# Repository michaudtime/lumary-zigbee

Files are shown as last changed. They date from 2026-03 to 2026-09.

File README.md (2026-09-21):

# Lumary Zigbee Controller

Replaces the Tuya WiFi controller inside a **Lumary 6" RGBAI recessed light** with an **ESP32-H2 Zigbee controller**, enabling:

- Direct Zigbee binding to Inovelli Blue Series switches (hub-independent on/off, dimming, scene control)
- 6 built-in lighting effects on the accent ring, with per-scene parameters stored on-device
- Zigbee OTA firmware updates via Zigbee2MQTT

## Hardware

| Component | Part |
|---|---|
| Controller | **lumary-brain rev A** — custom ESP32-H2-MINI-1 board, drop-in for the stock `KOK-AH-A172C` (see `hardware/`) |
| Target light | [Lumary Smart RGBAI Recessed Light 6"](https://www.lumarysmart.com/products/lumary-smart-recessed-light-with-gradient-auxiliary-light) |
| Switch | [Inovelli Blue Series 2-1 Zigbee](https://inovelli.com/products/zigbee-matter-blue-series-smart-2-1-on-off-dimmer-switch) |

### The two light sources

The fixture has two independent sources, and the firmware drives them as **two separate Zigbee
endpoints**, so Home Assistant sees two independent light entities rather than one:

| Source | Hardware | Driven by |
|---|---|---|
| Outer "gradient" ring | 62-pixel 5 V 3535 **RGBIC** strip, 3 colour bytes/pixel (no white die) | One data line, NZR over SPI |
| Inner white ring | 96 LEDs, 12 series × 4 parallel per colour, 2700 K + 6500 K | Two low-side PWM channels steering the driver's 380 mA |

The external `L-SD8E1` driver supplies **36.63 V constant-current** (inner white anode) and **4.7 V** (ring + logic). The board never sources the white current — it gates and steers it.

| Entity | Endpoint | Controls |
|---|---|---|
| `light.<name>_downlight` | 1 | on/off, brightness, colour temperature 2700–6500 K |
| `light.<name>_ring` | 2 | on/off, brightness, xy colour, the six effects |

> **Upgrading an already-paired fixture:** adding the second endpoint changes the device
> descriptor, and Zigbee2MQTT caches endpoints from the interview, so an already-paired fixture
> must be **re-interviewed** (Z2M frontend → device → Re-interview, or publish to
> `zigbee2mqtt/bridge/request/device/interview`) before the ring entity works. This has never been
> observed on hardware, so exactly what you'll see beforehand is unconfirmed either way -- expect
> the ring entity to be missing entirely, or present but unresponsive, until the re-interview is
> done. Newly paired fixtures just work.
>
> It is also no longer easy to check: both fixtures in service have already crossed this descriptor
> change, and a fixture that has crossed it cannot show you the before. Settling it would mean
> deliberately pairing a board on pre-2.0.0 firmware and upgrading it while watching -- worth doing
> when the remaining rev A boards are brought up, or this hedge should simply stay as written.

### Wiring (rev A board)

| ESP32-H2 Pin | Signal | Destination |
|---|---|---|
| GPIO 11 (SPI2 MOSI) | Ring data → 3.3→4.7 V buffer | `CN1.DIM` (ring DIN) |
| GPIO 4 | PWM cold white → Q1 gate | `CN1.CW-` (6500 K return) |
| GPIO 5 | PWM warm white → Q2 gate | `CN1.WW-` (2700 K return) |
| GPIO 9 | BOOT button | Bench download / BLE OTA |

> **Pin note:** GPIO 2/3/8/9/25 are ESP32-H2 strapping pins. The white PWM channels use GPIO 4/5 on rev A so the MOSFET gate pulldowns can't hold a strapping pin low at reset — the Super Mini prototype's GPIO 2/3 assignment does not carry over.

> **Level shifting:** the ring runs on the 4.7 V rail, so its data line is buffered up from 3.3 V by a `74AHCT1G125` (AHCT accepts 3.3 V as a logic high).

## Why SPI instead of RMT for the ring?

On ESP32-H2, the RMT peripheral conflicts with the Zigbee radio. Instead, SPI2 bit-encodes the single-wire NZR protocol: each NZR bit becomes 3 SPI bits (`1 → 110`, `0 → 100`) at 2.4 MHz, producing a valid 800 kHz signal on MOSI. The encoder lives in `src/pixel_encode.h`, deliberately free of ESP-IDF headers so it can be unit-tested on the host.

## Built-in Effects

These belong to the **Accent Ring** entity only — the Downlight has no effects, just on/off,
brightness and colour temperature.

| # | Name | Description |
|---|---|---|
| 1 | Warm Gradient | Warm→cool sweep rotating around the ring |
| 2 | Color Gradient | Multi-hue gradient rotating around ring |
| 3 | Breathing | Outer ring pulses in/out |
| 4 | Color Cycle | Full HSV hue rotation |
| 5 | Chase | Single lit segment travels around ring |
| 6 | Nightlight | Dim warm white outer ring only |

> **Changed in this version:** `static_white` and `static_color` are gone from the effect list.
> White is now the separate Downlight entity, and a solid ring colour is `effect: none` with a
> colour set. Automations naming either of the two removed effects need updating. Stored scenes
> are reseeded automatically — the NVS schema version bump discards the old indices rather than
> misreading them.

## Switch Control (Hub-Independent)

| Inovelli action | Behavior |
|---|---|
| 1× tap | On/Off |
| Hold up/down | Brightness |
| 2× tap up | Next effect — **via hub automation**, see below |
| 2× tap down | Previous effect — **via hub automation** |

On/off and dimming use direct Zigbee binding — **no hub required**, and they keep working if the
coordinator is down. With two fixture endpoints, the switch binds to both:

```
Bind from the Inovelli's endpoint 2 (the paddle) to BOTH fixture endpoints,
clusters genOnOff and genLevelCtrl:

  switch ep2 -> fixture ep1   (downlight)
  switch ep2 -> fixture ep2   (accent ring)
```

One tap down turns both sources off; one tap up brings both back at their own levels and colours.
This works because the Inovelli sends discrete `On`/`Off` rather than `Toggle` — verified on the
hardware. Under `Toggle`, two endpoints that had drifted into different states would diverge
further on every tap instead of converging. "Downlight only" is a Home Assistant action rather
than a switch action; remove the second binding if you would rather the ring ignored the switch.

> **Effect stepping is not hub-independent, and cannot be.** The Inovelli's multi-tap events are
> manufacturer-specific and go to the coordinator rather than to a bound light, so nothing the
> light does could make 2× tap work over pure binding. The automation reads the current
> `effect_select` and writes the next one. Not yet verified end to end (plan Task 6.4).

## Selecting an effect

Effect selection rides a **manufacturer-specific cluster (`0xFC00`)**, because nothing standard can
carry it: the Scenes cluster stores colour and level but knows nothing about an effect type, and
the Identify trigger-effects have no hook in the Arduino Zigbee library.

Install [`z2m/lumary-brain-revA.js`](z2m/lumary-brain-revA.js) into Z2M's `data/external_converters/`
and restart. Without the converter the light still works normally — the effects are simply
unreachable.

The converter exposes the effects as the **Accent Ring entity's native Home Assistant effect
list**, so they appear in the effect dropdown of the ring's light card itself rather than as a
separate entity:

```yaml
service: light.turn_on
target: {entity_id: light.lumary_kitchen_ring}
data: {effect: color_cycle}
```

That also means HA scene snapshots capture the running effect, and voice assistants can select one.
The current effect reads back as `state_attr('light.lumary_kitchen_ring', 'effect')`.

| Value | Meaning |
|---|---|
| `warm_gradient` … `nightlight` | One of the six built-in effects, in `EffectType` order |
| `none` | Not running an effect — showing a plain colour |

Setting a colour on the ring **exits the effect** and shows that colour instead, which reads back
as `none`. Selecting `none` does the same thing without changing the colour. Brightness continues
to scale whatever effect is running.

The selected effect persists across power cuts (NVS); `none` deliberately does not, so a power
cycle comes back to the stored effect.

> The Identify trigger-effects that Z2M's stock `effect` dropdown drives (`blink`, `breathe`,
> `okay`, …) are **switched off** in the converter, along with `power_on_behavior`. Both are on by
> default in `light()`, and this firmware implements neither — leaving them on would put controls in
> the light card that quietly do nothing. See `effect: false` / `powerOnBehavior: false` there.

> **Stepping through effects from the wall switch** is done by a hub automation, not by the light:
> read the current effect and set the next one. The Inovelli's multi-tap events go to the
> coordinator rather than to a bound light, so a hub is in the loop regardless.

Scene *storage* exists — 16 NVS slots, seeded with the defaults in `src/effect_params.h` — but
editing them is **not implemented**. There is no Add Scene support; `scene_store_save()` is only
called to seed defaults at first boot. Changing an effect's colour, speed or brightness
permanently is a future change.

## OTA Updates

> **Re-flashing a fixture that was already paired?** See "Upgrading an already-paired fixture"
> above — after this update it needs a Z2M **re-interview** before the ring entity works, or the
> upgrade will look broken even though it succeeded.

**Primary:** Zigbee OTA via Zigbee2MQTT.

Three things must all be true, and each one fails differently:

| Requirement | Symptom when missing |
|---|---|
| Firmware registers an OTA client | Device never asks; nothing in the Z2M log |
| Converter declares `ota: true` | **No `update` entity at all** in Home Assistant |
| Z2M can find the image via an index | Update entity exists; update fails `No image currently available` |

> **Z2M does not discover firmware by scanning a folder.** Copying a `.zigbee` file into `data/ota/`
> accomplishes nothing on its own — Z2M reads an *index* that describes the image, pointed at by
> `ota.zigbee_ota_override_index_location` in `configuration.yaml`. `scripts/gen-ota-index.py`
> generates one; see "Building an OTA image" below.

> **`ota` is a definition property, not a modern extend.** There is no `m.ota()` in
> zigbee-herdsman-converters, and using one makes Z2M reject the entire converter as invalid at load
> time. It goes on the definition object alongside `onEvent`.

**There is no fallback.** A BLE OTA path was planned — `PIN_BLE_OTA_BUTTON` is still defined in
`src/config.h` — but it was never implemented, and nothing references that pin. Do not count on it
for a fixture already in the ceiling: if Zigbee OTA cannot reach a light, the only recovery is
physical access to the USB port. Getting Zigbee OTA verified from an installed location is
consequently the gate on signing off the board (plan task 6.4), not a nice-to-have.

### Scheduled updates and automatic recovery (2.1.0 and later)

**Start updates with *schedule*, not *update*:**

```
topic:   zigbee2mqtt/bridge/request/device/ota_update/schedule
payload: {"id": "Loft Overhead Light"}
```

> **This means not using the Install button on Home Assistant's update card.** That button is the
> `ota_update/update` path: Zigbee2MQTT pushes an image notify at the fixture and waits for it to
> answer, which for a fixture a floor away from the coordinator typically ends in
> `OTA update of '<name>' failed (Device didn't respond to OTA request)` — a failure that says
> nothing about the image or the index. `schedule` parks the request instead and lets the fixture
> collect it on its own next query, which is what the recovery loop below is built around. Seen
> 2026-09-21 on the loft fixture: Install failed this way, the same image then installed from a
> schedule.
>
> `check`, `update` and `schedule` share one per-device lock, so a `schedule` sent while either of
> the others is still running is rejected with
> `OTA update or check for update already in progress for '<name>'`. Wait for the first to finish
> and send it again.

The fixture queries for an image shortly after it joins the network at boot, then hourly. A
scheduled update starts on whichever of those queries comes next, and Zigbee2MQTT keeps it
scheduled if it fails. Combined with the firmware's recovery this makes an update self-healing:

1. If a download aborts, or stalls for 3 minutes, the fixture saves its light state, restarts
   (the light blinks for about a second, then comes back as it was), and rejoins.
2. On rejoin it queries for an image, and the still-scheduled update starts again from the
   beginning.
3. When it succeeds, the fixture restarts into the new version and comes back **off** -- light
   state is only carried across a recovery restart, not across the update's own restart -- and
   Zigbee2MQTT clears the schedule.

The restart itself backs off on repeated recoveries: the first two consecutive recoveries restart
at once, but from the third the restart waits 5 minutes, doubling each time up to an hour, so an
image that fails the same way every time cannot make a fixture blink every few seconds. It never
stops retrying on its own -- `unschedule` is what stops it.

The restart is required: the Arduino Zigbee library never resets its OTA state after an abort, so
without it every retry fails `INVALID_IMAGE` two blocks in. To stop a fixture retrying an image that
can never succeed, send the same payload to `.../ota_update/unschedule`. Each recovery is logged on
the serial console with a running count.

**Fixtures on firmware older than 2.1.0** have no automatic recovery: after a failed update, power-
cycle the fixture before retrying. From Home Assistant, via its Inovelli switch: turn the switch
off, set its Smart Bulb Mode to `Disabled` (the switch is off, so the load loses power), wait ~15 s,
then set Smart Bulb Mode back to `Smart Bulb Mode` (full power returns and the fixture boots).

### Building an OTA image

The device registers an OTA client at startup and queries for an image once it
joins, then hourly. The coordinator only offers images numbered **above** the
running version, so the version block in `src/version.h` must be bumped and the
same `ZB_FW_VERSION` passed as `--file-version` below — if they disagree, the
update silently never appears.

> **The tool was renamed and its CLI changed.** Espressif's `tools/ota_image_tool.py`
> is gone; it is now `tools/image_builder_tool/image_builder_tool.py`, it takes short
> flags rather than the old long ones, and the firmware is supplied as a `--tag`
> sub-element rather than a positional argument. There is no `create` subcommand, and
> the output filename is generated for you rather than given. Verified 2026-08-18.

```bash
# Get the tool
mkdir -p build/ota && curl -sSL -o build/ota/image_builder_tool.py   https://raw.githubusercontent.com/espressif/esp-zigbee-sdk/main/tools/image_builder_tool/image_builder_tool.py

# Build firmware (bump the version block in src/version.h first)
pio run -e esp32h2

# Wrap as an OTA image. -m/-i come from src/config.h (ZB_MANUFACTURER_CODE,
# ZB_IMAGE_TYPE); -v must equal ZB_FW_VERSION. Tag 0x0000 is the upgrade image.
cd build/ota && python image_builder_tool.py   -m 0x1001   -i 0x0001   -v 0x02000000   -s 2   -g "LumaryZigbee"   --tag 0x0000 ../../.pio/build/esp32h2/firmware.bin
```

The output is named from the three identifiers rather than chosen — for the values above,
`1001-0001-02000000-ota-file.zigbee`.

Then generate the index Z2M actually reads. It takes the manufacturer code, image type, file version
and header string out of the image itself rather than from arguments, so the index cannot disagree
with the file it describes:

```bash
python scripts/gen-ota-index.py build/ota/1001-0001-02000000-ota-file.zigbee
```

Copy **both** the `.zigbee` image and the generated `index.json` into Z2M's `data/ota/` folder, then
point `configuration.yaml` at the index and restart Z2M:

```yaml
ota:
  zigbee_ota_override_index_location: ota/index.json
```

Both paths are relative to the **Z2M data directory** — the index's own location, and the `url`
inside it naming the image. Verified end to end 2026-08-18 against Z2M 2.13.0: no http(s) URL and no
absolute path is needed for a locally served image.

> **The `url` is relative to the data directory, not to the index that contains it.** With the
> layout above the index lives at `data/ota/index.json` and the image sits beside it, so the `url`
> still needs the `ota/` prefix — `ota/foo.zigbee`, not `foo.zigbee`. `gen-ota-index.py` adds it.
>
> Getting this wrong is worth recognising, because it does not look like a path problem.
> `ota_update/check` reads index *metadata* only, so it reports `update_available: true` and Home
> Assistant offers the update quite happily. Only `ota_update/update` opens the file, and it reports
> the failure as **`No image currently available`** — the same message you get with no index at all.
> The real cause appears only in Z2M's debug log:
>
> ```
> zh:controller:ota: Reading firmware image from 'foo.zigbee'
> ENOENT: no such file or directory, open '/config/zigbee2mqtt/foo.zigbee'
> ```

Z2M caches the last OTA check, so after installing an index it will keep reporting the device as up
to date until it re-checks — on the next device announce, hourly, or immediately if you ask:

```
topic:   zigbee2mqtt/bridge/request/device/ota_update/check
payload: {"id": "Overhead light test"}
```

For a one-off test you can skip the index entirely and name the file in the update request, which is
useful for confirming the image itself is good before troubleshooting configuration:

```
topic:   zigbee2mqtt/bridge/request/device/ota_update/update
payload: {"id": "Overhead light test", "url": "ota/1001-0001-02000000-ota-file.zigbee"}
```

`build/` is git-ignored, so neither the tool, the image, nor the index is committed.

## Build & Flash

> **Re-flashing a fixture that was already paired?** See "Upgrading an already-paired fixture"
> above — after this update it needs a Z2M **re-interview** before the ring entity works, or the
> upgrade will look broken even though it succeeded.

> **Windows:** run `pio` from **PowerShell or cmd**, not Git Bash. This platform
> version installs its toolchain via `idf_tools.py`, which aborts with
> `ERROR: MSys/Mingw is not supported` under Git Bash. Building also needs
> Windows long-path support enabled (`LongPathsEnabled = 1`).
>
> `--target upload` fails differently and much more confusingly under Git Bash:
> esptool's progress bar is drawn with box-drawing characters, stdout falls back
> to **cp1252**, and the whole upload dies on `UnicodeEncodeError: 'charmap'
> codec can't encode characters` — after sitting silent for ~6 minutes, with the
> traceback replacing whatever the real error was. The board is fine; nothing was
> written. From PowerShell the same flash takes ~18 s. If you must run it from a
> shell with a non-UTF-8 codepage, `chcp 65001` and `PYTHONIOENCODING=utf-8`
> clear it (observed 2026-09-21).

```bash
# Install PlatformIO CLI if needed
pip install platformio

# Build
pio run -e esp32h2

# Flash
pio run -e esp32h2 --target upload

# Serial monitor
pio device monitor
```

## Project Structure

```
src/
  config.h          — Pin definitions, constants
  color.h           — CRGB struct, HSV conversion, color math
  pixel_encode.h    — NZR-over-SPI bit encoder (hardware-free, unit-tested)
  led_driver.h/.cpp — SPI2 ring driver + LEDC CW/WW PWM
  effect_params.h   — EffectType enum, EffectParams struct
  effects.h/.cpp    — 6 effect implementations + lookup table
  scene_store.h/.cpp — NVS scene persistence
  zigbee_light.h/.cpp — Zigbee clusters for both endpoints, and the OTA client
  brightness.h      — CIE 1931 lightness curve, generated tables
  main.cpp          — Setup, loop, watchdog
test/
  test_brightness/   — Host unit tests for the perceptual curve
  test_identify/     — Host unit tests for the identify overlay
  test_light_state/  — Host unit tests for the Zigbee -> fixture translation
  test_pixel_encode/ — Host unit tests for pixel encoding + color math
  test_version/      — Host unit tests for the version block
z2m/
  lumary-brain-revA.js — Z2M external converter
  test/             — Converter tests (stubbed, `node z2m/test/converter.test.mjs`)
hardware/
  kicad/            — Board design (build_board.py generates the .kicad_pcb)
  bom.csv, calcs.md, schematic-nets.md
docs/
  spec.md           — Hardware + software design specification
  plan.md           — Implementation plan
  superpowers/      — Board replacement spec, plan, and Phase 0 measurements
```

## Tests

Hardware-independent logic (pixel encoding, colour math) has host-side unit tests:

```bash
scripts\run-native-tests.bat
```

> PlatformIO's `platform = native` expects a gcc toolchain; this script compiles the
> same tests with the MSVC Build Tools that are installed instead. `pio test -e native`
> works as-is on a machine with gcc.

The Z2M converter has its own suite, covering the effect names, their wire indices and the
exposes Home Assistant discovers from them. It stubs the `zigbee-herdsman-converters` imports,
so it needs nothing installed but Node:

```bash
node z2m/test/converter.test.mjs
```

## Status

- [x] Design spec
- [x] Implementation plan
- [x] Task 1: Project scaffold
- [x] Task 2: Color utilities
- [x] Task 3: LED driver
- [x] Task 4: Scene storage
- [x] Task 5: Effects engine
- [x] Task 6: Zigbee basics
- [x] Task 7: Zigbee color + effect selection
- [x] Task 8: Zigbee OTA
- [ ] Task 9: BLE OTA fallback -- won't do (decided 2026-08-19); see "OTA Updates" above
- [ ] Task 10: Integration + validation -- bench-verified end to end
      (`docs/superpowers/plans/2026-08-18-bench-verification.md`, §§1-9), and **signed off from an
      installed ceiling location 2026-09-19**: binding to the Inovelli confirmed from the loft at
      LQI 126-138, and a real over-the-air update completed from there (Task 6.4 in
      `docs/superpowers/plans/2026-08-01-brain-replacement-board.md`). Still open: the
      already-paired-fixture upgrade path -- see the note under "Two entities" above, which now
      needs a fixture deliberately left on pre-2.0.0 firmware to observe at all
      (RSSI, thermals, a real OTA from there)

## License

MIT

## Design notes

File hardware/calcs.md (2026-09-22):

# Lumary Brain Board — Engineering Calculations

Inputs from `docs/superpowers/research/phase0-measurements.md`.
Rails: `+36V` = 36.63 V constant-current (380 mA), `+4V7` = 4.7 V logic/ring, `GND`.

---

## Task 1.1 — Power-path calculations

### 3.3 V rail (ESP32-H2-MINI-1)
- Design load: **200 mA** headroom (H2 active radio + flash-write bursts; steady draw is lower).
- LDO dissipation:
  - from USB 5 V:  (5.0 − 3.3) × 0.20 = **0.34 W**
  - from +4V7:     (4.7 − 3.3) × 0.20 = **0.28 W**
- Dropout requirement: at +4V7 in, LDO dropout must be **< 1.4 V @ 200 mA** → pick a low-dropout part (rules out marginal AMS1117-class at this headroom).
- Thermal: 0.34 W in SOT-23-5 (θJA ≈ 200 °C/W) → ~68 °C rise worst case → OK with a modest copper pour.
- **VERDICT: PASS** (≤ 0.5 W). LDO from a diode-OR of (+4V7, USB-VBUS) so the board runs installed *and* boots on USB alone at the bench.

### Outer-ring current budget (risk R3)
- 62 px, 3535 RGBIC (RGB). Per-pixel full-white ≈ 3 × ~6 mA ≈ **~18 mA** (3535 is lower-power than 5050); worst-case ≈ 62 × ~20 mA ≈ **1.24 A** at ~5 V.
- The driver's `+4V7` rail spare capacity is **unknown** (input 24 W − 13.6 W white ≈ ~10 W gross, minus efficiency → order of ~1 A, unconfirmed).
- **Conclusion:** full-brightness all-white on 62 px would exceed the rail. **Firmware brightness cap is mandatory** (already present as `BENCH_BRIGHTNESS`). Quantify the safe average once the rail's real limit is measured; keep the cap conservative until then.
- **MEASURED 2026-08-15** (rev A, bench supply on `+4V7`, module powered from USB so excluded):
  - 62 px dark, quiescent: **0.040 A** (~0.65 mA/px)
  - 62 px at `(24,14,14)` (`MAX_BRIGHTNESS` 24, sat 40%): **0.122 A**
  - → LED current 0.082 A for 52 of 765 channel-units, i.e. **~1.5 mA per unit across the ring**
  - → extrapolated full white at full brightness: **1.21 A**, against the 1.24 A predicted above.
    The per-pixel 3535 estimate is **confirmed to within 3%**.
  - → full white at the current cap of 24: **~0.15 A**, not the ~0.55 A previously assumed.
  - **Implication:** against the 0.74 A trace limit the cap could rise to roughly 100 on paper.
    Not acted on — the measurement is open-air, the fixture is a sealed can, and the driver's
    `+4V7` rail spare capacity is still unmeasured (see R3 above). Revisit after plan Task 6.4.
  - **Rev B update:** `+4V7`/`+4V7_IN` were widened to 0.5 mm where the layout allowed it (see
    "As-built trace widths (rev B)" below), but three short necks could not be widened without a
    reroute and stay at 0.2 mm. **A path is limited by its narrowest section, so the ring supply's
    trace limit is still ~0.74 A — the widening did not raise it.** It bought lower resistance
    (~60 mΩ, ~35 mV at the 0.55 A the path actually draws), not headroom, and it does **not**
    change this brightness-cap discussion: the 0.74 A ceiling above is unchanged.

### Inner white sink (from P0.5)
- Headroom ≈ 0.6 V, sink current 380 mA → **≈ 0.23 W per channel**, one color full at a time.
- **VERDICT: PASS**, trivial thermals (see Task 1.2).
- **MEASURED 2026-08-15** (rev A on the real L-SD8E1, `Q2` at 380 mA/100% duty for 15 min,
  thermal camera, 23.3 °C ambient, open air):
  - `Q2` **37 °C** (Δ13.7 °C) → effective **θJA ≈ 60 °C/W**, against ~250 °C/W for a bare SOT-23
    in free air. The copper pour around Q1/Q2 is carrying the heat as hoped.
  - `U2` (LDO) **40 °C** (Δ16.7 °C) — the hottest point on the whole board, not the white sinks.
    Measured from USB (5 V → 3.3 V); installed it runs from +4V7 and dissipates ~20% less.
  - **Risk R1 cleared.** Caveat: open-air bench. The sealed ceiling can raises ambient, so the
    deltas hold but absolutes will be higher — confirm in-fixture (plan Task 6.4).
  - **White LED strip itself: 54 °C** at 100% duty, loose on the bench. It dissipates the whole
    ~13.7 W (380 mA × ~36 V); the board only gates that current and never sources it, which is
    why Q1/Q2 stay near ambient by comparison. Unremarkable for the part, and identical to what
    the stock controller produced since the driver's 380 mA CC output is unchanged. Installed it
    bolts to the aluminium can and is heatsinked better than on a bench.

### `+4V7` trace characterisation — MEASURED 2026-08-15

Two separate runs, kept separate rather than merged into one table. The pixels' thermal
self-limiting (see Run 1) means readings taken at different strip temperatures are not
directly comparable, so combining them would average away the very effect that matters.

#### Run 1

Ring fed from a current-limited bench supply (4.7 V, 0.9 A) with the 36 V side disconnected;
`MAX_BRIGHTNESS` temporarily raised to 200; colour held at saturation 40% (`rgb 255,154,154`,
≈73% of full-white current, since `sat`=0 routes to the white string and cannot light the ring).

| Brightness | Rail current | Trace temperature |
|---|---|---|
| 24 (today's ceiling) | 0.119 A | no rise detectable |
| 60 | 0.236 A | none |
| 100 | 0.346 A | none |
| 140 | 0.462 A | none |
| 180 | 0.431 A ← *lower* | none |
| 140 (repeat, later) | **0.400 A** vs 0.462 A first time | none |

**Trace: no measurable heating anywhere in the usable range.** Predicted rise at 0.46 A is only
~4 °C (I² against the 0.74 A / 10 °C design point), which is near a thermal camera's noise floor
for a 0.2 mm trace under solder mask, so this is consistent with the model rather than a
refutation of it. The trace is not the binding constraint it was assumed to be.

**Series resistance:** 4.70 V at the supply vs **4.49 V at the ring** under 0.431 A → **≈0.49 Ω**
total for trace + `Q3` + flying leads + joints. The trace alone accounts for ~0.19 Ω
(77 mm of 0.2 mm, 1 oz). 4.49 V is still ample for the pixels, so droop did **not** limit current.

**The pixels self-limit thermally.** Repeating brightness 140 after several minutes gave 0.400 A
against 0.462 A when first measured, a 13% fall, with the strip at 36 °C (ambient 23.3 °C). These
parts set their per-die current from an internal reference with a negative tempco, so current
falls as they warm. Consequences:
- **Worst case is a cold start at full brightness**, not sustained running. Any current budget must
  be taken from cold.
- Every figure in the table understates cold current by an unknown amount, since each was taken at
  a different strip temperature.

**Implication for `MAX_BRIGHTNESS`:** at brightness 140 — nearly 6× today's ceiling — the ring drew
0.46 A warm, and full white would be ≈0.63 A, still under the 0.74 A rating. A ceiling well above
24 looks defensible on trace thermals alone. **Not yet acted on**, for two reasons: this was an
open-air bench at 23 °C and the fixture is a sealed can, and the ring rail in service comes from the
L-SD8E1 whose spare 4.7 V capacity is still unknown (see R3 above). Settle both in Task 6.4.

#### Run 2 — swept to full scale

Same rig later the same day, PSU limited to 0.8 A and `MAX_BRIGHTNESS` lifted to 255 so the sweep
reaches the top of the scale. The strip was **already warm** entering this run, from Run 1 and from
the Task 6.3 thermal hold, so by Run 1's own finding these figures sit *below* a cold-start
equivalent.

| Brightness | Rail current | Trace temperature |
|---|---|---|
| 24 (today's ceiling) | 0.120 A | no rise detectable |
| 64 | 0.248 A | none |
| 128 | 0.393 A | none |
| 192 | 0.438 A | none |
| **255 (full scale)** | **0.480 A** | **none** |

- **Full brightness reached: 0.480 A** — the most the ring can draw at this colour — with still no
  measurable trace heating.
- **`J1` measured 4.74 V under full load**, i.e. no sag at the board's input. Taken with Run 1's
  4.49 V at the ring, the ~0.25 V lost sits *between* `J1` and the strip — trace, `Q3`, flying
  leads and hand-soldered joints — and none of it upstream of the board. The flying leads are a
  bench artefact and would not exist in a properly connectorised build.
- Current flattens above brightness ~128, consistent with Run 1's thermal self-limiting rather
  than with any rail limitation.

#### Run 3 — cold start at full brightness

Run to settle the one thing Runs 1 and 2 could not: whether a cold strip draws more than a warm
one, which would make every earlier figure an underestimate. Strip cooled to **30 °C against a
29 °C background** — a genuine cold start, within a degree of ambient. (Ambient itself had drifted
from 23.3 °C that morning to 29 °C by mid-afternoon.) Brightness 255, saturation 40%, as before.

| Moment | Rail current | Strip temp |
|---|---|---|
| Peak, instant of turn-on | **0.480 A** | 30 °C |
| 30 s | 0.480 A | — |
| 2 min | 0.480 A | 34 °C |

**No cold-start peak, and no decay.** Current held at 0.480 A across a 30 → 34 °C rise, and it is
the same figure Run 2 measured on an already-warm strip. Highly reproducible and, over this range,
insensitive to thermal state.

**This does not reproduce Run 1's 13% self-limiting**, and re-reading those numbers the first
reading looks like the outlier rather than the second:

| | Current |
|---|---|
| Run 1, brightness 140, first reading | 0.462 A |
| Run 1, brightness 140, repeat | **0.400 A** |
| Run 2, brightness 128 | 0.393 A |
| Run 2, brightness 192 | 0.438 A |

The Run 1 *repeat* falls neatly on the Run 2 curve between brightness 128 and 192; the *first*
reading is the one that fits nothing. Settling time or a mis-set brightness is a likelier
explanation than a thermal droop that Run 3 cannot reproduce at all. Treat the negative-tempco
conclusion as **not supported** — though note Run 3 only spans 30 → 34 °C, so a much larger
excursion (a sealed can at full output) has still never been tested.

**Combined conclusion.** Across three runs the trace never showed measurable heating at any
brightness up to full scale, and the largest current ever seen was **0.480 A against a 0.74 A
rating** — reproducible cold or warm. Full *white* extrapolates to ~0.66 A (÷0.73), still under
the rating, though that scaling is unverified and is probably an over-estimate given how hard the
current saturates with brightness. The 0.2 mm trace is **not** what should be setting
`MAX_BRIGHTNESS`.

Still not acted on, but only one reason now survives: **the L-SD8E1's spare 4.7 V capacity is
unmeasured.** Every figure here came from a bench PSU, while in service that rail must carry the
ring *and* the module. Settle it in Task 6.4, along with sealed-can ambient.

---

## Task 1.2 — White-driver topology decision

**REVISED (approved):** the external driver is a confirmed **constant-current** source (380 mA),
so the board does **not** need to regulate current — it only needs to **gate** each channel.
The stock board used linear CC (`HT7308`) because it did *analog* dimming via the `A08G` op-amp;
we dim **digitally by PWM from the ESP32**, so simple switches suffice.

- **CHOSEN: 2× logic-level N-MOSFET low-side switches** (`Q1`=CW/GPIO2, `Q2`=WW/GPIO3), common
  anode at `+36V`. No current-regulation, no sense resistors — the driver sets the 380 mA.
- Brightness = PWM duty on both switches; color temperature = cool:warm duty ratio.
- **+ 36 V bulk cap `C1` (10 µF/50 V):** absorbs turn-on inrush when a channel switches (mirrors
  the stock 4.7 µF/50 V caps). When both channels are off, the CC driver rails to its 35.8 V
  compliance — this cap holds the rail, and the MOSFETs must block it.
- **Ratings:** MOSFET Vds must withstand the 35.8 V compliance → spec **≥ 60 V**, logic-level
  (fully on at 3.3 V gate), Id ≥ 0.5 A (carries the full 380 mA when on).
- Thermal: MOSFET on-state loss = I²·Rds(on) ≈ 0.38² × ~0.1 Ω ≈ **1.5 mW** — negligible.

**Firmware note (Phase 6):** a CC driver may not track 20 kHz output PWM cleanly; plan to lower
`PWM_FREQ_HZ` to ~500 Hz–2 kHz during bring-up and verify flicker-free low-end dimming.

**VERDICT:** topology = MOSFET low-side switches + 36 V bulk cap; devices ≥ 60 V logic-level. PASS.

---

## Task 1.4 — ESP32-H2 pin assignments

ESP32-H2 **strapping pins = GPIO2, GPIO3, GPIO8, GPIO9, GPIO25**; **USB = GPIO26 (D−), GPIO27 (D+)**.

⚠️ **Conflict found:** the current firmware drives **CW=GPIO2** and **WW=GPIO3** — both are
**strapping pins**. Our MOSFET gate pulldowns would hold them low at reset, risking boot-mode
issues. On the new board we **move CW/WW off the strapping pins**.

| Function | Old (Super Mini fw) | New board | Note |
|---|---|---|---|
| RGBIC ring data | GPIO11 | **GPIO11** | OK (not strapping); SPI2-MOSI via GPIO matrix |
| CW PWM (Q1 gate) | GPIO2 ⚠️ | **GPIO4** | moved off strapping |
| WW PWM (Q2 gate) | GPIO3 ⚠️ | **GPIO5** | moved off strapping |
| BOOT button | GPIO9 | **GPIO9** | strapping = download-mode select (correct use) |
| Reset | — | **EN** pin | dedicated |
| USB D− / D+ | — | **GPIO26 / GPIO27** | native USB-Serial-JTAG |

- **Verify (Task 2.6/layout):** GPIO4, GPIO5, GPIO11 are broken out on MINI-1 and free of analog-only limits.
- **Firmware (Phase 5, Task 5.1):** `PIN_CW_PWM` 2→**4**, `PIN_WW_PWM` 3→**5**; `PIN_SK6812_DATA` stays 11.

## As-built trace widths (rev A) — found after routing

KiCad discarded the `Power` net class when it rewrote `lumary-brain.kicad_pro` on
first open, so **every net on rev A routed at the 0.2 mm Default**, not the 0.5 mm
intended for the power nets. The Gerbers were generated from that board, so this is
what shipped. The class has since been restored in the project file for rev B.

IPC-2221, external layer, 1 oz copper: a 0.2 mm trace carries **0.74 A** at a 10 °C
rise (1.01 A at 20 °C).

| Path | Current | Rise | Drop | Verdict |
|---|---|---|---|---|
| `+36V`, `CW_RET`, `WW_RET` (white string) | 380 mA | 2.2 °C | 37 mV | **fine** — the CC driver fixes this current, it cannot grow |
| `+4V7_IN` at `MAX_BRIGHTNESS` 24 (ring 0.35 A + module 0.2 A) | 550 mA | 5.0 °C | 60 mV | **fine** |
| `+4V7_IN` if brightness were raised to 255 | ~1.5 A | **49 °C** | 164 mV | **not acceptable** |

**Consequence for firmware:** `MAX_BRIGHTNESS` in `main.cpp` is a *hardware* limit on
rev A, not just a USB-bench convenience. The ceiling that keeps `+4V7_IN` inside its
10 °C rise is about **37**; it is currently set to 24, which leaves comfortable margin.
Do not raise it toward 255 on a rev A board.

**Rev B fix (done, see below):** `+4V7`/`+4V7_IN` were widened to 0.5 mm where the layout
allowed it; three short necks could not be widened and stay at 0.2 mm. The white path
(`+36V`, `CW_RET`, `WW_RET`) stayed at 0.2 mm as planned — 380 mA is fixed by the
constant-current driver and barely warms the copper.

## As-built trace widths (rev B) — final state

Of the eight power nets, only `+4V7` and `+4V7_IN` ended up wide. `+36V`, `CW_RET` and `WW_RET`
carry a fixed 380 mA from the constant-current driver, and `+3V3`, `VBUS`, `LDO_IN` are module
rails drawing ~0.2 A — all six sit comfortably inside the 0.74 A a 0.2 mm/1oz trace supports at a
10 °C rise. Widening them anyway (putting all eight in the `Power` net class) caused 25 of 28 DRC
clearance violations on this dense a board, so those six were reverted to 0.2 mm.

| Net | Width / length | Width / length |
|---|---|---|
| `+4V7` | 0.50 mm / 19.9 mm | 0.20 mm / 4.7 mm |
| `+4V7_IN` | 0.50 mm / 43.0 mm | 0.20 mm / 1.5 mm |
| `+36V` | 0.20 mm / 36.5 mm | — |
| `CW_RET` | 0.20 mm / 20.5 mm | — |
| `WW_RET` | 0.20 mm / 19.9 mm | — |
| `+3V3` | 0.20 mm / 37.3 mm | — |
| `VBUS` | 0.20 mm / 44.2 mm | — |
| `LDO_IN` | 0.20 mm / 14.3 mm | — |

**Three necks remain at 0.2 mm** on the two wide nets, by segment uuid:

| Net | uuid | Length | Where |
|---|---|---|---|
| `+4V7` | `093f2bea-3ab4-4dff-b0e2-51206501ee48` | 3.960 mm | past C7's GND pad / `RING_BUF_OUT` |
| `+4V7` | `42b96ee6-5c65-4627-a6d6-a193a0d3b025` | 0.760 mm | same pinch |
| `+4V7_IN` | `d1f966ed-de48-4950-b8fd-b16de4800a93` | 1.500 mm | past J3's shield pad |

**The honest consequence: the ring supply path's IPC limit is still ~0.74 A. The widening did NOT
raise it** — a path is limited by its narrowest section, and these three necks are still 0.2 mm.
What it did buy is roughly 60 mΩ less resistance, about 35 mV at the 0.55 A the path actually
draws (`+4V7_IN` at today's brightness cap: 0.35 A ring + 0.2 A module, the 550 mA row in the rev
A table above). 0.74 A remains comfortably above that 0.55 A draw — the same margin rev A had.

The necks cannot be widened without rerouting `RING_BUF_OUT` out of that corner: it threads
between the `+4V7` diagonal and Q2's ground pad through a corridor ~0.50 mm wide, where a 0.2 mm
track with 0.2 mm clearance either side needs 0.60 mm. That reroute was offered and declined for
now — revisit if the 0.74 A ceiling ever needs to move.

**This does not raise the brightness cap.** `J2`'s contacts are rated 1 A each, and the driver's
`+4V7` rail spare capacity has never been measured (see "Open numeric items" below) — neither of
those changed with this widening, and the trace was never the only constraint in the first place.

---

## Open numeric items (not blocking Phase 1)
- Measure the `+4V7` rail's real current limit → set the firmware brightness cap precisely (risk R3).
- Confirm final MOSFET part meets ≥60 V / logic-level / ≥0.5 A and is JLCPCB-stocked (Task 1.3 verify).

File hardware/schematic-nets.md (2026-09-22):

# Lumary Brain Board — Schematic Net Tables

Source of truth for the KiCad schematic (Phase 2). Designators match `bom.csv`.
Enter these connections in Eeschema, then run ERC (Task 2.6).

**IC pin references:** module pins by signal name (MINI-1 KiCad symbol uses names);
discrete ICs by pin number where standard, else "per symbol/datasheet" — verify against the
placed KiCad symbol during Task 2.6.

---

## Net dictionary

| Net | Meaning |
|---|---|
| `GND` | Common ground (single plane) |
| `+36V` | Constant-current white-string rail (from driver, 36.63 V) |
| `+4V7_IN` | 4.7 V as it enters the board (pre reverse-polarity FET) |
| `+4V7` | Protected 4.7 V board rail (ring power + logic) |
| `LDO_IN` | Diode-OR node feeding the 3.3 V LDO |
| `+3V3` | Module rail |
| `VBUS` | USB-C 5 V (bench only) |
| `USB_DP` / `USB_DM` | USB D+ / D− (shared: connector ↔ ESD ↔ module) |
| `EN` | Module enable/reset |
| `IO9` | Module boot/download-select |
| `CW_PWM` / `WW_PWM` | GPIO → gate-resistor (pre-resistor) |
| `CW_GATE` / `WW_GATE` | MOSFET gates (post gate-resistor) |
| `CW_RET` / `WW_RET` | White cathode returns (`CN1.CW-` / `CN1.WW-`) |
| `RING_DATA_3V3` | GPIO11 ring data at 3.3 V (buffer input) |
| `RING_BUF_OUT` | Buffer output (pre damping-resistor) |
| `RING_DATA` | Level-shifted 4.7 V ring data to `CN1.DIM` |
| `CC1` / `CC2` | USB-C configuration-channel pulldowns |

---

## Task 2.1 — Power block

| Component.Pin | Net |
|---|---|
| J1.1 (GND) + solder-pad | `GND` |
| J1.2 (36V) + solder-pad | `+36V` |
| J1.3 (4V7) + solder-pad | `+4V7_IN` |
| Q3 (AO3401A P-FET) Source | `+4V7_IN` |
| Q3 Drain | `+4V7` |
| Q3 Gate | `GND` (via R… see note) |
| D3 (SMAJ5.0A TVS) cathode | `+4V7_IN` |
| D3 anode | `GND` |
| C4 (10 µF) | `+4V7` ↔ `GND` |
| D1 (B5819W) anode | `+4V7` |
| D1 cathode | `LDO_IN` |
| D2 (B5819W) anode | `VBUS` |
| D2 cathode | `LDO_IN` |
| C3 (1 µF) | `LDO_IN` ↔ `GND` |
| U2 (ME6211) VIN (pin1) | `LDO_IN` |
| U2 GND (pin2) | `GND` |
| U2 EN/CE (pin3) | `LDO_IN` (always-on) |
| U2 NC (pin4) | — |
| U2 VOUT (pin5) | `+3V3` |
| C2 (10 µF) | `+3V3` ↔ `GND` |

**Reverse-polarity note:** AO3401A high-side P-FET — Source=`+4V7_IN`, Drain=`+4V7`, Gate to
`GND` through a 100 k (add as R8 during entry) so it turns on for correct polarity and blocks
reversed input. The ring current flows through it (AO3401A ≤4 A, fine).

**ERC 2.1:** `+3V3` driven by U2 (1 driver); `LDO_IN` driven by D1/D2 (OR, no back-drive — Schottkys
isolate `+4V7` from `VBUS`); `+36V` touches only J1, C1 (Task 2.4), J2 (Task 2.4) — never `+3V3`/USB. **PASS.**

---

## Task 2.2 — MCU + USB block

| Component.Pin | Net |
|---|---|
| U1 (ESP32-H2-MINI-1) 3V3 (all) | `+3V3` |
| U1 GND (all + thermal pad) | `GND` |
| U1 EN | `EN` |
| U1 IO9 | `IO9` |
| U1 GPIO26 (USB_D−) | `USB_DM` |
| U1 GPIO27 (USB_D+) | `USB_DP` |
| U1 GPIO4 | `CW_PWM` |
| U1 GPIO5 | `WW_PWM` |
| U1 GPIO11 | `RING_DATA_3V3` |
| C5 (10 µF) | `+3V3` ↔ `GND` (bulk, near module) |
| C6 (100 nF) | `+3V3` ↔ `GND` (HF, at module pin) |
| R6 (10 k) | `EN` ↔ `+3V3` (pullup) |
| C8 (1 µF) | `EN` ↔ `GND` (power-on delay) |
| SW2 | `EN` ↔ `GND` (reset button) |
| SW1 | `IO9` ↔ `GND` (download button; module has internal pullup) |
| J3 (USB-C) VBUS (A4/B4/A9/B9) | `VBUS` |
| J3 GND (A1/B1/A12/B12) + shield | `GND` |
| J3 D+ (A6+B6) | `USB_DP` |
| J3 D− (A7+B7) | `USB_DM` |
| J3 CC1 (A5) | `CC1` |
| J3 CC2 (B5) | `CC2` |
| R7a (5.1 k) | `CC1` ↔ `GND` |
| R7b (5.1 k) | `CC2` ↔ `GND` |
| U4 (USBLC6-2SC6) I/O1 | `USB_DP` |
| U4 I/O2 | `USB_DM` |
| U4 VBUS pin | `VBUS` |
| U4 GND | `GND` |

**Notes:** USBLC6 is a shunt ESD array — its I/O pins sit *on* the D+/D− nets (connector and module
share each net), clamping to `VBUS`/`GND` internally. No series resistors on D+/D−. Confirm U4 pin
numbers against the KiCad symbol (I/O1, GND, I/O2, VBUS ordering varies by symbol).

**ERC 2.2:** `+3V3` decoupled (C5+C6); `EN` has pullup+cap+button; `USB_DP`/`USB_DM` each = exactly
one MCU pin + connector + ESD (no contention); CC pulldowns present; USB uses GPIO26/27 per Task 1.4. **PASS.**

---

## Task 2.3 — Ring data output

| Component.Pin | Net |
|---|---|
| U1 GPIO11 | `RING_DATA_3V3` |
| U3 (74AHCT1G125) A / IN (pin2) | `RING_DATA_3V3` |
| U3 /OE (pin1) | `GND` (always enabled) |
| U3 GND (pin3) | `GND` |
| U3 Y / OUT (pin4) | `RING_BUF_OUT` |
| U3 VCC (pin5) | `+4V7` |
| C7 (100 nF) | `+4V7` ↔ `GND` (at U3) |
| R5 (200 R) pin1 | `RING_BUF_OUT` |
| R5 pin2 | `RING_DATA` |
| J2 (CN1) DIM | `RING_DATA` |

**ERC 2.3:** buffer VCC = `+4V7` (not +3V3 — correct for 4.7 V logic high); input driven by GPIO11;
output → series R → CN1 data; /OE tied active. **PASS.**

---

## Task 2.4 — White low-side switches + 36 V

| Component.Pin | Net |
|---|---|
| R1 (100 R) pin1 | `CW_PWM` |
| R1 pin2 | `CW_GATE` |
| R2 (100 R) pin1 | `WW_PWM` |
| R2 pin2 | `WW_GATE` |
| Q1 (N-FET) Gate (pin1) | `CW_GATE` |
| Q1 Source (pin2) | `GND` |
| Q1 Drain (pin3) | `CW_RET` |
| R3 (100 k) | `CW_GATE` ↔ `GND` (pulldown, hold off at boot) |
| Q2 (N-FET) Gate (pin1) | `WW_GATE` |
| Q2 Source (pin2) | `GND` |
| Q2 Drain (pin3) | `WW_RET` |
| R4 (100 k) | `WW_GATE` ↔ `GND` (pulldown) |
| C1 (10 µF / 50 V) | `+36V` ↔ `GND` (inrush bulk) |
| J2 (CN1) V+ | `+36V` |
| J2 (CN1) CW- | `CW_RET` |
| J2 (CN1) WW- | `WW_RET` |

**ERC 2.4:** Q1/Q2 gates driven via series-R from GPIO4/5, pulled down (off at boot); drains → CN1
returns; `+36V` = J1 + C1 + CN1.V+ only; MOSFET Vds sees ≤35.8 V (needs ≥60 V part). **PASS.**

---

## Task 2.5 — CN1 (J2) full mapping + master check

**J2 = JST ZH 1.5mm 7-pos side entry (6 populated, pin 7 = NC):**

| J2 pin | Label | Net |
|---|---|---|
| 1 | V+ | `+36V` |
| 2 | CW- | `CW_RET` |
| 3 | WW- | `WW_RET` |
| 4 | 5V+ | `+4V7` |
| 5 | GND | `GND` |
| 6 | DIM | `RING_DATA` |
| 7 | (empty) | NC |

**Physical 1–7 order, rev B as built (authoritative — board-local, post-shrink frame):**

| Pad | Net | Board-local x | Board-local y |
|---|---|---|---|
| 1 | `+36V` | 54.500 | 19.650 (bottom-most) |
| 2 | `CW_RET` | 54.500 | 18.150 |
| 3 | `WW_RET` | 54.500 | 16.650 |
| 4 | `+4V7` | 54.500 | 15.150 (centre pad — orientation-independent) |
| 5 | `GND` | 54.500 | 13.650 |
| 6 | `RING_DATA` | 54.500 | 12.150 |
| 7 | NC | 54.500 | 10.650 (top-most) |

Pitch 1.500 mm, pad 1 → pad 7 span 9.000 mm. The two MP mounting tabs sit at x = 58.200, y = 21.600
and y = 8.700. The harness's empty position lands on pad 7, at the top.

**Orientation provenance (rev A, pre-shrink frame — not current geometry):** pin 1 was identified as
the bottom-most pad using rev A's own PicoBlade-pitch layout (board-local x 59.50, pad 1 at y 19.00,
1.25 mm pitch), confirmed against a photo of the working rev A board — the black `V+` wire sits at
the bottom end, which is pad 1. The rule carries forward unchanged into rev B: pad 1 is the
bottom-most pad (largest board-local y), pad 4 is the centre pad and is `+4V7` either way, and the
harness's blank position lands on pad 7 at the top.

**Master component check** (all `bom.csv` designators placed):
U1 U2 U3 U4 · Q1 Q2 Q3 · D1 D2 D3 · J1 J2 J3 · SW1 SW2 · C1–C8 · R1–R7 (R7 ×2) · R8 (rev-pol gate). ✅

**Power-domain isolation:** `+36V` ⟂ `+4V7` ⟂ `+3V3` ⟂ `VBUS` — the only cross-links are intended
(D1/D2 Schottky-OR into `LDO_IN`; U2 LDO 4.7/5 → 3.3). No net bridges 36 V to any low-voltage rail. ✅

**Floating-input check:** U3 /OE tied; MOSFET gates pulled down; EN/IO9 defined; USB CC pulled down. ✅

**ERC 2.5: PASS** — ready to enter in KiCad (Task 2.6).

---

## Add during KiCad entry (not yet designator'd above)
- **R8** (100 k): Q3 gate → `GND` (reverse-polarity FET gate reference). Add to BOM at Task 2.6.

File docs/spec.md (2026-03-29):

# Lumary Smart Recessed Light — Zigbee Controller Replacement

**Date:** 2026-03-28
**Status:** Approved

---

## Problem

Lumary RGBAI (RGB + Auxiliary Illumination) 6" recessed lights use a Tuya CBU (BK7231N) WiFi module. Even with local Tuya, reliability is tied to the server being up. Inovelli Blue Series Zigbee switches can't bind directly to WiFi lights, so scenes and local control require the hub to be online.

**Goal:** Replace the WiFi controller with a Zigbee-native one so the Inovelli switch binds directly to the light — hub-independent on/off, dimming, and effects.

---

## Hardware

### Target Light
- Lumary Smart RGBAI Recessed Light, 6"
- **Outer ring:** 36x SK6812 addressable RGBW LEDs (single-wire NZR protocol, similar to WS2812B)
- **Inner ring:** Cold white + warm white LEDs (2x PWM)
- **Controller box:** Separate from light body, connected by wire harness — houses the driver PCB and has space for a replacement board. Interior dimensions TBD — measure before ordering boards.

### Replacement Board
**ESP32-H2 Super Mini** (~$5, ~25×18mm)
- Native IEEE 802.15.4 Zigbee radio (no separate module)
- Built-in BLE (used for OTA fallback)
- Runs on 3.3V (available from existing PSU on driver board)
- Small enough to fit in the existing control box

### Wiring

| ESP32-H2 Pin | Signal | Destination | Notes |
|---|---|---|---|
| GPIO 11 (SPI2 MOSI) | SK6812 data | Outer ring 36-LED strip | SPI used to emulate NZR timing (see below) |
| GPIO 2 | PWM cold white | Inner ring CW | LEDC peripheral |
| GPIO 3 | PWM warm white | Inner ring WW | LEDC peripheral |
| 3.3V | Power | Tap from existing driver board | Verify rail capacity (see Power Budget) |
| GND | Ground | Common ground | |

Original CBU board is disconnected. Signal lines are tapped from the existing JST connector. Existing power supply remains in place.

### SK6812 Data Line — Protocol Note
SK6812 LEDs use a single-wire NZR timed protocol (not multi-wire SPI). On ESP32-H2, the RMT peripheral conflicts with the Zigbee radio and cannot be used. Instead, the SPI2 peripheral drives the data line by encoding each NZR bit as 3 SPI bits (1 = `110`, 0 = `100`) at 2.4 MHz SPI clock, producing a valid 800kHz NZR signal on MOSI. This technique is used in the [ShaunPCcom ESP32-H2 Zigbee LED project](https://github.com/ShaunPCcom/zigbee-LED-ESP32-controller) and is confirmed working.

**Phase 1 deliverables for SK6812:**
- Confirm GPIO 11 produces correct NZR waveform with SPI encoding
- Verify SK6812 color order (RGBW vs GRBW — batch-dependent, set as FastLED compile-time constant)

### Logic Level / Level Shifter
The ESP32-H2 outputs 3.3V logic. SK6812 strips powered at 5V require V_IH ≥ 3.5V (0.7 × 5V), making 3.3V signals marginal. **Phase 1 must verify signal integrity.** If the strip is powered at 3.3V (uncommon) no shifter is needed. If at 5V, add a single 74AHCT125 buffer or N-channel FET level shifter on the data line.

### Power Budget

| Component | Typical | Peak |
|---|---|---|
| ESP32-H2 (MCU active) | 50mA | 100mA |
| ESP32-H2 (Zigbee Tx) | +50mA burst | — |
| Original CBU (replaced) | ~80mA | — |
| **Net change on 3.3V rail** | ~+20mA typical | ~+70mA burst |

The existing 3.3V rail must tolerate the ESP32-H2's peak current including Zigbee Tx bursts. Verify the PSU's 3.3V rail rating before installation. If the rail is marginal, add a small LDO (e.g., AMS1117-3.3) fed from the 5V rail as a dedicated supply for the ESP32-H2.

Note: The SK6812 strip and CW/WW LEDs are driven by the existing higher-voltage rail (not 3.3V) — only the controller logic is on the 3.3V rail.

---

## Software Architecture

**Toolchain:** PlatformIO, Arduino framework, ESP32-H2 target
**Key libraries:** Arduino ESP32 Zigbee (v3.x), FastLED, NimBLE

```
┌─────────────────────────────────────────────┐
│         Zigbee Layer + OTA cluster          │
│   On/Off · Level · Color · Scenes · OTA     │
│       (Arduino ESP32 Zigbee library)        │
│   Runs on background FreeRTOS task          │
├─────────────────────────────────────────────┤
│       BLE Layer (NimBLE OTA fallback)       │
├─────────────────────────────────────────────┤
│              Effect Engine                  │
│  Active effect → renders frame every 16ms  │
│  Triggered by Zigbee scene recall / color   │
├─────────────────────────────────────────────┤
│             LED Driver Layer                │
│   FastLED → SK6812 (SPI2 NZR, 36 LEDs)    │
│   LEDC PWM → CW channel + WW channel       │
└─────────────────────────────────────────────┘
```

### Zigbee Device Type
**Extended Color Light** — exposes standard clusters:
- On/Off cluster
- Level Control cluster (brightness)
- Color Control cluster (RGB + color temperature)
- Scenes cluster (store/recall up to 16 scenes)
- OTA Upgrade cluster (firmware updates via Z2M)

Zigbee endpoint: **1** (standard for primary light endpoint — required for Inovelli Blue Series binding; set Source Endpoint to 2 on the switch, bind to endpoint 1 on the light).

This device type binds natively to the Inovelli Blue Series 2-1 switch.

### Render Loop / Zigbee Coexistence
The Arduino ESP32 Zigbee library runs the Zigbee stack on a background FreeRTOS task. The effect engine runs in `loop()` on the main task. FastLED's `show()` for 36 SK6812 LEDs at 800kHz takes ~1.1ms — well within Zigbee timing tolerances. The hardware watchdog is enabled with a 5-second timeout. If the main loop stalls (e.g., effect function bug), the device resets rather than hanging indefinitely.

### Effect Engine
Each effect is a function with signature:
```cpp
void effectFn(uint32_t elapsed_ms, EffectParams params);
```

Stored in a `const Effect effects[]` lookup table. The active effect index and parameters are stored in NVS so the light restores its last state after a power cut.

Each frame (~16ms):
1. Active effect function updates the FastLED buffer
2. `FastLED.show()` pushes to SK6812 via SPI2 NZR encoding
3. LEDC PWM levels updated for CW/WW

### Built-in Effects

| Scene # | Name | Description |
|---|---|---|
| 1 | Static White | CW/WW blend, brightness from dimmer |
| 2 | Static Color | Solid RGB on outer ring |
| 3 | Warm Gradient | Slow warm→cool sweep across 36 segments |
| 4 | Color Gradient | Multi-color gradient rotating around ring |
| 5 | Breathing | Fade in/out on outer ring |
| 6 | Color Cycle | HSV hue rotation through full spectrum |
| 7 | Chase | Single color chasing around the ring |
| 8 | Nightlight | Dim warm white outer ring only |

### Scene Management
**Zigbee Scenes cluster (primary):** HA/Zigbee2MQTT can send standard Add Scene commands with parameters (effect type, color, brightness, speed). Scenes are stored in NVS. Up to 16 scenes. All stored scenes work from the switch with no hub.

**Scene parameters per scene:**
- Effect type ID (maps to effects table)
- Color (HSV)
- Brightness (0–255)
- Speed/rate (0–255)

**NVS storage schema** (namespace: `lm_light`):

| Key | Type | Description |
|---|---|---|
| `fmt_ver` | u8 | Schema version, default 1. If missing or mismatched, reset to defaults |
| `active_scene` | u8 | Currently active scene index (0–15) |
| `scene_N_type` | u8 | Effect type ID for scene N |
| `scene_N_hue` | u8 | Hue for scene N |
| `scene_N_sat` | u8 | Saturation for scene N |
| `scene_N_bri` | u8 | Brightness for scene N |
| `scene_N_spd` | u8 | Speed for scene N |

On boot, if NVS read fails or `fmt_ver` is absent, fall back to Scene 1 (Static White, full brightness).

> **Note:** ESP-IDF NVS enforces a 15-character key limit. All keys above are within limit. Do not extend the naming scheme without re-checking.

### Switch Binding (Hub-Independent)
The Inovelli Blue Series switch handles all multi-tap logic internally. The light only needs to implement the Zigbee Scenes cluster correctly.

| Switch action | Zigbee command sent by switch | Light behavior |
|---|---|---|
| 1x tap | On/Off (direct binding) | Toggle on/off |
| Hold up/down | Level Control (direct binding) | Brighten/dim |
| 2x tap up | Scene Recall (scene endpoint) | Next scene |
| 2x tap down | Scene Recall (scene endpoint) | Previous scene |
| 3x tap | Scene Recall (specific ID) | Jump to scene (configured in Z2M) |

All commands travel directly over Zigbee from switch to light — no hub in the path.

---

## OTA Updates

### Primary: Zigbee OTA Upgrade cluster
- Standard Zigbee OTA protocol
- Z2M detects firmware in OTA folder, surfaces update in HA dashboard
- Firmware streams over Zigbee mesh in chunks
- Device reboots into new firmware on completion
- Fail-safe: device stays on current firmware if update is interrupted

**Building an OTA image from PlatformIO:**
1. PlatformIO produces a `.bin` file in `.pio/build/esp32h2/`
2. Wrap it in Zigbee OTA image format using Espressif's `ota_image_tool.py` (available at [espressif/esp-zigbee-sdk](https://github.com/espressif/esp-zigbee-sdk) — not included in Arduino environment by default, download separately)
3. Set manufacturer code and image type in the header — these must match values declared in firmware
4. Drop the `.ota` file into Z2M's `ota/` folder
5. In Z2M `configuration.yaml`, enable `ota: true` — Z2M will offer the update automatically

### Fallback: BLE OTA (NimBLE)
- ESP32-H2 BLE radio used as backup OTA channel
- Uses Espressif's standard NimBLE OTA GATT service
- Flash from laptop via `idf.py` BLE OTA tool or from phone via the ESP BLE Provisioning app
- Activate BLE OTA mode by holding the BOOT button (GPIO 9) on the ESP32-H2 Super Mini for 5 seconds

---

## Development Plan

1. **Phase 1 — Proof of concept:** Bring up ESP32-H2 Super Mini on bench. Drive SK6812 via SPI2 NZR encoding, verify waveform with logic analyzer or oscilloscope. Verify CW/WW PWM. Confirm SK6812 color order. Measure controller box interior dimensions. Check logic level — add level shifter if needed. Verify 3.3V rail current headroom. Confirm FastLED SPI2 backend works correctly under the Arduino ESP32 Zigbee FreeRTOS task model; if not, fall back to bare esp-idf `spi_device` API for LED driving.
2. **Phase 2 — Zigbee basics:** Join network via Z2M, on/off and dimming via switch binding, confirm endpoint 1 binding works with Inovelli switch
3. **Phase 3 — Color + scenes:** Color control cluster, scene storage in NVS with defined schema
4. **Phase 4 — Effects engine:** Implement all 8 effects, scene recall triggers effects, watchdog enabled
5. **Phase 5 — OTA:** Zigbee OTA cluster + BLE OTA fallback, test full update cycle on bench
6. **Phase 6 — Install + validate:** One light installed in ceiling, all features validated in-place

---

## Open Questions / Notes for v2
- Custom PCB (CBU drop-in form factor) if v1 validates the approach
- Additional effects can be added via OTA — no hardware change needed
- BLE OTA companion app for scene editing without HA
- Power-on flash: on power restore, SK6812 will briefly show last color before firmware initializes (~500ms). Acceptable for a ceiling light; can be mitigated in v2 with a data-line pull-down resistor

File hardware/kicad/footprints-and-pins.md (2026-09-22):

# KiCad build reference — footprints & confirmed pin maps

Data the `build_board.py` script encodes. All footprints are KiCad 10 stock libs (portable).
Toolchain: KiCad 10.0.5, `kicad-cli` + bundled `pcbnew` Python API confirmed working.

## Footprint assignments

| Ref | Part | KiCad footprint (lib:name) |
|---|---|---|
| U1 | ESP32-H2-MINI-1-N4 | `RF_Module:ESP32-C6-MINI-1` (identical MINI-1 land pattern; pads 1–53 + EPAD) |
| U2 | ME6211C33M5G LDO | `Package_TO_SOT_SMD:SOT-23-5` |
| U3 | 74AHCT1G125 buffer | `Package_TO_SOT_SMD:SOT-23-5` |
| U4 | USBLC6-2SC6 ESD | `Package_TO_SOT_SMD:SOT-23-6` |
| Q1,Q2 | N-MOSFET ≥60 V | `Package_TO_SOT_SMD:SOT-23` |
| Q3 | AO3401A P-MOSFET | `Package_TO_SOT_SMD:SOT-23` |
| D1,D2 | B5819W Schottky | `Diode_SMD:D_SOD-123` |
| D3 | SMAJ5.0A TVS | `Diode_SMD:D_SMA` |
| J1 | JST-PH 2.0 3-pin | `Connector_JST:JST_PH_S3B-PH-K_1x03_P2.00mm_Horizontal` |
| J2 | JST ZH 1.5 7-pin side entry | `Connector_JST:JST_ZH_S7B-ZR-SM4A-TF_1x07-1MP_P1.50mm_Horizontal` |
| J3 | USB-C TYPE-C-31-M-12 | `Connector_USB:USB_C_Receptacle_HRO_TYPE-C-31-M-12` |
| SW1,SW2 | tact | `Button_Switch_SMD:SW_SPST_SKQG_WithoutStem` (verify at build) |
| C1 | 10 µF/50 V | `Capacitor_SMD:C_0805_2012Metric` |
| C2,C4,C5 | 10 µF | `Capacitor_SMD:C_0603_1608Metric` |
| C3 | 1 µF | `Capacitor_SMD:C_0603_1608Metric` |
| C6,C7 | 100 nF | `Capacitor_SMD:C_0402_1005Metric` |
| C8 | 1 µF | `Capacitor_SMD:C_0402_1005Metric` |
| R1–R9 | resistors | `Resistor_SMD:R_0402_1005Metric` |

## Confirmed pin maps

**U1 ESP32-H2-MINI-1 (pad → function):**
- 3V3 = 3 · EN = 8 · IO9(BOOT) = 23 · IO11(ring data) = 21 · IO4(CW PWM) = 18 · IO5(WW PWM) = 19
- USB_D− = 26 · USB_D+ = 27
- GND = 1, 2, 11, 14, 36–53 (49 = EPAD)

**U2 ME6211 (SOT-23-5):** 1=VIN, 2=GND, 3=CE, 4=NC, 5=VOUT
**U3 74AHCT1G125 (SOT-23-5):** 1=/OE, 2=A(in), 3=GND, 4=Y(out), 5=VCC
**U4 USBLC6-2SC6 (SOT-23-6):** 1&6=I/O1 (→D+), 3&4=I/O2 (→D−), 2=GND, 5=VBUS
**Q1/Q2 N-FET, Q3 AO3401A P-FET (SOT-23):** 1=Gate, 2=Source, 3=Drain
**D1/D2 SOD-123, D3 SMA:** pad 1 = cathode (K), pad 2 = anode (A)

## Still to extract at build time
- USB-C `HRO_TYPE-C-31-M-12` footprint pad names → map VBUS / GND / CC1 / CC2 / D+ / D− / SHIELD
  (grep the `.kicad_mod` pad labels when writing the net assignments).

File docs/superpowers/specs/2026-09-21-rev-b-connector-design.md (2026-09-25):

# Rev B: a J2 that mates with the stock harness — design

**Date:** 2026-09-21
**Status:** approved, ready for implementation

Closes the J2 footprint mismatch first recorded in `docs/research/teardown-reference.md` and P0.1 of
`docs/superpowers/research/phase0-measurements.md`, and picks up the trace-width item deferred to
rev B in `hardware/calcs.md`.

## 1. Problem

### 1.1 J2 does not mate with CN1

Rev A was fabbed with J2 as a **Molex PicoBlade 1.25 mm 7-pin**
(`Molex_PicoBlade_53047-0710_1x07_P1.25mm_Vertical`), chosen from an early reading of the stock
board. On 2026-09-04 the real connector was physically verified against purchased parts: CN1 is
**JST ZH, 1.5 mm pitch, 7-position**. The pitch is wrong, so the stock harness cannot plug into a
rev A board at all.

The workaround — a ZH1.5-7P-to-PicoBlade-7P pigtail — is built and working on Test Unit 2. It is
not a defect, but every board carries an extra adapter, extra crimps and two extra contact pairs in
the ring's current path.

### 1.2 Every power track is at minimum width

Measured directly from `hardware/kicad/lumary-brain.kicad_pcb`, **every routed segment on the board
is 0.20 mm** — including `+36V`, `+4V7`, `+4V7_IN`, `VBUS`, `CW_RET` and `WW_RET`. `GND` has no
segments at all; it is a pour.

`build_board.py` writes a `Power` net class of 0.5 mm into `lumary-brain.kicad_pro` and assigns
those nets to it, but the hand routing never honoured it. This is the "rev B should fix the trace
width" item in `hardware/calcs.md`, and it is broader than that note implies — it is not one ring
trace, it is the whole power distribution.

## 2. Goal

A board the stock harness plugs straight into, with power tracks at the width the design already
says they should be. Explicitly **not** a re-layout: everything that works stays where it is.

## 3. Design

### 3.1 J2 → JST ZH side entry

| | rev A | rev B |
|---|---|---|
| Footprint | `Connector_Molex:Molex_PicoBlade_53047-0710_1x07_P1.25mm_Vertical` | `Connector_JST:JST_ZH_S7B-ZR-SM4A-TF_1x07-1MP_P1.50mm_Horizontal` |
| Pitch / pin span | 1.25 mm / 7.5 mm | 1.50 mm / 9.0 mm |
| Courtyard | 4.3 × 11.6 mm | 15.0 × 8.0 mm |
| Entry | vertical (top) | **side, harness over the board edge** |

Side entry, not vertical, for two reasons: it is what the stock board does — the solder tabs face
inboard and the harness exits over the board edge, visible in
`docs/research/stock-board-cn1-labels.jpg` — and J1 is already a horizontal JST-PH, so the board
gains consistency rather than losing it.

All three ZH 7-pin variants ship in stock KiCad, so no custom footprint is needed.

Net assignment is unchanged from `hardware/schematic-nets.md` §2.5:

| J2 pin | Label | Net | Harness wire |
|---|---|---|---|
| 1 | `V+` | `+36V` | black |
| 2 | `CW-` | `CW_RET` | white |
| 3 | `WW-` | `WW_RET` | yellow |
| 4 | `5V+` | `+4V7` | red |
| 5 | `GND` | `GND` | green |
| 6 | `DIM` | `RING_DATA` | blue |
| 7 | — | NC | (unpopulated) |

The wire-colour column is from P0.3 and was confirmed against the physical part on 2026-09-21: the
silkscreen order `V+ · CW- · WW- · 5V+ · GND · DIM` and the exiting wire colours agree.

### 3.2 Placement: centred on the board axis, at the rounded tip

The new courtyard is 8 mm deep against the old 4.3 mm. Left at J2's rev A position (x = 59.5, right
edge 62.06) it would reach x ≈ 64.0 on a board that ends at 63.3 — it overhangs. It must move
inboard, and the board's right end is a single 18 mm-radius arc, so every millimetre further right
costs vertical room.

**Superseded 2026-09-22:** the outline itself has since shrunk to 62.3 × 30.3 mm (0.5 mm inset per
side, see §4), because rev A's 63.3 × 31.3 mm outline fits the housing too tightly. Every "ends at
63.3" figure above is from the pre-shrink outline; it does not change where J2 sits (still
board-local (56.15, 15.15), rotation 90 — see `hardware/kicad/check_board.py`), only how much margin
is left around it.

**J2 goes on the board's Y midline (y ≈ 15.65), courtyard X ≈ 53.7–61.7**, rotated so the opening
faces +X. Centring on the midline is what buys the rightmost position, because that is where the arc
is widest: requiring the courtyard's corners at y = 15.65 ± 7.5 to fall inside the arc gives a
maximum right edge of x = 61.66, and less than that at any other Y. It also puts the harness exiting
straight off the rounded tip, which is what the stock board does.

The exact origin is settled at layout against DRC clearance; aim for ≥ 0.5 mm from the outline,
which pulls the right edge back to about x = 61.1.

**C1 moves ~2 mm left** (from `POS` 53.4 → ~51.4) to clear the new courtyard, staying adjacent to
J2 pin 1 so it still serves as the 36 V inrush bulk. Nothing else moves: `J3` ends at x = 47.25,
and `C4`/`Q3` sit at a different Y. `U3` clears in Y by ~0.6 mm and must be checked at layout.

### 3.3 Execution: edit the board, then sync the script

`hardware/kicad/build_board.py` seeds the board from the netlist — it places footprints, assigns
nets and draws the outline, then `board.Save()` writes `lumary-brain.kicad_pcb` **unconditionally**
and also overwrites `lumary-brain.kicad_pro`. Re-running it destroys all hand routing.

So rev B is a **surgical edit in KiCad**, not a regenerate:

1. In KiCad: delete J2, place the ZH footprint at the new position, re-assign its six nets, move C1,
   re-route what those two disturb.
2. Widen the power nets (§3.4).
3. Update `build_board.py`'s `COMPONENTS["J2"]`, `POS["J2"]` and `POS["C1"]` to match, so the script
   still describes the board it would seed.

The script's own docstring — "routing is done by hand in KiCad afterwards" — establishes that the
`.kicad_pcb` has always been the artifact of record, never a reproducible build output. Regenerating
would pay the full routing cost for a reproducibility the project does not have.

### 3.4 Power tracks to the width the design already specifies

Re-width the `Power` class nets (`+36V`, `+4V7`, `+4V7_IN`, `+3V3`, `VBUS`, `LDO_IN`, `CW_RET`,
`WW_RET`) from 0.20 mm to the class's **0.5 mm**, as space allows. `GND` needs nothing — it is a
pour.

**This does not raise the brightness cap, and the docs must not claim it does.** The limits, in
order:

| Limit | Rev A | Rev B |
|---|---|---|
| `+4V7` track (1 oz, 10 °C rise) | ~0.74 A ← binding | ~1.5 A |
| J2 contact rating | 1.0 A | 1.0 A ← **becomes binding** |
| Driver `+4V7` capacity | **never measured** | never measured |
| Ring cold-start, full white | 1.21 A | 1.21 A |

Widening moves the track out of the way and hands the constraint to the connector and to a supply
rail nobody has metered. It is worth doing anyway — 0.2 mm carrying 380 mA on `+36V` is thin, and
the cost while already re-routing is near zero — but the cap stays where it is until the `+4V7`
rail is measured. `hardware/calcs.md` line 30 should be corrected to say so.

### 3.5 Documentation

- `hardware/bom.csv` and `hardware/kicad/bom-jlc.csv`: J2 becomes a ZH 1.5 mm 7-position part
  (`S7B-ZR-SM4A-TF`). It has **no LCSC number and `VERIFY` status today** — it was never
  JLC-assembled. **Decision: keep J2 hand-fit**, matching rev A and the other blank-LCSC parts
  (`C1`, `C2`, `Q1`, `Q2`, `SW1`, `SW2`); the user already has ZH parts in hand. Revisit only if
  rev B moves to full JLC assembly, which is out of scope here.
  **Superseded 2026-09-25:** rev B is fully JLC-assembled, as rev A was. J2 = `C5118704`
  (genuine JST `S7B-ZR-SM4A-TF(LF)(SN)`, Extended, SMT-assemblable).
- `hardware/kicad/footprints-and-pins.md`: J2 footprint name.
- `hardware/schematic-nets.md` §2.5: drop "J2 = PicoBlade 7-pos"; record that the physical 1..7
  order is now resolved.
- `docs/research/teardown-reference.md` and P0.1: mark the mismatch closed by rev B.
- `hardware/calcs.md`: record the 0.20 mm measurement and correct line 30.

## 4. Verification

Before releasing gerbers:

1. **DRC clean**, with attention to the J2/C1 and J2/U3 clearances called out in §3.2.
2. **Netlist assertion**: J2 pads 1–7 carry `+36V`, `CW_RET`, `WW_RET`, `+4V7`, `GND`, `RING_DATA`,
   NC. This is the failure that destroys boards — 36 V landing on the 4.7 V rail or the data line —
   so it is checked explicitly, not assumed from a successful placement.
3. **Track-width regression**: re-run the per-net width measurement over the `.kicad_pcb` and
   confirm the Power nets are no longer 0.20 mm.
4. **1:1 print** checked against the physical ZH connector already purchased.
5. **Outline shrunk 0.5 mm/side (superseded 2026-09-22):** the plan to leave the outline unchanged
   at 63.3 × 31.3 mm did not survive contact with the housing — rev A's board fits the can too
   tightly. The board is now **62.3 × 30.3 mm**, end arcs radius 17.5 mm about unchanged centres.
   The stock can/housing envelope itself is still 63.3 × 31.3 × 6.7 mm (`phase0-measurements.md`
   §P0.6, `2026-08-03-tht-board-design.md` line 32) — it is our board that shrank, not the can.

After fab, the first board is brought up on the bench against a real harness with no pigtail, and
the existing bench checklist re-run.

## 5. Risks

- **Silent script/board drift.** §3.3 leaves `build_board.py` describing a board it did not
  generate. Mitigated by updating it in the same commit, but it stays a standing hazard: anyone who
  re-runs the script loses the routing. Worth a warning banner in the script itself.
- **The 0.5 mm re-width may not fit everywhere** on a dense 63 × 31 mm two-layer board. Where it
  does not, leave the segment at 0.2 mm and record which — a partial widening is fine, an
  undocumented one is not.
- **`U3` clears J2 by only ~0.6 mm** in Y. If DRC objects, `U3` moves rather than J2 — J2's position
  is pinned by the arc.
- **The pin-1 physical order was never scanned** (P0.6: "no scan will be provided"). Rev B resolves
  it by construction. As built (board-local, post-shrink frame): all seven J2 pads sit at x =
  54.500, pitch 1.500 mm, span pad 1 → pad 7 = 9.000 mm — pad 1 (`+36V`) is the bottom-most at
  y = 19.650, pad 4 (`+4V7`) is the centre pad at y = 15.150 (orientation-independent either way),
  and pad 7 (NC) is the top-most at y = 10.650. The two MP mounting tabs sit at x = 58.200, y =
  21.600 and 8.700. Orientation is confirmed, not just inferred: a photo of the working rev A board
  shows the black `V+` wire at the bottom end, which is pad 1 — established in rev A's own
  pre-shrink frame (pads at x 59.50, pitch 1.25 mm, pad 1 at y 19.00) and carried forward unchanged
  into rev B's geometry. The harness's blank position lands on pad 7, at the top.

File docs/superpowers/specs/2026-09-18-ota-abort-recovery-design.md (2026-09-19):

# Automatic recovery from a failed Zigbee OTA — design

**Date:** 2026-09-18
**Status:** approved, ready for implementation

Follows the OTA investigation in `docs/research/ota-throughput.md` and the rev A sign-off gate in
`docs/superpowers/plans/2026-08-18-bench-verification.md` section 11.

## 1. Problem

A fixture whose OTA download fails **cannot be updated again until it is power-cycled**, and a
fixture in a ceiling has no power switch short of the breaker. There is no BLE fallback and no
remote reboot (README "OTA Updates"), so today a single failed update strands the fixture on its old
firmware.

### 1.1 Root cause: the library never resets its state on abort

`zb_ota_upgrade_status_handler()` in the Arduino Zigbee library (`ZigbeeHandlers.cpp:363`) keeps
file-static `offset`, `total_size` and `s_tagid_received`, and resets them only in the
`ESP_ZB_ZCL_OTA_UPGRADE_STATUS_CHECK` case (a successful end). `ESP_ZB_ZCL_OTA_UPGRADE_STATUS_ABORT`
falls into `default:`, which only logs -- no reset, and no `zbOTAState(false)` either. The next
session's first block is then fed to a parser that believes it is mid-image, and the device ends
the session with `INVALID_IMAGE` two blocks in. Only a reboot clears it.

Observed on hardware repeatedly: 2026-09-15 (twice after a deliberately aborted session) and
2026-09-18 (the loft fixture, days after its last aborted session, fixed only by power-cycling it
through its Inovelli switch).

### 1.2 Failures still happen on a good link

The coordinator work of 2026-09-18 took OTA from ~25 B/s to ~100 B/s and made it steady, and a full
844 KB update has now completed on the bench (2 h 20 m). But ~17,000 block exchanges per image
means an occasional failure is a normal event, not an exceptional one -- for example a lost block
*response*, after which the OTA client waits ~134 s and aborts rather than re-requesting. Recovery
has to be automatic.

## 2. Goal

After a failed or stalled OTA, the fixture recovers by itself and the update is retried, with no one
touching the fixture and no visible change to the light beyond a ~1 s blink.

**Non-goals:** resuming a download from its offset; making transfers faster; fixing the library
itself; restoring light state after a *power loss* (StartUpOnOff remains a separate future feature).
Also out of scope, though a natural follow-up: after a *successful* update the library restarts the
fixture itself, and it comes back **off** (today's behaviour). Snapshotting on status 2 would extend
this design to cover it.

## 3. Design

### 3.1 Detection: `src/ota_watch.h` (pure logic, host-tested)

No ESP-IDF includes, in the style of `light_state.h`. Fed one sample per second:

```c
typedef struct {
    uint8_t  image_status;   // OTA client ImageUpgradeStatus (0x0006)
    uint32_t file_offset;    // OTA client FileOffset (0x0001)
    uint32_t now_ms;         // millis()
} OtaSample;
```

and answers "recover now, or not" plus the reason (`OTA_RECOVER_NONE`, `_ABORT`, `_STALL`).
ImageUpgradeStatus values used: 0 = Normal, 1 = Download in progress, 2 = Download complete.

It only ever triggers **after it has seen status 1 during the current boot.** Then:

- **Abort:** status went 1 -> 0 without passing through 2, and has stayed 0 for **5 s** (the grace
  period absorbs a flicker).
- **Stall (backstop):** status is 1 and `file_offset` has not changed for **180 s**. The OTA
  client's own give-up is ~134 s, so this fires only if the client hangs instead, or if the stack
  never returns the status to 0 after an abort (not yet known -- see 5.1). Either way recovery
  happens within ~3 minutes.
- **Never** after status 2: download complete is terminal and the library reboots into the new
  image itself.

Normal retry stalls (3-10 s, the occasional ~48 s) are far below 180 s. All time comparisons are
wrap-safe (`now - then`, unsigned).

### 3.2 Glue: `src/zigbee_light.cpp`

`zigbee_light_loop()` samples once per second: reads the two attributes with
`esp_zb_zcl_get_attribute(DOWNLIGHT_ENDPOINT, ESP_ZB_ZCL_CLUSTER_ID_OTA_UPGRADE,
ESP_ZB_ZCL_CLUSTER_CLIENT_ROLE, ...)` under `esp_zb_lock_acquire()`, feeds `ota_watch`, and calls
`ota_recover(reason)` when it says so. If the lock or an attribute is unavailable, that sample is
skipped (no trigger).

### 3.3 Recovery and state snapshot: `src/ota_snapshot.h` (pure logic, host-tested) + glue

`ota_recover(reason)`:

1. Snapshots `FixtureState` -- both halves: downlight on/off, level, colour temperature; ring
   on/off, level, mode, colour, scene -- into a record placed in `__NOINIT_ATTR` RAM (not zeroed at
   startup, so it survives `esp_restart()` but not a power loss). The record carries a magic
   number, a format version, a checksum, the consecutive-recovery count, and the reason.
2. Logs the reason, the offset reached and the recovery count.
3. Calls `esp_restart()`.

`ota_snapshot.h` owns the pure parts -- `snapshot_save()`, `snapshot_valid()` (magic + version +
checksum), `snapshot_invalidate()` -- over a plain struct, so they are host-testable. The
`__NOINIT_ATTR` instance and `esp_reset_reason()` live in the glue.

`RTC_NOINIT_ATTR` is **not** used: on this target it can compile to nothing
(`esp_attr.h` defines it empty when RTC memory is unavailable). `__NOINIT_ATTR` is always backed.

### 3.4 Restore on boot

In `zigbee_light_init()`, after `fixture_state_init()` and the NVS scene load: if
`esp_reset_reason() == ESP_RST_SW` **and** `snapshot_valid()`, copy the saved state over the
defaults, then **invalidate the record immediately** so it can only be used once. The existing
first-join one-shot in `zigbee_light_loop()` then publishes the restored on/off and level, so Home
Assistant never sees the light flip.

**The light library's own copies must be synced too** (found while planning). The Arduino
`ZigbeeColorDimmableLight` keeps *private* `_current_state` / `_current_level`, and its
`zbAttributeSet()` only calls our callbacks when a command *changes* them
(`ZigbeeColorDimmableLight.cpp:139,149`). Left at their power-up defaults (off, 255) after a restore,
an **Off command to a restored-on light would be swallowed** -- the library believes it is already
off. So in the first-join one-shot, before publishing, a restored fixture calls the public
`setLightLevel()` / `setLightState()` on both endpoints with our light callbacks suppressed by a
flag: those setters update the private copies and the ZCL attributes, then call back synchronously,
and the callback must not re-enter `FixtureState` (on the ring it could drop the restored effect).
Normal boots skip this step entirely.

The snapshot is used **only** after an OTA recovery restart. Any other reset -- power loss, brownout,
watchdog, panic -- boots with today's defaults: a power loss leaves random RAM (the checksum
rejects it), and other resets are not `ESP_RST_SW` or find the record already invalidated.

The consecutive-recovery count survives into the next record and is reset when the fixture boots
without a valid snapshot.

### 3.5 Retry: Zigbee2MQTT's scheduled updates (no firmware logic)

Zigbee2MQTT documents that *"if a scheduled update fails, it will remain scheduled (Device will try
again, on the next check)"*, that the schedule is persisted across Z2M restarts, and that it clears
once no update is available. Our firmware already queries for an image on every join
(`requestOTAUpdate()` in the first-join one-shot) and hourly after that. So:

1. Start updates with `zigbee2mqtt/bridge/request/device/ota_update/schedule`, `{"id": "..."}`.
2. The next image query starts the download.
3. On failure the fixture recovers (3.1-3.4), rejoins, queries, and the schedule restarts the
   download from zero.
4. On success it boots the new version and Z2M clears the schedule.

**No retry cap in firmware.** A failure costs a ~1 s blink and a restarted download; repeating is
harmless. An image that can never succeed is stopped from Z2M with `.../ota_update/unschedule`. The
logged recovery count makes a looping fixture obvious.

### 3.6 Documentation

README "OTA Updates": the schedule workflow as the recommended way to update; the abort behaviour
and its automatic recovery; and, for fixtures still on firmware older than this feature, the manual
recovery -- power-cycle the fixture (via the breaker, or via its Inovelli switch: switch off, disable
Smart Bulb Mode, wait, re-enable Smart Bulb Mode).

## 4. Release

Ships as **2.1.0** (new behaviour): `FW_VERSION_MINOR` 1, `FW_VERSION_PATCH` 0, `test_version`
updated to match. The bench board's OTA from 2.0.2 to 2.1.0 is itself a real OTA test.

## 5. Verification

### 5.1 Premise check (first, on the bench)

Log `ImageUpgradeStatus` and `FileOffset` once per second during a real download on Test Unit 2.
Confirm the stack advances `FileOffset` per block and sets status 1 during download. **If it does
not, stop and revisit the detection approach before building the rest.**

### 5.2 Host tests (`scripts\run-native-tests.bat`)

`test/test_ota_watch`:
- no trigger without a download seen this boot
- abort triggers once status has been 0 for 5 s after 1; a shorter flicker does not
- stall triggers at 180 s of unchanged offset; an advancing offset never does
- 1 -> 2 -> 0 never triggers
- correct across a `millis()` wrap

`test/test_ota_snapshot`:
- save -> valid round-trip preserves every field
- one corrupted byte, a wrong magic, or a wrong version -> invalid
- invalid after `snapshot_invalidate()`
- consecutive-recovery count carries across a save

### 5.3 Bench (Test Unit 2, serial logger attached)

1. **Forced failure:** set a distinctive state (downlight on at a dim level and a non-default colour
   temperature; ring running a non-default effect), schedule the update, stop Z2M mid-transfer.
   Expect: device abort within ~134 s -> `ota_watch` triggers -> reboot -> identical light state
   restored, HA shows no flip -> Z2M started again -> the schedule restarts the download by itself.
2. **Completion:** let a scheduled update run to the end; the schedule clears itself.
3. **Negative:** a real power cycle boots with defaults; a watchdog reset does not restore a stale
   snapshot.

Stopping/starting Z2M may be blocked by Claude Code's permission check; if so, the user does it from
Home Assistant while the serial log is watched.

## 6. Risks

- **The premise (5.1) is unverified.** Detection depends on the stack maintaining the OTA client
  attributes. Checked first; the stall path covers the "status never returns to 0" variant.
- **A false stall** would cost a needless blink and restart a healthy download. 180 s is ~3.7x the
  longest normal stall seen (48 s) and above the client's own 134 s give-up.
- **Snapshot scope creep.** Restoring state after *other* resets is deliberately excluded; it
  belongs to StartUpOnOff, which also needs NVS persistence and Z2M's `power_on_behavior`.

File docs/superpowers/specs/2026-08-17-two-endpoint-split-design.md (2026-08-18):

# Two light entities from one fixture — design

**Date:** 2026-08-17
**Status:** approved, ready for implementation

Item 9 of `docs/superpowers/plans/2026-08-17-home-assistant-polish.md`, which recorded the decision
("a second Zigbee endpoint, so HA gets two light entities under one device") but not the design.
This is that design, and it revises one part of the original note — see §2.1.

Taken after item 6 (gamma) deliberately: item 9 balances the downlight against the ring by eye, and
tuning that balance on an uncorrected brightness curve would mean tuning it twice.

## 1. Problem

### 1.1 The capability the fixture was bought for is unreachable

`WHITE_SAT_THRESHOLD` in `src/light_state.h:16` routes every command to exactly one of the two light
sources: saturation at or below 32 goes to the inner CW/WW white string, anything above it goes to
the outer RGB ring. `light_state_resolve()` (`src/light_state.h:153`) is where that fork lives.

The consequence is that colour and white are mutually exclusive. The fixture is sold as a "gradient
auxiliary light" — a white downlight with a coloured accent ring around it — and that combination
cannot be commanded at all. One entity can only be in one mode.

### 1.2 What Home Assistant sees today

One `light.*` entity carrying on/off, brightness, colour temperature 154–370 mired, xy colour, and an
eight-entry effect list. One device, one light, one mode at a time.

## 2. Decisions

| Decision | Choice | Why |
|---|---|---|
| Endpoint 1 | Downlight (inner CW/WW string) | Existing switch bindings target endpoint 1 and should land on the main light; the OTA client and Basic strings already live there |
| Endpoint 2 | Accent Ring (outer 62-pixel RGB) | New endpoint, so nothing existing moves |
| Downlight capability | `COLOR_TEMP` only, 154–370 mired | It has no colour dice |
| Ring capability | `HUE_SATURATION` + `X_Y` | It has no white die; advertising CCT would expose a control that lies |
| Effects | belong to the ring; list shrinks 8 to 6 | See §2.1 |
| State model | two purpose-built structs in one container | See §3.3 |
| Switch binding | bind both endpoints | See §2.2 |

### 2.1 The effect list shrinks, and this revises the backlog note

The backlog said "the effect cluster stays on endpoint 1 — effects are a whole-fixture concept."
Reading what the effects actually do, that is no longer true:

- Seven of the eight call `white_off()` and drive only the ring.
- The eighth, `fx_static_white`, drives only the white string. Once the downlight is its own entity
  with its own on/off, level and colour temperature, that *is* the downlight — it stops being an
  effect and becomes the entity's ordinary behaviour.

`fx_static_color` goes the same way: with the ring as its own entity, "ring showing a solid colour"
is the ring being set to a colour, which the code already models as `MODE_COLOR` / `effect: none`.

So effects belong to the ring, and the list drops to six:

| Today | After |
|---|---|
| `static_white` | gone — it is the Downlight entity |
| `static_color` | gone from the list — it is `effect: none` with a colour set |
| `warm_gradient`, `color_gradient`, `breathing`, `color_cycle`, `chase`, `nightlight` | kept, renumbered from 0 |

This is a breaking change with three consequences, all handled in §3.7 and §6: NVS scene indices
shift, the converter's `EFFECTS` map is renumbered, and any Home Assistant automation naming
`static_white` or `static_color` stops working.

### 2.2 Both endpoints get bound to the switch

A binding targets one endpoint. Binding only the downlight would leave the ring lit after the light
is switched off at the wall, recoverable only if the coordinator is up — a regression against
today's behaviour, in a fixture whose accent ring is the selling point.

The alternative considered and rejected was a firmware rule mirroring downlight-off to the ring.
Every version of that rule is bad: ganging them deletes the "downlight on, ring off" state, which is
the most common one for a ceiling can; a one-way rule with no restore means every use of the wall
switch silently discards the ring setting; and a rule that restores requires the firmware to hold a
shadow copy of the ring's pre-off state that Home Assistant cannot see. All three share a fatal
flaw: the callback cannot tell a switch command from a hub command, so turning the downlight off
from the Home Assistant dashboard would darken the accent ring with nothing in the UI to explain it.

Binding both endpoints produces a similar outcome by a better mechanism. It is configuration, not
behaviour: visible in Z2M's binding table, editable, removable. The firmware stays honest — two
endpoints, genuinely independent, no hidden state — and each endpoint keeps its own level and colour
across the cycle because each simply receives a normal Zigbee command.

**Confirmed on the hardware (2026-08-17): the Inovelli sends discrete `On` and `Off`, not `Toggle`.**
This is what makes binding both safe. Under `Toggle`, two endpoints in different states would
diverge on every tap, and the fallback would be to bind the downlight only and drive the ring from
the hub. The behaviour is not documented by Inovelli — not in the manual, the help centre, the Z2M
device page, or the community threads — so it was settled empirically: with the light off, tap up
twice. Staying on means discrete `On`; going off would have meant `Toggle`.

The switch's transmitting endpoint is **2** (endpoint 1 receives, endpoint 2 is the paddle,
endpoint 3 is the config button), so both bindings are from switch endpoint 2:

```
{"from": "switch", "from_endpoint": 2, "to": "fixture", "to_endpoint": 1, "clusters": ["genOnOff", "genLevelCtrl"]}
{"from": "switch", "from_endpoint": 2, "to": "fixture", "to_endpoint": 2, "clusters": ["genOnOff", "genLevelCtrl"]}
```

Residual cost, worth stating in the README: tap up turns the ring on too, so "downlight only"
becomes a Home Assistant action rather than a switch action.

## 3. Design

### 3.1 Endpoints

Both are `ZigbeeColorDimmableLight` — the Arduino library offers no colour-temperature-only class —
differentiated by capability and by what is bolted on:

| | Endpoint | Capabilities | Extras |
|---|---|---|---|
| Downlight | 1 | `COLOR_TEMP`, range 154–370 mired | OTA client, Basic `SWBuildID`/`DateCode`, Identify |
| Accent Ring | 2 | `HUE_SATURATION` + `X_Y` | custom cluster `0xFC00` (effect) |

Identify stays on endpoint 1 and still blinks the ring blue: it answers "which can in the ceiling is
this", a whole-fixture question. It keeps darkening the downlight for the duration, because a lit
downlight washes out a blue ring — but that now happens in the render loop rather than inside the
effect (§3.5).

### 3.2 The converter

Two `m.light()` extends with `endpointNames`, an endpoint map, and `meta: {multiEndpoint: true}`:

```js
endpoint: (device) => ({downlight: 1, ring: 2}),
meta: {multiEndpoint: true},
extend: [
    m.light({endpointNames: ['downlight'], colorTemp: {range: [154, 370], startup: false},
             color: false, effect: false, powerOnBehavior: false}),
    m.light({endpointNames: ['ring'], color: {modes: ['xy']},
             effect: false, powerOnBehavior: false}),
    m.identify(),
    m.deviceAddCustomCluster('lumary', {/* unchanged */}),
],
```

`effect: false` and `powerOnBehavior: false` stay on both for the reasons already recorded in
`2026-08-15-effect-selection-design.md` and the polish backlog's item 2: the firmware implements
neither the Identify trigger-effects nor `StartUpOnOff`, and leaving them on puts dead controls in
the light card.

Home Assistant ends up with `light.<name>_downlight` and `light.<name>_ring` under one device. The
effect expose targets endpoint 2 only, so the dropdown appears on the ring entity where it belongs,
and `tzColorClearsEffect` narrows to that endpoint too.

### 3.3 State model

`src/light_state.h` becomes:

```c
struct DownlightState { bool on; uint8_t level; uint8_t cct; };
struct RingState      { bool on; uint8_t level, hue, sat, scene; LightMode mode; };
struct FixtureState   { DownlightState down; RingState ring; };
```

Two purpose-built structs rather than two copies of today's combined one, so each type states
exactly what its source has and nothing more; wrapped in one container so `zigbee_light_state()`
still returns a single pointer and `main.cpp` deals with one object.

**Deleted outright:**

- `WHITE_SAT_THRESHOLD`. It answered "is this command white or colour?" — a question that stops
  existing once each source has its own endpoint. A command arrives *at* the ring or *at* the
  downlight; there is nothing left to infer.
- `rgb_to_cct()`. It guessed warmth from an RGB colour for coordinators that express white as RGB.
  The downlight advertises colour-temperature capability only, so it receives mireds directly.

**Kept:** `rgb_to_hsv()` (the ring still converts incoming RGB), `mireds_to_cct()`, `scale_level()`,
`LIGHT_EFFECT_NONE`, `LightMode`, `CCT_MIRED_WARM` / `CCT_MIRED_COOL`.

`LightMode` survives on the ring only, now meaning exactly what it always did underneath:
`MODE_SCENE` = running an effect, `MODE_COLOR` = showing a solid colour.

`light_state_resolve()` splits in two:

```c
inline uint8_t      downlight_level(const DownlightState* s);              // one-line `on` gate
inline EffectParams ring_state_resolve(const RingState* s, const EffectParams* scene);
```

`ring_state_resolve` is today's logic minus the white branch. It does **not** encode the mode in its
return value — the render loop reads `ring.mode` directly, which is where the information already is.

In `MODE_COLOR` the returned `type` field is unused, because the render loop calls `fx_ring_solid`
without consulting it. It must still be **initialised to a valid index** rather than left
indeterminate: `EffectParams` is returned by value and a later reader of an uninitialised enum is
undefined behaviour. Set it to the active `scene`, which is always in range.

### 3.4 The effect list

`src/effect_params.h`:

```c
enum EffectType : uint8_t {
    EFFECT_WARM_GRADIENT  = 0,
    EFFECT_COLOR_GRADIENT = 1,
    EFFECT_BREATHING      = 2,
    EFFECT_COLOR_CYCLE    = 3,
    EFFECT_CHASE          = 4,
    EFFECT_NIGHTLIGHT     = 5,
    EFFECT_COUNT          = 6
};
```

`kDefaultParams` and `kEffects` both shrink to six entries in this order.

`fx_static_white` is **deleted** — the downlight renders straight through `white_mix_gamma()`.

`fx_static_color` is **renamed `fx_ring_solid` and leaves `kEffects`** rather than being deleted:
something still has to render `MODE_COLOR`. It joins `fx_identify` as a function the render loop
calls but the dropdown never lists.

`src/effects.cpp` stops including `led_driver.h`. All seven `white_off()` calls and the helper itself
come out, and the file becomes purely "fill a `CRGB` buffer" with no hardware dependency.

### 3.5 Render loop

`src/main.cpp`:

```cpp
if (identifying) {
    fx_identify(now, leds);
    led_driver_set_cw(0);
    led_driver_set_ww(0);
} else {
    const EffectParams rp = ring_state_resolve(&s->ring, &scene);
    if (s->ring.mode == MODE_COLOR) fx_ring_solid(rp, leds, s->ring.on);
    else kEffects[rp.type].fn(now - effect_start, rp, leds, s->ring.on);

    const WhiteMix w = white_mix_gamma(downlight_level(&s->down), s->down.cct);
    led_driver_set_ww(w.ww);
    led_driver_set_cw(w.cw);
}
led_driver_show(leds, RING_NUM_LEDS);
```

The downlight now goes straight through `white_mix_gamma()` from `src/brightness.h`, unchanged —
which is the payoff for having done item 6 first.

The scene reload guard in `loop()` keys on `s->ring.scene` rather than `s->scene`.

**One easily-missed edit:** the NVS corruption guard at `src/main.cpp:92` currently reads

```cpp
if (p.type >= EFFECT_COUNT) p.type = EFFECT_STATIC_WHITE;
```

and `EFFECT_STATIC_WHITE` is one of the two enumerators being deleted, so this stops compiling. Its
fallback becomes `EFFECT_WARM_GRADIENT` — the new index 0, and a ring effect, which is what the
guard should have been reaching for all along now that the ring owns the effect table.

### 3.6 `zigbee_light.cpp`

A small hierarchy keeps the raw `esp_zb` plumbing in one place:

```
LumaryEndpoint : ZigbeeColorDimmableLight    // publishState(on, level), setAttr, reportAttr
  LumaryDownlight : LumaryEndpoint           // + Basic string attrs, OTA client
  LumaryRing      : LumaryEndpoint           // + cluster 0xFC00, publishState(on, level, effect)
```

Callbacks are registered per endpoint object and carry no endpoint id, so each endpoint gets its own
static callback functions. The `s_last_r/g/b` colour-change detection (`src/zigbee_light.cpp:139`)
moves to the ring only — the downlight has no colour capability and receives colour-temperature
commands directly, so it needs no equivalent.

`publish_effect_attr()` targets `RING_ENDPOINT`. `zigbee_light_loop()`'s join-time publish covers
both endpoints.

`src/config.h` replaces `LIGHT_ENDPOINT 1` with `DOWNLIGHT_ENDPOINT 1` and `RING_ENDPOINT 2`.

### 3.7 NVS migration is one line

`NVS_FMT_VER_CURRENT` goes 1 to 2. `scene_store_init()` already discards and reseeds when the stored
version does not match, so bumping it *is* the migration: scenes stored against the old eight-entry
indices are dropped and reseeded from the new six-entry `kDefaultParams`. No new code.

## 4. Testing

`test/test_light_state` is rewritten around the two resolves. It loses its `WHITE_SAT_THRESHOLD` and
`rgb_to_cct` coverage along with those functions, and gains:

| Test area | What it asserts |
|---|---|
| Downlight gating | `on == false` yields level 0 whatever `level` holds; `on == true` passes it through |
| Downlight CCT | `mireds_to_cct` endpoints and midpoint still map as before |
| Ring mode transitions | a colour command moves `MODE_SCENE` to `MODE_COLOR`; selecting a scene moves it back |
| Ring scene validation | an out-of-range index is ignored outright, leaving scene and mode untouched |
| Effect value reporting | `MODE_COLOR` reports `LIGHT_EFFECT_NONE`; `MODE_SCENE` reports the index |
| Effect table | `EFFECT_COUNT == 6`; `kDefaultParams` and `kEffects` are both that long; every default's `type` is in range |

`z2m/test/converter.test.mjs` grows to cover the endpoint map, two `m.light()` extends, the six-entry
effect list, and that the effect expose is on endpoint 2.

`test_brightness`, `test_pixel_encode`, `test_version` and `test_identify` are untouched.

## 5. Risks

1. **`ZigbeeColorDimmableLight` configured `COLOR_TEMP`-only** keeps the `HA_COLOR_DIMMABLE_LIGHT`
   device ID. Z2M should read `colorCapabilities` and present a colour-temperature light, but this
   is the first thing to check when the fixture joins.
2. **One OTA client across two endpoints.** The library's OTA support was written against
   single-endpoint examples; needs confirming it does not assume the OTA endpoint is the only one.
3. **Two `ZigbeeColorDimmableLight` instances.** `ZigbeeCore::addEndpoint` pushes onto a list and the
   callback dispatch loops over it, so multi-endpoint is supported by construction — but this
   firmware has only ever registered one, so it is unproven here.
4. ~~Inovelli `On`/`Off` vs `Toggle`~~ — **resolved 2026-08-17: discrete `On`/`Off`.** See §2.2.

## 6. Migration for fixtures already in service

Adding an endpoint changes the device descriptor, and **Z2M caches endpoints from the interview** —
the same mechanism that made `sw_version` read `null` until re-interview in item 5.

So: newly paired fixtures just work; **every fixture already in service needs a re-interview** (Z2M
frontend, or `zigbee2mqtt/bridge/request/device/interview`) before the ring entity appears. This
belongs in the README prominently, not as a footnote.

Two further consequences of the same change:

- **Old converter, new firmware:** endpoint 1 works as a plain light and endpoint 2 is invisible.
  Degraded, not broken — which matters because the firmware and the converter update independently.
- **Automations naming the two dropped effects** (`static_white`, `static_color`) stop working, per
  §2.1. The README should say so and name the replacements: the Downlight entity, and `effect: none`
  with a colour.

## 7. Out of scope

- **Power-on behaviour** (item 2b). The downlight's colour temperature and level still do not persist
  across a power cut; that is `StartUpOnOff` and friends, and it is its own item.
- **Transitions** (item 3), **effect parameters** (item 7), **binding and reporting configuration**
  (item 8), **upstreaming the converter** (item 10), **the switch blueprint** (item 11).
- **Per-endpoint effect parameters.** Item 7 asked whether effect parameters are per-endpoint or
  global; with effects now belonging solely to the ring, the question dissolves — they are the
  ring's.

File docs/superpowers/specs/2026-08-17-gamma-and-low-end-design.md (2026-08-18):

# Gamma and the low end — design

**Date:** 2026-08-17
**Status:** approved, ready for implementation

Item 6 of `docs/superpowers/plans/2026-08-17-home-assistant-polish.md`. Taken before items 3 and 9
because it is the last item that is genuinely orthogonal to the two-endpoint split: item 9 balances
the downlight against the ring by eye, and tuning that balance on an uncorrected brightness curve
means tuning it twice.

## 1. Problem

`scale8` feeds both the ring and the 8-bit PWM linearly, so Home Assistant's brightness slider is
non-linear against perceived output: the bottom third does very little and then jumps. The backlog
described the fix as "a gamma LUT on the ring and a minimum duty floor on CW/WW".

### 1.1 The obvious fix makes it worse

A gamma LUT alone regresses the exact region it is meant to repair. With the current 8-bit PWM
(`src/config.h:43`), γ=2.2 maps every input below 15 to duty **0**:

| HA brightness | today (linear) | γ2.2 @ 8-bit | γ2.2 @ 12-bit | CIE L\* @ 8-bit | CIE L\* @ 12-bit |
|---|---|---|---|---|---|
| 1 | 1 | **0** | **0** | **0** | 2 |
| 5 | 5 | **0** | 1 | 1 | 9 |
| 8 | 8 | **0** | 2 | 1 | 14 |
| 13 | 13 | **0** | 6 | 1 | 23 |
| 26 | 26 | 2 | 27 | 3 | 47 |
| 64 | 64 | 12 | 196 | 11 | 182 |
| 128 | 128 | 56 | 899 | 47 | 761 |
| 255 | 255 | 255 | 4095 | 255 | 4095 |

First input that produces any light at all:

| | first non-zero input |
|---|---|
| γ2.2 @ 8-bit | 15 |
| γ2.2 @ 12-bit | 5 |
| CIE L\* @ 8-bit | 5 |
| CIE L\* @ 12-bit | **1** |

> **Correction (post-implementation review):** the "CIE L\* @ 8-bit" row and its "first non-zero
> input: 5" describe the *table's* output, not the ring's drive value. The ring composes the table
> through `scale8(val, scale) = (val * scale) >> 8` (`src/color.h`), where the table entry is the
> `scale` argument. A table entry of 1 is a real, intended floor value, but `(255 * 1) >> 8 == 0` —
> the `>> 8` throws it away for every channel below full value, and even at full value the whole
> `kGamma8[b] == 1` band (`b` in 1..13) composes to zero. First non-zero *drive* on the ring is
> therefore 14, not 5, with a naive `scale8` composition. The implementation avoids this by
> composing with `scale_by_255` (divide by 255) instead of `scale8`'s shift, which is what actually
> gets the ring to brightness 1. See `src/brightness.h`'s `scale_by_255` and the design correction in
> §3.1 below.

So the bottom of the slider is not dead because the curve is wrong. It is dead because **8 bits of
output cannot represent a gamma-corrected low end**. Task 6.3 already swept the white string to zero
duty with no steps, flicker or dropouts, so the hardware is not the limit — quantisation is.

The fix is therefore two coupled changes: a perceptual curve *and* more output resolution beneath
it. The "minimum floor" then falls out as a `max(1, …)` guard rather than a tuned constant.

### 1.2 The curve belongs on the brightness scalar, not on output channels

Because gamma is non-linear, `gamma(a × b) ≠ gamma(a) × b`. Applying the curve to each output
channel independently therefore distorts every *ratio* between channels — and on the white string
that ratio is the colour temperature.

Measured against the intended mix at `level=255, hue=64` (a 191:64 CW/WW split):

| | ww | cw | ratio |
|---|---|---|---|
| intended (linear mix) | 191 | 64 | 2.98 : 1 |
| gamma the total, split linearly | 3067 | 1027 | **2.99 : 1** |
| gamma each leg separately | 1971 | 182 | 10.83 : 1 |

Per-leg gamma would make the fixture drift sharply warm as it dims. The same argument applies to any
fixed colour mix on the ring — `warm_white()`'s {255, 169, 87} and `fx_warm_gradient`'s warm→blue
crossfade both distort the same way.

The correct operation follows from the physics: a pixel's luminous output is linear in its drive
value, so to make a colour appear at some perceptual lightness, every channel is scaled by the same
*gamma-corrected scalar*. That is `drive = original_drive × gamma(brightness)` — the curve applied
once, to the brightness, before it is mixed into either source.

## 2. Decisions

| Decision | Choice | Why |
|---|---|---|
| Curve | CIE 1931 lightness | Its linear segment below L\*=8 is what reaches brightness 1; a plain power law cannot |
| White PWM resolution | 8-bit → 12-bit | Somewhere to put the corrected low end; 1 kHz from the 32 MHz XTAL allows ~14 bits, so 12 has margin |
| Ring resolution | unchanged, 8-bit | Fixed by the LED protocol |
| CCT while dimming | constant | Matches what HA asked for; warm-dim stays a possible deliberate feature, not an artifact |
| Where the curve applies | in the effects, on the composed brightness | The only point that knows the final instantaneous value |

### 2.1 Why not at the driver boundary

One chokepoint in `led_driver_set_cw/ww` and `led_driver_show` would leave the effects untouched,
but by then brightness is already multiplied into the channels — this is exactly the per-channel
case §1.2 rules out.

### 2.2 Why not in `light_state_resolve()`

A single point, already host-tested, no effect changes. But effects modulate brightness *after*
resolve: `fx_breathing` multiplies by a triangle wave (`src/effects.cpp:70`), `fx_warm_gradient` by a
per-pixel spatial ramp (`src/effects.cpp:45`). Curving before those means the envelope rides on an
already-curved value, so the breathing fade rushes at one end and the gradient bunches up. Correct
for plain on/off/dim, wrong for six of the eight effects.

## 3. Design

### 3.1 New module: `src/brightness.h`

Pure, free of ESP-IDF headers, following `pixel_encode.h` / `light_state.h` / `version.h` so the host
tests reach it. Depends on `color.h`; only `effects.cpp` depends on it.

```c
uint8_t  gamma8 (uint8_t brightness);   // ring:  8-bit in -> 8-bit out
uint16_t gamma12(uint8_t brightness);   // white: 8-bit in -> 12-bit out
CRGB     scale_brightness_gamma(CRGB c, uint8_t brightness);
```

Both implement the CIE 1931 lightness curve:

```
L* = brightness / 255 x 100
Y  = L* / 903.3            for L* <= 8      <- linear segment
Y  = ((L* + 16) / 116)^3   for L* > 8
```

`scale_brightness_gamma` lives here rather than in `color.h` so the dependency points one way.

**Two 256-entry lookup tables**, 256 B + 512 B of flash. Not computed at runtime — the ESP32-H2 is
RISC-V with no FPU, so `pow` is soft-float. Not `constexpr`-generated either: `std::pow` is not
constexpr in C++17, which is what the test runner builds with (`scripts/run-native-tests.bat:40`).
A generator script under `scripts/` emits the tables, and the host test recomputes the formula in
`double` and asserts all 512 entries match, so the table cannot silently rot.

**The floor is not a tuned constant.** `gamma12` already yields 2 at brightness 1, so it never
triggers there. `gamma8` yields 0 for brightness 1–4 only, so a `max(1, …)` guard on non-zero input
catches exactly those four — the ring's hardware limit, stated rather than chosen.

> **Correction (post-implementation review):** `gamma8`/`kGamma8` return a *multiplier*, not a drive
> value — composing them into a pixel channel still has to happen, and that composition matters. The
> obvious composition, `scale8(val, scale) = (val * scale) >> 8`, turns a multiplier of 1 into a
> drive of 0 for any channel value, silently discarding the very floor described above: `kGamma8[b]
> == 1` for `b` in 1..13, so all thirteen of those inputs composed to zero via `scale8`, widening the
> ring's dead zone instead of removing it (first light moved from brightness 2 to brightness 14).
> `scale_brightness_gamma` in `src/brightness.h` therefore composes with `scale_by_255(v, s) =
> (v * s) / 255` instead — ordinary integer division rather than a `>> 8` shift — so a multiplier of
> 1 against a full-value channel yields 1, and the table's floor actually reaches the LED. The same
> fix applies to `warm_white_gamma` (`src/brightness.h`), used by `fx_nightlight`, since
> `color.h`'s `warm_white()` has the identical `scale8` exposure.

### 3.2 `config.h` and `led_driver`

- `PWM_RESOLUTION` → `LEDC_TIMER_12_BIT`, new `PWM_DUTY_MAX` = 4095
- `led_driver_set_cw` / `led_driver_set_ww` widen from `uint8_t` to `uint16_t`

`ledc_set_duty` already takes `uint32_t`, so nothing inside changes. The existing `ESP_ERROR_CHECK`
on `ledc_timer_config` (`src/led_driver.cpp:32`) means an invalid resolution/frequency pair panics at
boot rather than misbehaving quietly.

### 3.3 The effects

All eight entries in `kEffects` change; only two need thought. `fx_identify` is a ninth function
outside that table and is untouched.

| Effect | Change |
|---|---|
| `fx_static_color`, `fx_color_gradient`, `fx_breathing`, `fx_color_cycle`, `fx_chase` | rename `scale_brightness` → `scale_brightness_gamma`, one line each |
| `fx_nightlight` | `warm_white(p.brightness)` → `warm_white_gamma(p.brightness)` (see the §3.1 correction — `warm_white(gamma8(…))`, which this section originally specified, carries the same `>>8` bug) |
| `fx_static_white` | the 12-bit split, below |
| `fx_warm_gradient` | rework, below |
| `fx_identify` | untouched — a fixed full-output blink with no brightness input |

**`fx_static_white`** curves the level once, then splits linearly so CCT is exact:

```c
const uint16_t total = gamma12(level);
led_driver_set_ww(uint16_t(uint32_t(total) * (255 - p.hue) / 255));
led_driver_set_cw(uint16_t(uint32_t(total) *        p.hue  / 255));
```

The intermediate is `uint32_t` because `total` reaches 4095 and the multiply would otherwise
overflow 16 bits; the result is capped at `total`, so the narrowing cast back to `uint16_t` is
explicit rather than left to an implicit conversion that `/W3` would flag.

`/255` rather than `scale8`'s `>>8`: the shift maps a full 255 mix to 254/255 of the total, so pure
warm would never quite reach full duty. This is the same off-by-one `scale_level` already works
around (`src/light_state.h:85`). The two coefficients sum to 255, so total output stays constant
across CCT exactly as it does today.

**`fx_warm_gradient`** is the one effect where per-leg gamma would distort a ratio the same way CCT
does — it crossfades a warm colour to blue across the ring with brightness folded into each leg.
Restructured to blend at full intensity and curve once:

```c
const CRGB c = blend(CRGB{200, 100, 0}, CRGB{0, 0, 255}, pos);
leds[i] = scale_brightness_gamma(c, p.brightness);
```

This gives `blend()` (`src/color.h:48`) its first caller — it is currently dead code.

> This changes the rendered gradient slightly **even at full brightness**, because the current
> version is not a true blend. It is the one effect to eyeball on the bench rather than merely check
> dims smoothly.

## 4. Testing

New `test/test_brightness/test_main.cpp`. The runner discovers `test\test_*` automatically
(`scripts/run-native-tests.bat:28`), so no script change is needed.

| Test | Guards against |
|---|---|
| All 512 LUT entries match the CIE formula recomputed in `double` | table rot |
| Monotonic non-decreasing | a step backwards anywhere on the slider |
| `gamma8(255)==255`, `gamma12(255)==4095`, both zero at zero | endpoint drift |
| **Non-zero in → non-zero out, all 255 inputs** | the original bug, and its 8-bit reappearance |
| CCT split holds the mix ratio within ±1 LSB across a (level, hue) grid | §1.2 regression on white |
| `scale_brightness_gamma` preserves channel ratios | someone "simplifying" it back to per-channel gamma |

## 5. Risk

**Frequency is unchanged at 1 kHz**, so the L-SD8E1 sees the same switching rate it already passed
Task 6.3 with. But minimum on-time drops 16×: duty 1/4095 is a 0.24 µs pulse against 3.9 µs today.
The driver's control loop may not respond that fast, in which case the bottom of the 12-bit range
produces no light and brightness 1 is still off — the original bug, relocated.

The bench sweep tests exactly this. If a real threshold exists, the `max(1, …)` guard becomes a
*measured* minimum duty instead. **The floor is provisional by design.**

## 6. Bench verification

All USB-side with the fixture on the bench; no dependency on Task 6.4.

- [ ] Sweep HA brightness 1 → 255: no dead zone at the bottom
- [ ] The perceived ramp is even, with no jump out of the low end
- [ ] CCT holds constant while dimming, checked at 2700 K, 4000 K and 6500 K
- [ ] `fx_warm_gradient` still looks right at full brightness after the rework
- [ ] All eight effects dim smoothly

## 7. Out of scope

- **Temporal dithering** for the ring's bottom four steps. The ring is the accent, not the main
  light; revisit only if it looks bad.
- **Warm-dim.** Possible later as a deliberate opt-in; it is not to arrive as an artifact.
- **Transitions** (item 3). The slew is a separate change and lands after this one.
- **Ring output resolution.** Fixed at 8-bit by the LED protocol; only the white string gains bits.

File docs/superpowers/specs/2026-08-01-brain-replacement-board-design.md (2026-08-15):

# Lumary "Brain" Replacement Board — Design Spec

**Date:** 2026-08-01
**Status:** Design approved — pending Phase 0 measurements before schematic
**Goal:** A custom PCB that is a true drop-in replacement for the stock Tuya controller
(`KOK-AH-A172C REV:A`) inside the Lumary 6" RGBAI recessed light, running the existing
`lumary-zigbee` ESP32-H2 firmware. One board design, deployed across all identical fixtures.

---

## 1. Objective & success criteria

Replace the stock Tuya WiFi "brain" in every identical Lumary 6" fixture with a custom
ESP32-H2 Zigbee board that **plugs into the existing harnesses with zero rewiring**.

Done means:
- Same board outline, mounting, and both connectors (power-in + `CN1`) as the stock board,
  so it physically swaps in.
- Drives the existing loads correctly: tunable-white inner ring (current-steered CCT) +
  addressable RGB outer "gradient" ring.
- Runs the current firmware with only a pin-map change.
- Manufacturable as a fully-assembled board via JLCPCB PCBA.
- Deliverable: a complete KiCad project → Gerbers + BOM + CPL ready for JLCPCB.

**Non-goals (YAGNI):** universal/multi-fixture controller, bare-chip RF design, on-board AC/DC
conversion (the external `L-SD8E1` driver stays), field-accessible buttons.

---

## 2. Locked decisions

| Decision | Choice | Rationale |
|---|---|---|
| Product type | True drop-in for Lumary 6" lights | Many identical fixtures; zero-rewire swap |
| LED load | Mixed: addressable outer ring + analog tunable white inner ring | Measured/confirmed |
| Manufacturing | JLCPCB PCBA (fully assembled) | Consistent units, fine-pitch + certified module usable |
| Architecture | **Option 1** — integrated board with soldered **ESP32-H2-MINI-1** | Best cost/reliability at qty; RF de-risked by pre-certified module; firmware ports easily |
| Programming | USB-C onboard (native USB-CDC) + auto-reset | Keeps current dev workflow; convenient bench iteration |
| Final deliverable | Full KiCad project → JLCPCB | (Physical routing likely finished/verified by a human in KiCad) |

---

## 3. Measured facts (Phase 0 partial — already established)

### External driver `L-SD8E1`
- Input: 120 VAC / 60 Hz / 0.2 A, PF > 0.9
- **Output: 35.8 V, 380 mA (max) — constant-current**, ~13.6 W
- Three output wires (map onto the stock board's power-in connector):

| Wire | Measured | Stock pin | Meaning |
|---|---|---|---|
| White | GND | `GND` | Ground |
| **Blue** | **36.63 V** | `V+` | Constant-current LED-string rail (380 mA to 35.8 V compliance) |
| **Red** | **4.7 V** | `5V+` | Low-power logic + addressable-ring rail |

### Inner white ring — strip `8C18W-12C4B-2835X2-588×7.5mm V1.0`
(The `8C18W` prefix likely encodes the cool/warm LED counts — cross-check against P0.5 series count.)
Tunable-white **current-steering** design, common anode, two low-side cathode returns:

| Strip pad | Role | Maps to `CN1` | Harness wire |
|---|---|---|---|
| `LED+` | Common anode (from `V+`, 36 V) | `V+` | black |
| `65K-` | 6500 K cool-white cathode return | `CW-` | white |
| `27K-` | 2700 K warm-white cathode return | `WW-` | yellow |

The board **does not source** the white current — the driver does. The board **sinks/steers**
the 380 mA on the low side: PWM total on-time → brightness; CW:WW ratio → color temperature.
Likely ~12 white LEDs in series per color (the `12C`), putting string voltage close to 36 V →
near-zero headroom across the low-side regulators → very low heat.

### Outer ring
Addressable RGB "gradient auxiliary" ring on `CN1` `+A`/`-A`, powered from the 4.7 V rail.
Firmware targets SK6812 (36-LED). Exact chip/pixel-count/protocol **not yet confirmed**
(`digital.csv` capture was noise/mis-triggered — unusable). Does not affect board architecture.

---

## 4. Architecture

Single 4-layer PCB, stock outline + both connectors. Brain = soldered ESP32-H2-MINI-1.
Everything downstream reproduces the stock board's behaviour for the LED module.

```
  Driver harness (in)                Replacement board                       LED module (CN1, out)
 ┌──────────────────┐   ┌───────────────────────────────────────────┐   ┌────────────────────────┐
 │ V+  = 36.63V CC ─┼─► │  V+ ──────────────────────────────────────┼─► │ LED+  (white anode)    │
 │ 5V+ = 4.7V      ─┼─► │  4.7V ─┬─[diode-OR]─►[3.3V LDO]─► 3.3V      │   │                        │
 │ GND             ─┼─► │        │              │  ┌────────────────┐│   │                        │
 └──────────────────┘   │  USB 5V┘              └─►│ ESP32-H2-MINI-1││   │                        │
                        │  (bench flash)           └─┬───┬───────┬──┘│   │                        │
                        │              GPIO(CW-PWM)  │   │(WW-PWM)│data│   │                        │
                        │                            ▼   ▼        ▼   │   │ CW-(65K) WW-(27K)      │
                        │              [≥60V CC sink][≥60V CC sink][3.3│   │ +A(data) -A(gnd/ret)   │
                        │                    │           │      →4.7V ├─► │ 4.7V rail for ring     │
                        │                    └───────────┴───buffer]─┼─► │                        │
                        │  USB-C + ESD + auto-reset, BOOT/EN btns     │   │                        │
                        └───────────────────────────────────────────┘   └────────────────────────┘
```

### 4.1 Power stage
- **3.3 V (module):** LDO from a **diode-OR of the 4.7 V rail and USB-VBUS** → boots/flashes on
  USB alone at the bench, runs off 4.7 V installed. 36 V section stays fully isolated from USB.
- **Ring rail:** the 4.7 V rail feeds the outer ring directly (not through the LDO). Current
  budget is limited (driver has only a few spare watts after 13.6 W of white) — firmware
  brightness cap protects it.
- **Input protection:** reverse-polarity (series P-FET or Schottky) + TVS + bulk cap on the
  low-voltage input. Respect creepage/clearance around the 36 V net.

### 4.2 Inner white output (tunable CCT)  — REVISED to MOSFET switches
The external driver is confirmed **constant-current** (380 mA), so the board only **gates** each
channel; it does not regulate current (the stock `HT7308` linear regs existed for the stock board's
*analog* dimming — we dim digitally by PWM).
- Two **logic-level N-MOSFET low-side switches** on `CW-`/`WW-`, PWM'd from the module's LEDC
  channels. Brightness = duty; CCT = cool:warm duty ratio. No sense resistors.
- **+ 36 V bulk cap** (10 µF/50 V) for switch-on inrush (mirrors the stock 4.7 µF/50 V caps).
- **Ratings:** MOSFET Vds **≥60 V** (CC source rails to 35.8 V compliance when off), logic-level,
  Id ≥ 0.5 A. On-state loss ≈ I²·Rds(on) ≈ 1.5 mW — negligible, no thermal concern.
- **Firmware:** may need `PWM_FREQ_HZ` lowered to ~0.5–2 kHz so the CC driver tracks PWM cleanly
  (bring-up tuning, Phase 6).

### 4.3 Outer ring output (addressable)
- Module data GPIO (firmware's SPI2-MOSI NZR encoding) → **3.3 V→4.7 V level buffer**
  (`SN74LVC1T45` or `74AHCT1G125`) → `CN1` data pin, series damping resistor ~150–330 Ω.
- Final `+A`/`-A` mapping confirmed in Phase 0 (P0.3).

### 4.4 MCU / RF / programming
- **ESP32-H2-MINI-1** soldered; PCB antenna at board edge with copper keepout, oriented toward
  the fixture opening (away from metal can). Same location the stock 2.4 GHz module used.
- **USB-C** → native USB (D+/D−), ESD protection, DTR/RTS **auto-reset** (EN + IO9).
- `BOOT`(IO9) + `EN` buttons for bench recovery.

### 4.5 Field control (buttons sealed once installed)
- **Zigbee OTA** = primary update path (works installed).
- **Reset / re-pair** = firmware **power-cycle pattern** (flip switch N times); no reachable
  button needed.
- ⚠️ BLE-OTA-on-BOOT-hold becomes unusable once installed → re-trigger via power-cycle pattern
  or drop it. (Firmware decision, tracked separately.)

---

## 5. Phase 0 — remaining reverse-engineering (gate before schematic)

| # | Measure | How | Status |
|---|---|---|---|
| P0.1 | Power-in + `CN1` connector pin count, **pitch**, part family (JST SH/GH/ZH/PH) | Calipers + continuity | TODO |
| P0.2 | Input rail voltages/polarity | DMM | **DONE** — 36.63 V / 4.7 V / GND |
| P0.3 | `CN1` full pin order; confirm `+A`/`-A` = ring data/return | Continuity trace | **DONE** (2026-08-14) — stock silkscreen reads `V+ · CW- · WW- · 5V+ · GND · DIM`, 6 signals in that order, matching rev A `J2` pins 1–6. There is no separate `+A`/`-A` pair: the ring shares `5V+`/`GND` and takes data on `DIM`. Harness carries 6 wires (black, white, yellow, red, teal, blue). |
| P0.4 | Outer ring: chip type, pixel count, protocol | Read pixel marking / clean re-capture | **DONE** (2026-08-15, Saleae capture at both ends of the data lead). 62 px × 24 bits = **1488 bits in every one of 316 frames**; **RGB** wire order, not GRB; 16.00 ms frame period. Exact part still unmarked, but its timing rules out plain WS2812B: at `T0H` 417 ns (WS2812B nominal) ~11% of frames showed a single corrupted pixel; at **312 ns** it is clean. That is SK6812-family behaviour (`T0H` max 450 ns). |
| P0.5 | White sub-string series count + `HT7308` sense-resistor value → CC setpoint & headroom/heat | Read markings + DMM | TODO |
| P0.6 | Board outline, mounting holes/standoffs, **max component height**, antenna keepout region | Calipers / flatbed scan | TODO |

---

## 6. BOM (JLCPCB-stockable; verify LCSC stock at finalize)

ESP32-H2-MINI-1 · 3.3 V LDO · diode-OR Schottkys · 3.3→4.7 V data buffer · 2× ≥60 V low-side
CC sink stage (`HT7308`-class or MOSFET+sense) · USB-C + ESD array · reverse-polarity FET +
TVS · 2× JST connectors (matched in P0.1) · BOOT/EN buttons · passives.
Estimated **~$5–8 / assembled board** small qty, less at volume.

---

## 7. Firmware impact (small)

- Remap pins in `src/config.h` to the new layout.
- Level-shift target is **4.7 V**, not 5 V.
- Add power-cycle reset / OTA-entry trigger; reconcile BLE-OTA fallback.

---

## 8. Validation ladder

1. **USB-only bring-up:** module boots, USB-CDC serial, Zigbee joins.
2. **+4.7 V rail + outer ring:** ring lights, level-shift verified.
3. **+36 V CC string on a current-limited bench supply:** CW/WW steering, CCT sweep, dimming,
   thermals under sustained load.
4. **In-fixture swap:** true drop-in fit, RF range, Zigbee binding to Inovelli switch, OTA.

---

## 9. Deliverable workflow (→ full KiCad → JLCPCB)

Schematic → assign LCSC parts + footprints → layout (scaffold placement + critical routing;
finish/verify routing + DRC in KiCad) → Gerbers + BOM + CPL → JLCPCB PCBA.

---
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

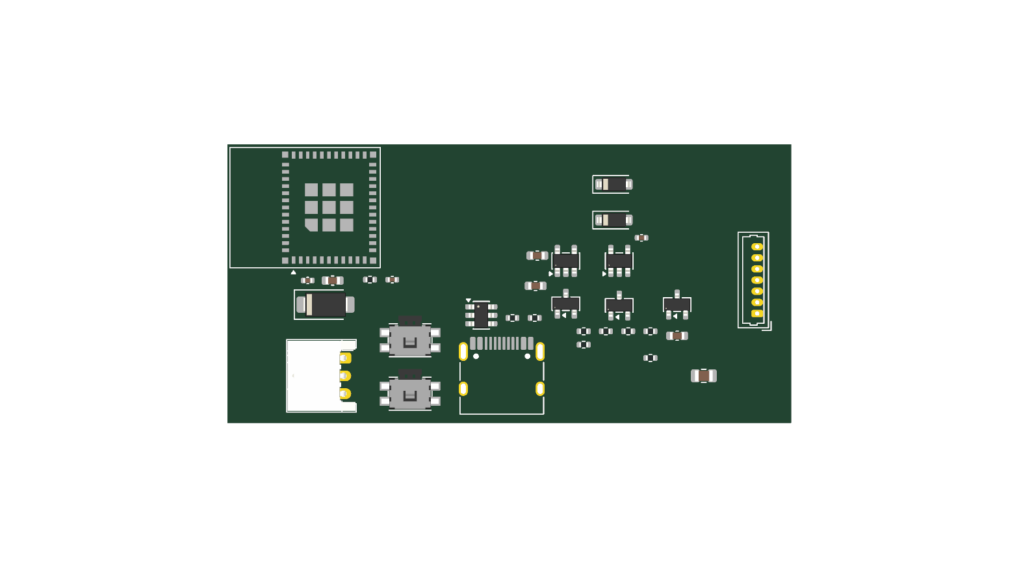
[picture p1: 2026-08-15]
hardware/kicad/board-top3.png

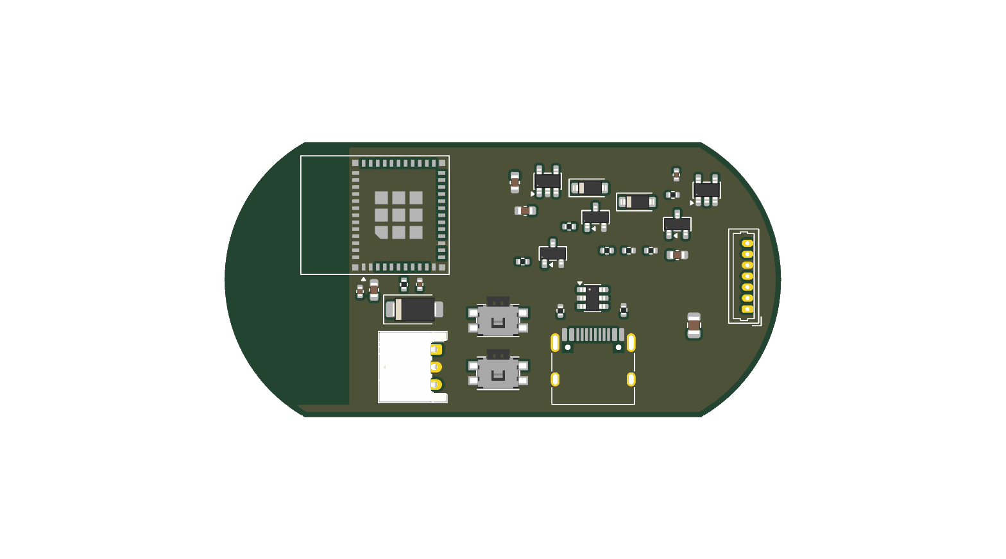
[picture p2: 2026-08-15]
hardware/kicad/board-user2.png

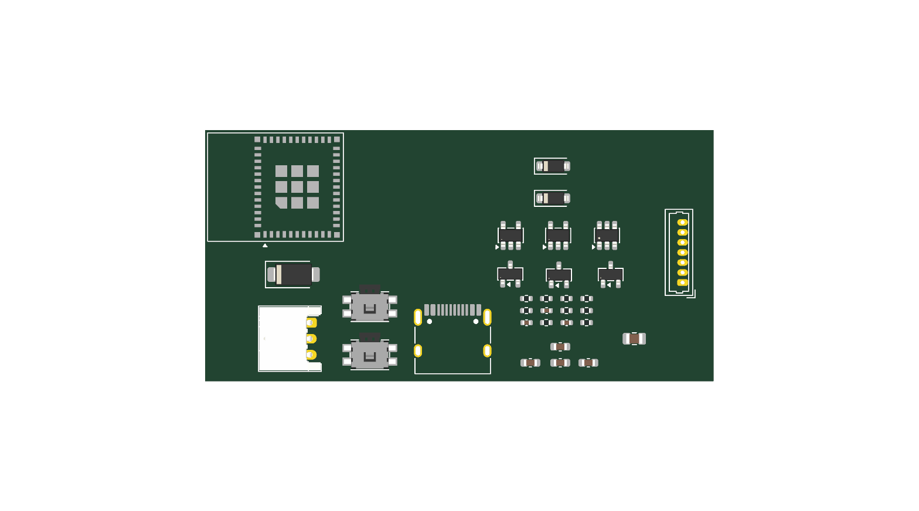
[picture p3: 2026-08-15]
hardware/kicad/board-top2.png

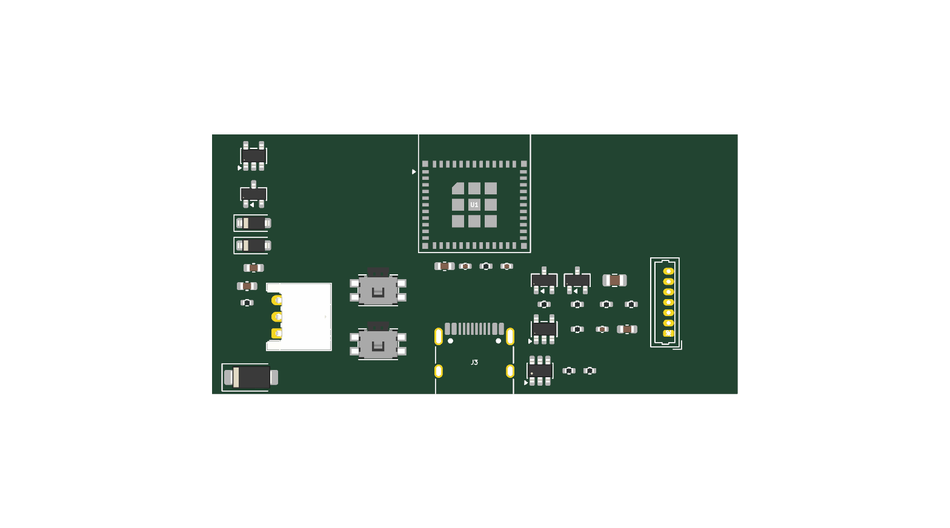
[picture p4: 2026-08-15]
hardware/kicad/board-top.png

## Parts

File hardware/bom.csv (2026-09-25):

Designator | Qty | Comment/Value | Footprint | LCSC | Status | Notes
U1 | 1 | ESP32-H2-MINI-1-H4S | MINI-1 LGA module | C47967030 | CONFIRMED | MCU+Zigbee radio; 4MB flash; PCB antenna (non-U variant). Rev B: replaces discontinued -N4 (C18203134); chip v1.2, 105C rated, same footprint
U2 | 1 | ME6211C33M5G-N (3.3V LDO) | SOT-23-5 | C82942 | CONFIRMED | From diode-OR of +4V7/USB; 260mV dropout @200mA
U3 | 1 | 74AHCT1G125 (buffer/level shift) | SOT-23-5 | C7484 | CONFIRMED | 3.3->4.7V ring data; want AHCT (VIH=2V). Fallback 74AHC1G125GW C85397 (AHC, marginal)
U4 | 1 | USBLC6-2SC6 (USB ESD) | SOT-23-6 | C7519 | CONFIRMED | ESD on USB D+/D-/VBUS
Q1 | 1 | N-MOSFET >=60V logic-level (CW sink) | SOT-23 | C347492 | CONFIRMED | Switches CW- low side; candidate Nexperia PMV120ENEAR (60V 2.1A). Gate from GPIO2
Q2 | 1 | N-MOSFET >=60V logic-level (WW sink) | SOT-23 | C347492 | CONFIRMED | Switches WW- low side; same PN as Q1. Gate from GPIO3
Q3 | 1 | AO3401A (P-MOSFET rev-polarity) | SOT-23 | C15127 | CONFIRMED | Reverse-polarity block on +4V7 input
D1 | 1 | B5819W Schottky (4V7 diode-OR) | SOD-123 | C8598 | CONFIRMED | +4V7 -> LDO_IN
D2 | 1 | B5819W Schottky (USB diode-OR) | SOD-123 | C8598 | CONFIRMED | USB VBUS -> LDO_IN (bench flash)
D3 | 1 | SMAJ5.0A TVS | SMA | C113952 | CONFIRMED | Transient clamp on +4V7 input
J1 | 1 | JST-PH 2.0mm 3-pin (power-in) | B3B-PH-K-S TH | C157929 | CONFIRMED | GND/36V/4V7 in; polarized; parallel solder pads on same nets
J2 | 1 | ZH 1.5mm 7-pos side entry (CN1 out) | S7B-ZR-SM4A-TF 1.5mm 7P SMD | C5118704 | CONFIRMED | To LED module; 6 populated per P0.3 pinout; JLC-assembled from rev B (genuine JST; Extended part)
J3 | 1 | TYPE-C-31-M-12 (USB-C) | USB-C 16P SMD | C165948 | CONFIRMED | Native USB + bench 5V
SW1 | 1 | Tact switch (BOOT/IO9) | SMD 2-pin | C128539 | CONFIRMED | Bench download-mode
SW2 | 1 | Tact switch (EN/reset) | SMD 2-pin | C128539 | CONFIRMED | Bench reset
C1 | 1 | 10uF 50V bulk (+36V rail) | 0805 | C440198 | CONFIRMED | Absorbs switch inrush; mirrors stock 4.7uF/50V
C2 | 1 | 10uF (LDO out +3V3) | 0603 | C19702 | CONFIRMED | LDO output cap
C3 | 1 | 1uF (LDO in) | 0603 | C15849 | CONFIRMED | LDO input cap
C4 | 1 | 10uF (+4V7 bulk) | 0603 | C19702 | CONFIRMED | Ring rail bulk
C5 | 1 | 10uF (module bulk 3V3) | 0603 | C19702 | CONFIRMED | ESP32-H2 bulk decoupling
C6 | 1 | 100nF (module 3V3) | 0402 | C1525 | CONFIRMED | ESP32-H2 HF decoupling (close to pin)
C7 | 1 | 100nF (buffer U3) | 0402 | C1525 | CONFIRMED | U3 decoupling
C8 | 1 | 1uF (EN RC) | 0402 | C52923 | CONFIRMED | EN power-on delay
R1 | 1 | 100R (Q1 gate) | 0402 | C25076 | CONFIRMED | GPIO2 -> Q1 gate
R2 | 1 | 100R (Q2 gate) | 0402 | C25076 | CONFIRMED | GPIO3 -> Q2 gate
R3 | 1 | 100k (Q1 gate pulldown) | 0402 | C25741 | CONFIRMED | Hold Q1 off at boot
R4 | 1 | 100k (Q2 gate pulldown) | 0402 | C25741 | CONFIRMED | Hold Q2 off at boot
R5 | 1 | 200R (ring data series) | 0402 | C25087 | CONFIRMED | U3 out -> CN1.DIM damping
R6 | 1 | 10k (EN pullup) | 0402 | C60489 | CONFIRMED | EN -> 3V3
R7 | 1 | 5.1k (USB CC1) | 0402 | C25905 | CONFIRMED | USB-C CC1 pulldown
R8 | 1 | 5.1k (USB CC2) | 0402 | C25905 | CONFIRMED | USB-C CC2 pulldown
R9 | 1 | 100k (Q3 gate ref) | 0402 | C25741 | CONFIRMED | Reverse-polarity P-FET gate -> GND

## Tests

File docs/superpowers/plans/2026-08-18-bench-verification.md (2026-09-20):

# Bench verification — everything outstanding

**Date:** 2026-08-18
**Status:** in progress — §§1-9 done 2026-08-18; §10 partial; §11 in progress (installed in the loft 2026-09-15)

Three separate bodies of work are merged to `main` and unverified on hardware. This consolidates
their outstanding checks into one session, in an order chosen so that each check does not mask the
next.

| Source | What it left open |
|---|---|
| Item 6 — gamma and the low end | `2026-08-17-gamma-and-low-end.md` Task 5 |
| Item 9 — two light entities | `2026-08-17-two-endpoint-split.md` bench section, plus the final review's watch list |
| Board rev A | `2026-08-01-brain-replacement-board.md` Task 6.4, and two caveats from 6.3 |

**The single question underneath all of it:** the white string's PWM went from 8-bit to 12-bit, so
minimum on-time dropped from 3.9 µs to 0.24 µs. Whether the L-SD8E1's constant-current loop responds
at all down there is what no host test can settle, and both merged features depend on the answer.

---

## Before you start

- [ ] Fixture on the bench, USB for the module, real L-SD8E1 driver for the 36 V string
- [ ] Z2M running with `z2m/lumary-brain-revA.js` installed in `data/external_converters/`
- [ ] Somewhere to write numbers down — several steps below want a measured value, not a pass/fail

Flash first:

```bash
pio run -e esp32h2 --target upload
```

Expected: `boot ok` then `LED driver init ok` on the monitor.

> **A panic at `ledc_timer_config` means 12-bit at 1 kHz was rejected.** `ESP_ERROR_CHECK` in
> `src/led_driver.cpp` makes that loud rather than silent. If it happens, drop to
> `LEDC_TIMER_10_BIT` with `PWM_DUTY_MAX` 1023 and regenerate `kGamma12` by passing `1023` to
> `emit()` in `scripts/gen-gamma-tables.py`.

> **A panic before `boot ok`** points at static-init cost: two `ZigbeeColorDimmableLight` cluster
> lists are now built before `app_main`, where there used to be one.

---

## 1. The downlight's on/off — PASS

**Order matters here more than anywhere else in this document.** The last branch fixed a bug where
the downlight's on/off and level were dropped until a colour-temperature command arrived. Touching
the CCT slider first flips the colour mode and masks the bug for the rest of the session.

- [x] Power cycle the fixture
- [x] **Without touching colour temperature**, send `light.turn_on` to `light.*_downlight` from HA
- [x] Tap up on the Inovelli

Both worked immediately. The mode-agnostic callback shims added in the item 9 review are confirmed
on hardware: `ZigbeeColorDimmableLight` leaves `_current_color_mode` at `CURRENT_X_Y`, and
registering an RGB-shaped callback alongside the CCT one is what keeps endpoint 1 — the endpoint the
wall switch binds to — responsive before any colour command arrives.

---

## 2. Both entities exist and are shaped right — PASS, with one finding

Verified 2026-08-18 against the HA entity registry and state machine, after installing the updated
converter and restarting Z2M.

- [x] Both entities appear under **one** device
      (`light.overhead_light_test_downlight`, `light.overhead_light_test_ring`, and
      `button.overhead_light_test_identify`, all on `device_id 1aca1363db02d25c5b57b49d3a95e104`)
- [x] The **downlight** shows a colour-temperature control and **no colour wheel** —
      `supported_color_modes: ["color_temp"]`, 2702–6493 K
- [x] The **ring** shows a colour wheel and **no colour-temperature slider** —
      `supported_color_modes: ["xy"]`

**Design risk 1 is settled.** `ZigbeeColorDimmableLight` configured `COLOR_TEMP`-only does present
correctly through Z2M; keeping the `HA_COLOR_DIMMABLE_LIGHT` device ID did not leak an X/Y control
onto the downlight. The old combined `light.0x744dbdfffe6b575f` was replaced outright rather than
left behind as an unavailable entity.

- [ ] Check the reported `colorMode` attribute on endpoint 1. The library's default cluster config
      leaves it at `0x01` (CurrentX/Y) on an endpoint that advertises no X/Y capability — Z2M may
      show a colour picker anyway, or log a capability warning. Record what it does.
      **Still open:** read it from the Z2M frontend's Dev console tab (endpoint 1, cluster
      `lightingColorCtrl`, attribute `colorMode`). The HA side already looks right, so this is now
      a curiosity rather than a risk.

- [x] **Does the downlight card also show an effect dropdown?** **Yes.** Both entities carry the
      identical seven-entry `effect_list`:
      `[none, warm_gradient, color_gradient, breathing, color_cycle, chase, nightlight]`.
      Z2M's Home Assistant discovery union is **not** endpoint-aware. This is a known cost rather
      than a surprise — `z2m/lumary-brain-revA.js:46` documents the union as the reason the expose
      is named `effect` at all, since that name is what puts the dropdown inside the light card
      instead of creating a separate `select` entity. What selecting an effect from the
      **downlight** card actually does is still unknown; §7 settles it.

Both entities read `state: unknown` immediately after the restart — no state message received yet.
Expect that to clear on the first command or power cycle. If it persists, it belongs in §10.

The entity IDs changed with the split. A config-body search across automations, scripts, scenes
and helpers found no references to the old `light.0x744dbdfffe6b575f`, so nothing needs repointing
for this fixture — but the other Lumary fixtures will when they are flashed.

---

## 3. The low end, on the white string — PASS

This is the 0.24 uS question, and it is the one every other result rested on.

- [x] Set the downlight to brightness **1**, then 2, 3, 4, 5

Brightness 1 produces visible dim light, and each step is brighter than the last.

**Measured N: none — there is no dead zone.** The L-SD8E1's constant-current loop does respond to a
single-count duty at 12-bit resolution (1/4095 at 1 kHz, a 0.24 uS pulse). The 8-bit to 12-bit move
is therefore sound at the bottom of its range, not merely at the top.

Consequences:

- No code change. The provisional `max(1, ...)` floor in `white_mix_gamma()`
  (`src/brightness.h`) stands as written, and no measured-minimum lift is needed.
- The CIE L* curve's linear segment below L* = 8 is doing exactly what it was chosen for: it is
  what lets brightness 1 resolve to a non-zero duty at all, and the driver honours it.
- The `+127` rounding added to `white_mix_gamma()` is exercised in this range, so a clean sweep here
  is also evidence against the truncation bug it was added to fix. Section 5 confirms it directly.

---

## 4. The brightness ramp — PASS

- [x] Step the downlight through 1, 5, 10, 25, 50, 100, 150, 200, 255

Even ramp, no jump out of the low end, no region where steps look identical.

**Brightness 255 tops out at 254 — this is correct, not a defect.** ZCL `genLevelCtrl` defines
`CurrentLevel` over `0x00`-`0xFE` with `0xFF` reserved, so Z2M's HA discovery carries
`brightness_scale: 254` and HA's 0-255 slider is scaled onto 0-254 on the wire. The firmware cannot
receive 255. Every Zigbee light on the network behaves the same way.

Two consequences, neither worth acting on:

- Index 255 of `kGamma8`/`kGamma12` is unreachable, so peak output is `gamma8(254) = 252` and
  `gamma12(254) = 4054` rather than 255 / 4095 -- about **1% below theoretical maximum**, at the
  flattest part of the curve. Rescaling so level 254 reached full duty would make this fixture
  inconsistent with every other light on the network to correct something invisible.
- `scale_level()` (`src/light_state.h:64`) exists to handle level 255 without `scale8`'s
  255 -> 254 off-by-one. That path is unreachable over Zigbee, since its only caller feeds it a
  Zigbee-sourced level. Correct and harmless, just never exercised.

- [x] Sweep the **ring** through the same values

Also even. The ring dims correctly across its full range under the CIE curve, judged against the
downlight rather than against memory -- `gamma8(64) == 11` puts mid-slider roughly 6x below the old
linear behaviour, and that reads as intended rather than as a fault.

Item 6's core claim is now confirmed on hardware for both light sources: one perceptual curve, two
very different drive paths (12-bit LEDC into a constant-current driver, and 8-bit NZR into the
pixel ring), and the ramps match each other.

---

## 5. Colour temperature holds while dimming — PASS

- [x] Set 2700 K (370 mired), sweep brightness 255 -> **10**
- [x] Repeat at 4000 K (250 mired) and at 6500 K (154 mired)

All three dim without drifting warmer or cooler.

The three points are deliberately different tests, and all three passing is what makes this
meaningful:

- **370 and 154 mired** are `CCT_MIRED_WARM` / `CCT_MIRED_COOL` (`src/light_state.h:17-18`), the
  rated temperatures of the two strings. They drive `cct` to 0 and 255, so one string carries the
  whole output and `white_mix_gamma()` reduces to a single `gamma12()` lookup.
- **250 mired** gives `cct` 141 -- a genuine split, where both coefficients are non-zero and the
  rounding matters.

That middle case sweeping to 10 without a colour shift is the hardware confirmation of the `+127`
rounding added to `white_mix_gamma()`. The bug it replaced collapsed a 50/50 request to fully warm
at level 1, and the original plan's stop-at-20 would have passed straight over it. Rounding also
makes `ww + cw == total` exactly, so no output is lost to truncation at any level.

---

## 6. Both sources at once — PASS

- [x] Downlight at 2700 K, ring at a saturated colour, **both on**
- [x] A ring effect running over a lit downlight

Both visible, both independent. **This is the result item 9 existed to produce.** Under the old
combined model `WHITE_SAT_THRESHOLD` in `src/light_state.h` made these mutually exclusive: a
saturated colour meant the white string was off, which put the fixture's "gradient auxiliary light"
selling point out of reach entirely. Two endpoints, two `FixtureState` sub-structs, two HA entities,
and the exclusion is gone.

- [x] Ring balance against a lit downlight: no wash-out reported. Gamma going in first is what this
      was resting on -- the ring's lower half now sits roughly 6x below its old linear behaviour, so
      a coloured ring against a bright white downlight was the plausible failure and did not happen.

---

## 7. The effects — PASS, with one finding and one wart

- [x] All six run and dim: `warm_gradient`, `color_gradient`, `breathing`, `color_cycle`,
      `chase`, `nightlight`
- [x] The effect dropdown is on the **ring** entity and lists six plus `none`

### FINDING: effects collapse to black below roughly brightness 20

Reported at the bench: `warm_gradient` "looks like it turns off" at brightness 16. Reproduced in
arithmetic -- this is a **resolution limit, not a logic bug**, and it is confined to the ring.

At brightness 16 the CIE curve asks for 0.7% output. That is 28 counts of 4095 on the downlight,
which is comfortable, and under 2 counts of 255 on the ring, which is not. The effect then scales
each pixel *again* before the brightness multiplier lands:

```
warm_gradient at brightness 16 (gamma8(16) = 2):
  peak  {255,169, 87} -> {2,1,0}
  3/4   {191,126, 65} -> {1,0,0}
  mid   {127, 84, 43} -> {0,0,0}
  1/4   { 63, 42, 21} -> {0,0,0}
```

Most of the ring is driven to true black and the peak is a single dim red count. Available ring
output levels by slider position: 10 -> 1, 16 -> 2, 24 -> 3, 32 -> 4, 48 -> 7, 64 -> 11.

This is a real change from pre-gamma behaviour, where linear scaling gave the peak pixel 15 counts
at slider 16 rather than 2. The curve is correct; the ring's 8-bit output cannot express it. Section
4 passed because a *solid* colour still resolves to a non-zero count -- it is specifically effects,
which pre-scale their pixels, that fall off the bottom.

Two candidate responses, deliberately not actioned mid-bench:

- **Cheap partial:** `scale_by_255()` in `src/brightness.h` truncates. Adding `+127` rounding --
  the same fix `white_mix_gamma()` already carries for the white split, for the same reason --
  recovers one output step, taking the mid pixel from 0 to 1 and moving the collapse threshold down
  a couple of slider positions. Does not solve it.
- **Real fix:** temporal dithering, alternating adjacent output values across frames so the
  time-average falls between them. This is how 8-bit pixel libraries reach effective 12-bit
  behaviour. Needs a stable frame rate and its own design cycle.

### The rest of the section

- [x] Setting a ring colour drops `effect` to `none`
- [x] **Changing the downlight's colour temperature while a ring effect runs leaves the effect
      alone.** This was the last branch's regression check: `tzColorClearsEffect` had been keyed on
      `color_temp` as well as `color`, so a downlight CCT change would have cleared the ring's
      effect. Narrowing it to `key: ['color']` is confirmed correct on hardware.
- [x] `warm_gradient` at full brightness looks good -- its rendering changed in the gamma work, not
      only its dimming, and the change is an improvement.
- [x] `fx_breathing` behaves correctly through its trough at usable brightness. (At low brightness
      it is subject to the collapse finding above, like every other effect.)

### WART: the downlight's effect dropdown turns the light on and does nothing else -- FIXED 2026-08-19

Observed: with the downlight off, selecting an effect from its card **turns the downlight on**. With
it already on, cycling through effects changes nothing at all. The ring is unaffected throughout.

Both halves follow from code:

- The light coming on is Home Assistant's `light.turn_on` semantics. Selecting an effect calls
  `light.turn_on` with an `effect` attribute, and the MQTT light platform always includes
  `state: ON` in that payload. Endpoint 1 receives a legitimate On command and obeys it.
- The effect going nowhere is `tzEffect`, whose `key` is `['effect']` -- so it *does* match on the
  downlight entity, resolves the endpoint to 1, and issues `setEffect` against cluster `0xFC00`,
  which exists only on endpoint 2. The command cannot succeed.

So the §2 union finding resolves as: harmless but untidy. Nothing is corrupted and the ring is never
disturbed; the downlight card simply carries a control that does nothing except switch the light on.

Turned out to be suppressible after all, just not from the exposes/extend shape that seemed like the
only lever at the time: `meta.overrideHaDiscoveryPayload` runs once per light's discovery payload
*after* Z2M has already unioned `effect`/`effect_list` onto it, keyed on `payload.object_id` (a
device-friendly-name-derived string, e.g. `overhead_light_test_downlight` -- not the fixed
`light_downlight` config id, which was this fix's first, wrong guess and shipped as a silent no-op
until checked live). `z2m/lumary-brain-revA.js:46` still records why the expose has to be named
`effect` in the first place. See `2026-08-17-home-assistant-polish.md` item 9 for the full writeup,
including the retained-MQTT-discovery gotcha that made the first redeploy look like it hadn't taken
even once the match itself was fixed.

Worth capturing the Z2M log line for the failed `setEffect` next time the fixture is on the bench;
it would confirm whether the command errors or is silently absorbed.

---

## 8. Persistence and rejoin

### CRITICAL, found and fixed mid-section: the fixture would not boot without USB

Discovered 2026-08-18 while setting up the power-cycle test, and fixed in `ab5dfe9`.

Every bench session to date had the module USB-tethered to a PC. Pulling mains therefore never reset
the MCU -- USB kept it alive -- so **this board had never once cold-booted standalone.** The first
time it did, the downlight came on at full and the device was unreachable over Zigbee.

Cause: `setup()` opened with an unbounded wait.

```cpp
Serial.begin(115200);
while (!Serial) delay(10);      // never returns with no USB host
```

`platformio.ini` builds with `-DARDUINO_USB_CDC_ON_BOOT=1`, so `Serial` is the USB CDC and its
`operator bool()` stays false until a host enumerates it. With no PC attached, `setup()` never
returned and everything below that line was dead code:

- `led_driver_init()` never configured the white PWM GPIO. The pin stayed in its reset default, the
  L-SD8E1 saw no gating signal, and the driver ran at 100% -- **downlight full on**.
- `zigbee_light_init()` never started the radio -- **device unreachable**.
- `loop()` never ran -- ring dark.

Fixed by bounding the wait to one second, which still catches `boot ok` on the monitor at the bench
without stranding a mains-only boot.

**Verified on hardware the same session:** with USB fully unplugged from the PC, the fixture cold-
boots from mains alone, the downlight stays off as it should, and the device joins the network. This
is the first time the board has ever completed a standalone power-up.

**This blocked section 11 outright** -- there is no USB host in a ceiling, so the fixture could never
have worked installed. It is the single most valuable thing this bench session found, and it was
only reachable by testing the real power-up path rather than a tethered one.

Lesson worth carrying: a bench rig that differs from the deployed configuration in *any* powered
respect will hide exactly the faults that matter. Sections 1-7 all passed while this was live.

### The section proper — PASS

- [x] Select an effect, power cycle, and watch what HA shows

Tested with `chase` (index 4) rather than `warm_gradient` (index 0), deliberately: index 0 is both
the reseed default and the effect attribute's static-init value, so it cannot distinguish a restore
from a reset. Cold boot performed with USB fully unplugged, so this also exercised the deployed
power-up path.

Result, all three in agreement:

- the ring physically renders `chase` once turned on
- a **forced** read of the attribute -- the refresh control on the Effect expose, which calls
  `convertGet` -> `entity.read('lumary', ['effect'])` on endpoint 2, bypassing Z2M's cache --
  returns `chase`
- HA reports `effect: chase`, `color_mode: xy`, `brightness: 255`

The forced read matters: Z2M persists its own state store across restarts, so the Exposes tab
showing the right value proves nothing on its own. Only the explicit read confirms the device itself
holds it.

**How the attribute gets synced**, since it is not obvious and is easy to mis-read: the ZCL attribute
is built during static init, before `setup()` ever opens NVS, so at boot it does not reflect the
restored scene. `zigbee_light_init()` does not fix that, and neither does `zigbee_light_report()`.
The correction is a one-shot in `zigbee_light_loop()`, fired the first time `Zigbee.connected()`
goes true, which publishes both endpoints' real state including the effect. The comment there names
the exact failure it prevents. Anything that reorders or removes that one-shot silently reintroduces
"a read reports effect 0 whatever is really running".

Also worth noting for future readers: **Home Assistant nulls every light attribute while the light
is off** -- `effect`, `brightness` and `color_mode` all go null together. An off light showing no
effect is not evidence of anything. The ring must be on for this check to mean anything.

- [x] Confirm the stored scenes reseeded rather than misread

Passed behaviourally in section 7: all six effects rendered correctly with sensible parameters, which
they would not have if version 1's eight-effect records had survived and been reinterpreted under the
new six-effect numbering. `scene_store_init()` reseeds all `EFFECT_COUNT` slots from `kDefaultParams`
whenever the stored `fmt_ver` does not match `NVS_FMT_VER_CURRENT`.

NVS scene storage had never run on hardware before today -- the earlier bench session used
`BENCH_DEMO_MODE`, which bypasses `scene_store` entirely. It works.

---

## 9. The switch, both bindings — PASS

The binding as found at the start of the session was wrong twice over: sourced from the Inovelli's
endpoint **3** (the config button) rather than endpoint **2** (the paddle), and carrying `genOnOff`
only, with no `genLevelCtrl`. Rebuilt as:

```
switch ep2 -> fixture ep1   (downlight)     genOnOff + genLevelCtrl
switch ep2 -> fixture ep2   (accent ring)   genOnOff + genLevelCtrl
```

Fixture endpoint 2 appeared in the destination dropdown, which is itself confirmation that the
re-interview took and Z2M is working from the new two-endpoint descriptor.

- [x] Tap down: both sources go off
- [x] Tap up: both return, each at its own level and colour
- [x] **Drift them apart deliberately, then tap up** -- the two sources re-converge

That last one is the load-bearing result. **It proves the switch sends discrete `On`/`Off` rather
than `Toggle`**, which the entire binding design rests on: under `Toggle`, two endpoints deliberately
driven out of sync would invert independently and stay wrong forever, with no way for the switch to
recover them. Discrete commands make the drift self-correcting, which is exactly what was observed.
This had been confirmed once before, but never under the two-endpoint arrangement, where the failure
mode would have been considerably more visible.

- [x] Hold: both dim. This is the leg that exercises the newly added `genLevelCtrl` binding --
      on/off passes identically whether or not `genLevelCtrl` is bound, which is precisely the state
      the binding was in before this session, so it is the only check that proves the added cluster
      binding is live.

---

## 10. The upgrade path, on a fixture already in service

- [ ] Flash the fixture at `0x744dbdfffe6b575f` and, **before re-interviewing it**, record what Z2M
      and HA show

The README currently hedges because nobody knows: does the ring entity fail to appear at all, or
does it appear and not respond? Possibly Z2M's `configure` throws on the missing endpoint.

Observed: ______________________________________________

- [ ] Then re-interview (Z2M frontend → device → Re-interview) and confirm both entities work
- [ ] Correct `README.md`'s "Upgrading an already-paired fixture" wording to match what you saw

---
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

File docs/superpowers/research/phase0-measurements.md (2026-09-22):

# Phase 0 Measurements

Fill every `___`. When there are no blanks left, Phase 1 (Claude design work) can start.
Spec: `docs/superpowers/specs/2026-08-01-brain-replacement-board-design.md`
Plan: `docs/superpowers/plans/2026-08-01-brain-replacement-board.md`

---

## Driver rails (DONE)
- Driver: **L-SD8E1**, 120 VAC / 60 Hz / 0.2 A, OUTPUT **35.8 V 380 mA max (constant current)**
- White wire = **GND**
- Blue wire  = **36.63 V** → `V+`  (CC white-string rail)
- Red wire   = **4.7 V**   → `5V+` (logic / addressable-ring rail)

---

## P0.1 — Connectors  (Task 0.1)  — DONE (CN1 corrected; physical 1..7 order resolved by rev B construction)
Measure pitch with calipers → JST family: 1.0 mm=SH, 1.25 mm=GH, 1.5 mm=ZH, 2.0 mm=PH.

- Power-in:  **soldered on stock board (no existing connector).** New board = **3-pin JST-PH 2.0 mm (polarized) + parallel solder pads** (DECIDED — both options on the footprint; user has PH stock). Wires: GND / 36 V / 4.7 V. Pin order on our connector is our choice → keep GND on an end pin, key so 36 V can't swap with 4.7 V.
- CN1:       pins = **7 (6 populated, 1 empty)**   pitch = **1.5 mm**   JST family = **ZH, 7-position** —
  **corrected 2026-09-04**: physically verified against the stock connector with purchased ZH1.5 7P
  parts (mates cleanly). Supersedes the earlier 1.25 mm/PicoBlade reading, which rev A's J2 was
  fabbed against and which does **not** mate (see `docs/research/teardown-reference.md`). Rev A's
  board and BOM were fabbed against `Molex_PicoBlade_53047-0710_1x07_P1.25mm_Vertical` for J2; **rev
  B (2026-09-21/22) carries the footprint swap to
  `Connector_JST:JST_ZH_S7B-ZR-SM4A-TF_1x07-1MP_P1.50mm_Horizontal`** — `hardware/bom.csv`,
  `hardware/kicad/bom-jlc.csv` and `hardware/kicad/footprints-and-pins.md` now specify it, so CN1
  mates directly with no pigtail. physical pin order (1..7) = **resolved by the rev B footprint** —
  as built (board-local, post-shrink frame): all seven pads at x 54.500, pitch 1.5 mm, span pad 1 →
  pad 7 = 9.0 mm; pad 1 (`+36V`) bottom-most at y 19.650, pad 4 (`+4V7`) the centre pad at y 15.150,
  pad 7 (NC) top-most at y 10.650. (Rev A's numbers — x 59.50, pitch 1.25 mm, pad 1 at y 19.00 — were
  the pre-shrink frame used only to establish which end is pin 1, confirmed against a photo of the
  working rev A board where the black `V+` wire sits at the bottom end.) Full detail in
  `hardware/schematic-nets.md` §2.5.
  **History:** the interim plan (no KiCad/BOM respin; bring up the existing 5 rev A boards with a
  short ZH1.5-7P-to-PicoBlade-7P pigtail adapter) was superseded once the rev B fab run above
  happened; the pigtail remains valid for already-built rev A boards.

---

## P0.3 — CN1 pinout  (Task 0.2)  — DONE (physical 1..7 order resolved by rev B construction)
7-position PicoBlade, 6 wires populated, split 3 (inner white) + 3 (outer addressable ring):

| Label | Wire | Role | Board net |
|---|---|---|---|
| `V+`  | Black  | Inner white-string anode (36 V, → strip `LED+`) | `+36V` |
| `CW-` | White  | Cool-white return (→ strip `65K-`) | low-side CC sink CW |
| `WW-` | Yellow | Warm-white return (→ strip `27K-`) | low-side CC sink WW |
| `5V+` | Red | Outer ring power (4.7 V) | `+4V7` |
| `GND` | Green  | Outer ring ground | `GND` |
| `DIM` | Blue | **Outer ring DATA** (single-wire addressable; "DIM" is vendor's generic name) | level-shifted data out |
| (7th) | none | unpopulated | — |

- Physical position resolved by rev B construction (no scan needed): as built, pad 1 (`V+`/`+36V`) is
  the bottom-most pad (board-local y 19.650, largest y), pad 4 (`5V+`/`+4V7`) is the centre pad
  (y 15.150, orientation-independent either way), and the harness's empty position lands on pad 7
  (NC, y 10.650, nearest the top). Confirmed against a photo of the working rev A board — the black
  `V+` wire sits at the bottom end, which is pad 1. Full table in `hardware/schematic-nets.md` §2.5.
- Confirmation logic: a color *gradient* over a single control wire ⇒ addressable, so `DIM` = data, not analog dim.

---

## P0.4 — Outer (addressable) ring  (Task 0.3)  — DONE
- strip marking = **UT-08-ZC03-01-5V3535RGBIC-3W-1C62B-628x8mm V1.2 20241120**
- type = **5 V, 3535-package, addressable RGBIC** (per-pixel IC); pads **VCC / DIN / GND** (3-wire)
- **pixel count = 62** (firmware currently 36 → MUST change to 62)
- **color format = RGB, 24-bit** (NOT RGBW; firmware uses CRGBW/32-bit → MUST change to RGB)
- data line: `CN1.DIM` (blue) → strip **DIN**, via 3.3→4.7 V level buffer
- construction: 200 Ω (`201`) inter-pixel data series-R + decoupling cap every 3 px (standard)
- protocol: 800 kHz NZR (WS2812/SK6812-class); confirm exact color order (likely GRB) on bring-up
- ⚠️ FIRMWARE (Phase 5): set count=62, switch outer ring to 24-bit RGB, verify color order
- ⚠️ CURRENT (risk R3): 62 RGB px worst-case ≫ 4.7 V rail budget → brightness cap mandatory

---

## P0.5 — White string  (Task 0.4)  — DONE
Strip `8C18W-12C4B-2835X2-588×7.5mm V1.0`; 96 LEDs total, cool/warm interleaved.
Wires: black=`LED+` (anode), white=`65K-` (cool return), yellow=`27K-` (warm return).

- **Topology: 12 series × 4 parallel banks PER COLOR** (`12C4B`); per-bank ballast resistors
  balance the 4 parallels. 48 cool + 48 warm = 96 ✓
- Per-color full current = 380 mA (driver total) → ~95 mA/bank across 4 banks; **sink carries 380 mA**
- Vf_string ≈ 12 × 3.05 V ≈ **36 V** ≈ rail (36.63 V) → **headroom ≈ 0.6 V**
- **Max sink dissipation ≈ 0.6 V × 0.38 A ≈ 0.23 W per channel** (only one color full at a time)
- Driver confirmed **constant-current** (rails to 36.63 V open = compliance; regulates 380 mA loaded).
  Board **steers + PWMs**, does not source current.
- **DECISION (Task 1.2 gate): 0.23 W ≤ 0.5 W → clone HT7308 linear CC low-side sinks.**
  Set CC limit **~420 mA** (above the driver's 380 mA) so the board never limits below the driver
  (full brightness preserved; CC engages only as protection if headroom ever appears).
- Fidelity (DONE): stock uses **two HT7308** (`H7308 J2448D1`, U1=cool, U1A=warm). Sense resistors
  `R5,R6` (ch1) and `R5A,R6A` (ch2), **all `R680`=0.68 Ω, two in parallel per channel ≈ 0.34 Ω**.
  With HT7308 V_ref ≈ 0.13 V → **I ≈ 382 mA/channel** (matches the 380 mA driver). Confirm V_ref vs
  datasheet at BOM step. Our board: use ~0.33 Ω (or 2×0.68 ∥) per channel → ~380–390 mA.

---

## P0.6 — Mechanical  (Task 0.5)  — FINAL (no scan; using envelope + photo assumptions)
No scan will be provided. Design to the measured envelope; outline = rounded rectangle.

- board outline L×W = **63.3 mm × 31.3 mm** ✅ → KiCad outline = rounded rectangle at these dims,
  corner radius ~5 mm (stadium-ish ends, per photos). Design ~0.3–0.5 mm inside nominal for fit slack.
- tallest component height (max envelope) = **6.7 mm** ✅
- fit check = **PASS, huge margin** (our tallest part USB-C ~3.2 mm; ceramic caps only). ✅
- mounting holes = **ASSUMED NONE** — stock board appears retained by the housing + harnesses
  (no screw holes visible in photos). ⚠️ Correct if the fixture actually screws the board down.
- connector placement (from photos) = **power-in (J1) at one short end, CN1 (J2) at the other short
  end**, matching stock harness exits. J2 pin order = stock label order V+/CW-/WW-/5V+/GND/DIM/(NC);
  orientation resolved and confirmed at rev B layout: pad 1 (`V+`) is the bottom-most pad
  (board-local y 19.650), pad 4 (`5V+`) the centre pad (y 15.150), pad 7 (NC) the top-most
  (y 10.650) — matching the photo of the working rev A board (black `V+` wire at the bottom end).
- antenna keepout = MINI-1 PCB antenna at a short **end**, toward the fixture opening; stock 2.4 GHz
  module ran from this area, so RF is low-risk. Keep copper clear under the antenna on all layers.

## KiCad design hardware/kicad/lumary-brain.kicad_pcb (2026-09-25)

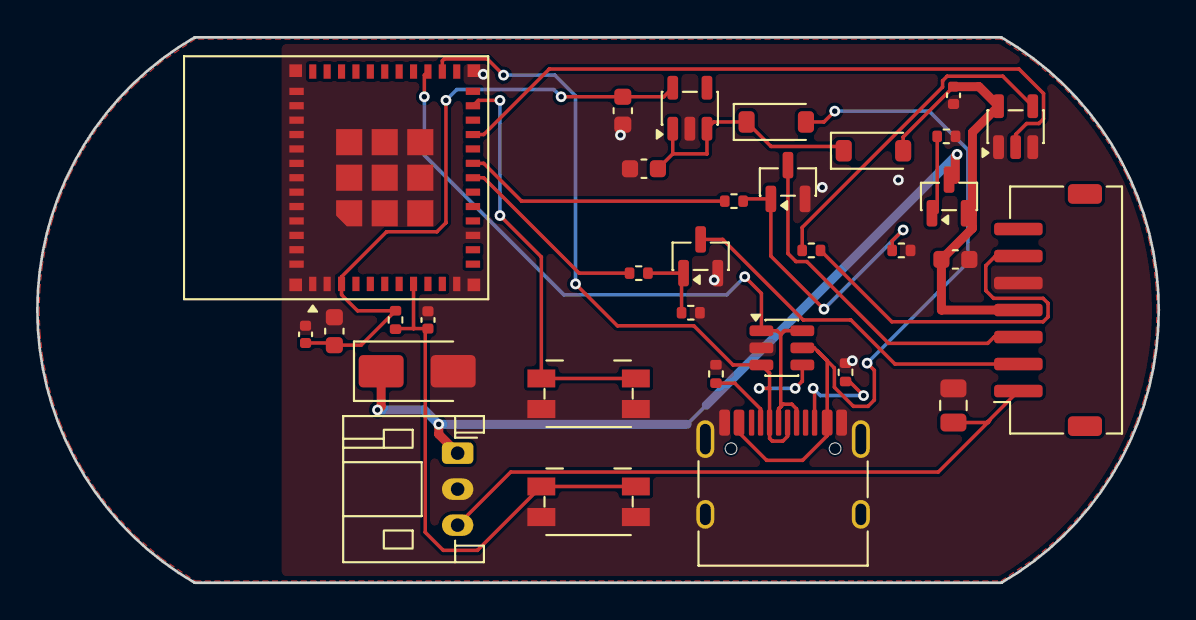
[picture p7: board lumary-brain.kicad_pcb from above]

Board: 2 copper layers, 62.3 x 30.3 mm, 32 parts (0 on the bottom side), 23 nets.

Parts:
C1: 10uF/50V; C_0805_2012Metric
C2, C4, C5: 10uF; C_0603_1608Metric
C3: 1uF; C_0603_1608Metric
C6, C7: 100nF; C_0402_1005Metric
C8: 1uF; C_0402_1005Metric
D1, D2: B5819W; D_SOD-123
D3: SMAJ5.0A; D_SMA
J1: PWR_IN; JST_PH_S3B-PH-K_1x03_P2.00mm_Horizontal
J2: CN1; JST_ZH_S7B-ZR-SM4A-TF_1x07-1MP_P1.50mm_Horizontal
J3: USB-C; USB_C_Receptacle_HRO_TYPE-C-31-M-12
Q1, Q2: NMOS_60V; SOT-23
Q3: AO3401A; SOT-23
R1, R2: 100R; R_0402_1005Metric
R3, R4, R9: 100k; R_0402_1005Metric
R5: 200R; R_0402_1005Metric
R6: 10k; R_0402_1005Metric
R7, R8: 5.1k; R_0402_1005Metric
SW1: BOOT; Panasonic_EVQPUJ_EVQPUA
SW2: EN; Panasonic_EVQPUJ_EVQPUA
U1: ESP32-H2-MINI-1-N4; ESP32-C6-MINI-1
U2: ME6211C33M5G; SOT-23-5
U3: 74AHCT1G125; SOT-23-5
U4: USBLC6-2SC6; SOT-23-6

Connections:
+3V3: C2.1, C5.1, C6.1, R6.2, U1.3, U2.5
+4V7: C4.1, C7.1, D1.2, J2.4, Q3.2, U3.5
+4V7_IN: D3.1, J1.1, Q3.3
+36V: C1.1, J1.3, J2.1
CC1: J3.A5, R7.1
CC2: J3.B5, R8.1
CW_GATE: Q1.1, R1.2, R3.1
CW_PWM: R1.1, U1.18
CW_RET: J2.2, Q1.3
EN: C8.1, R6.1, SW2.1, U1.8
GND: C1.2, C2.2, C3.2, C4.2, C5.2, C6.2, C7.2, C8.2, D3.2, J1.2, J2.5, J3.A1, J3.A12, J3.B1, J3.B12, J3.SH, Q1.2, Q2.2, R3.2, R4.2, R7.2, R8.2, R9.2, SW1.2, SW2.2, U1.1, U1.2, U1.11, U1.14, U1.36, U1.37, U1.38, U1.39, U1.40, U1.41, U1.42, U1.43, U1.44, U1.45, U1.46, U1.47, U1.48, U1.49, U1.50, U1.51, U1.52, U1.53, U2.2, U3.1, U3.3, U4.2
IO9: SW1.1, U1.23
LDO_IN: C3.1, D1.1, D2.1, U2.1, U2.3
Q3_GATE: Q3.1, R9.1
RING_BUF_OUT: R5.1, U3.4
RING_DATA: J2.6, R5.2
RING_DATA_3V3: U1.21, U3.2
USB_DM: J3.A7, J3.B7, U1.26, U4.3, U4.4
USB_DP: J3.A6, J3.B6, U1.27, U4.1, U4.6
VBUS: D2.2, J3.A4, J3.A9, J3.B4, J3.B9, U4.5
WW_GATE: Q2.1, R2.2, R4.1
WW_PWM: R2.1, U1.19
WW_RET: J2.3, Q2.3

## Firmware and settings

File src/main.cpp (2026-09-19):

#include <Arduino.h>
#include "esp_task_wdt.h"
#include "config.h"
#include "led_driver.h"
#include "effects.h"
#include "effect_params.h"
#include "light_state.h"
#include "brightness.h"
#include "scene_store.h"
#include "zigbee_light.h"
#include "identify.h"

static CRGB leds[RING_NUM_LEDS];

// There was a MAX_BRIGHTNESS ceiling of 24/255 here, clamped ahead of every
// effect to protect rev A's +4V7 traces -- routed at 0.2 mm rather than 0.5 mm
// because KiCad dropped the Power net class before routing (a1270ba), giving
// ~0.74 A at a 10 C rise.
//
// Removed 2026-08-15 after bench measurement retired the premise, and because
// the clamp sat ahead of every effect it also throttled the inner white string
// to ~9% duty -- the fixture's main light source, whose current never touches
// that trace at all. See docs/superpowers/specs/
// 2026-08-15-remove-rev-a-brightness-ceiling-design.md and hardware/calcs.md.
//
//   ring at full brightness   0.48 A measured (1.2 A had been assumed), cold or
//                             warm, with no measurable trace heating in 3 runs
//   white at 100% duty        Q2 at 37 C after 15 min (Task 6.3)
//
// Still unverified in service, and what Task 6.4 must check: the L-SD8E1's
// spare 4.7 V capacity. If that rail cannot carry ring + module, the symptom is
// the ring dimming or glitching rather than an MCU brownout -- the LDO has
// ~1.2 V of margin. A ring-only cap belongs here if that turns out to be real;
// note a global clamp would be the wrong fix, since it throttles white too.

// Set to 1 to cycle every effect on a timer with no Zigbee network, for
// bench-testing the LED path over USB before the light is joined.
#define BENCH_DEMO_MODE 0

#define FRAME_INTERVAL_MS 16

void setup() {
    Serial.begin(115200);
    // Sets the white duty to 0 before the up-to-1 s USB wait below, so a
    // restart on mains -- including an OTA recovery restart -- holds the
    // downlight dark instead of letting the L-SD8E1 run it full on until the
    // wait ends; only the ROM/bootloader window (~0.3 s) remains ungated.
    // led_driver_init() only touches SPI2/LEDC GPIO config from config.h, so
    // it needs nothing setup() would otherwise have done first.
    led_driver_init();

    // Bounded, NOT `while (!Serial)`. The build sets ARDUINO_USB_CDC_ON_BOOT=1,
    // so Serial is the USB CDC and stays false until a host enumerates it -- an
    // unbounded wait means setup() never returns on a fixture running from mains
    // with no USB attached. Found on the bench 2026-08-18, on the first cold
    // boot this board ever had without a PC attached.
    for (uint32_t t0 = millis(); !Serial && millis() - t0 < 1000; ) delay(10);
    Serial.println("boot ok");

    // Arm the app watchdog before anything that could hang. This is not
    // theoretical: Zigbee.begin() has hung outright before during bring-up
    // (bisected 2026-08-15, see zigbee_light.cpp) rather than returning an
    // error, and the only recovery for a fixture already in the ceiling is
    // physical USB access -- there is no OTA/BLE fallback (see README). A
    // reboot beats a permanent hang. esp_task_wdt_init() fails with
    // ESP_ERR_INVALID_STATE if the Arduino core already started a default
    // TWDT, in which case reconfigure it to this timeout instead.
    esp_task_wdt_config_t wdt_config = {};
    wdt_config.timeout_ms    = WDT_TIMEOUT_MS;
    wdt_config.idle_core_mask = 0;
    wdt_config.trigger_panic = true;
    if (esp_task_wdt_init(&wdt_config) == ESP_ERR_INVALID_STATE) {
        esp_task_wdt_reconfigure(&wdt_config);
    }
    esp_task_wdt_add(nullptr);   // watch this task -- setup() and loop() both run on it

    scene_store_init();
    Serial.println("LED driver init ok");

#if !BENCH_DEMO_MODE
    zigbee_light_init();
#endif
}

void loop() {
    static uint32_t frame_start  = 0;
    static uint32_t effect_start = 0;
    static uint8_t  shown_scene  = 0xFF;   // forces a scene load on first frame
    static EffectParams scene;

    esp_task_wdt_reset();

#if !BENCH_DEMO_MODE
    zigbee_light_loop();
#endif

    const uint32_t now = millis();
    if (now - frame_start < FRAME_INTERVAL_MS) return;
    frame_start = now;

#if BENCH_DEMO_MODE
    static uint8_t demo_idx = 0;
    if (now - effect_start > 5000) {
        demo_idx     = (demo_idx + 1) % EFFECT_COUNT;
        effect_start = now;
        Serial.printf("Effect: %s\n", kEffects[demo_idx].name);
    }
    EffectParams p = kDefaultParams[demo_idx];
    const bool on  = true;
#else
    const FixtureState* s = zigbee_light_state();

    // Scene params live in NVS; only re-read them when the scene actually
    // changes, and restart the animation clock so effects begin from frame 0.
    if (s->ring.scene != shown_scene) {
        shown_scene  = s->ring.scene;
        effect_start = now;
        scene_store_load(shown_scene, &scene);
    }

    EffectParams p = ring_state_resolve(&s->ring, &scene);
    const bool on  = s->ring.on;
#endif

    if (p.type >= EFFECT_COUNT) p.type = EFFECT_WARM_GRADIENT;   // NVS corruption guard

    // Identify overrides whatever is running, without disturbing it: FixtureState
    // is untouched, so when the deadline passes the next frame resumes normally.
    // Bench demo mode compiles out zigbee_light_* entirely, so the accessor is
    // not available to link against there.
#if BENCH_DEMO_MODE
    const bool identifying = false;
#else
    const bool identifying = identify_active(now, zigbee_light_identify_until());
#endif

    if (identifying) {
        // Identify is a whole-fixture "which can is this": the ring blinks blue
        // and the downlight goes dark for the duration, because a lit downlight
        // washes the blue out. Neither state is touched, so the next frame
        // after the deadline resumes both by itself.
        fx_identify(now, leds);
        led_driver_set_cw(0);
        led_driver_set_ww(0);
    } else {
#if BENCH_DEMO_MODE
        kEffects[p.type].fn(now - effect_start, p, leds, on);
#else
        if (s->ring.mode == MODE_COLOR) fx_ring_solid(p, leds, on);
        else                            kEffects[p.type].fn(now - effect_start, p, leds, on);

        const WhiteMix w = white_mix_gamma(downlight_level(&s->down), s->down.cct);
        led_driver_set_ww(w.ww);
        led_driver_set_cw(w.cw);
#endif
    }
    led_driver_show(leds, RING_NUM_LEDS);
}

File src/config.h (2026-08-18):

// lumary-zigbee/src/config.h
#pragma once
#include "driver/ledc.h"
#include "version.h"

// Target board: lumary-brain rev A (drop-in replacement for the stock
// KOK-AH-A172C controller). See docs/superpowers/specs/2026-08-01-*.

// ── Pins ──────────────────────────────────────────────
// GPIO2/3/8/9/25 are ESP32-H2 strapping pins. The white PWM channels moved to
// GPIO4/5 on rev A so the MOSFET gate pulldowns can't hold a strapping pin low
// at reset (the Super Mini prototype drove them from GPIO2/3).
#define PIN_RING_DATA         11   // SPI2 MOSI → level buffer → CN1.DIM (ring DIN)
#define PIN_RING_CLK_DUMMY    12   // SPI2 CLK  → leave unconnected
#define PIN_CW_PWM             4   // Cold white LEDC → Q1 gate → CN1.CW-
#define PIN_WW_PWM             5   // Warm white LEDC → Q2 gate → CN1.WW-
#define PIN_BLE_OTA_BUTTON     9   // BOOT button — hold 5s to enter BLE OTA

// ── Outer ring (addressable) ──────────────────────────
// UT-08-ZC03-01-5V3535RGBIC: 62 pixels, 3 colour bytes each (no white die).
#define RING_NUM_LEDS         62
#define RING_SPI_CLK_HZ       3200000  // 3.2 MHz → 4 SPI bits = one 800kHz NZR bit
// Data: 62 LEDs × 24 bits × 4 SPI bits/bit = 5952 bits = 744 bytes.
// One SPI byte is 2.5 µs at this clock.
// Reset: +120 trailing zero bytes = 300 µs latch, generous enough for
// WS2812B-V5 parts (which want >280 µs) as well as older ones (>80 µs).
#define RING_SPI_BUF_SIZE     896
// Leading low period, transmitted before the pixel data. MOSI is not guaranteed
// to idle low between transactions, and a line already high when the frame
// starts robs the first NZR bit of its rising edge. Kept as cheap insurance: it
// did not fix the corruption seen during bring-up on 2026-08-15 (a logic
// capture showed the real cause was T0H pulse width, see pixel_encode.h), but a
// guaranteed-low line before the first bit is correct practice for SPI-driven
// NZR. 32 bytes = 80 µs.
#define RING_SPI_LEAD_BYTES   32

// ── PWM (inner white string) ──────────────────────────
// The external L-SD8E1 driver is a 380 mA constant-current source; the board
// only gates it. A CC supply's control loop can't track fast switching, so keep
// the PWM slow enough for it to settle but above the flicker threshold.
// Verify on the bench (Task 6.3) and adjust if low-end dimming shudders.
//
// 12-bit rather than 8-bit so a perceptually corrected low end has somewhere to
// live: at 8 bits the CIE curve puts brightness 1..4 at duty 0, i.e. off. The
// frequency is unchanged, so the driver sees the same switching rate it already
// passed Task 6.3 with -- but minimum on-time drops from 3.9 us to 0.24 us, and
// whether the driver responds at all down there is what the bench sweep checks.
// 1 kHz from the 32 MHz XTAL allows up to ~14 bits, so 12 has margin.
#define PWM_FREQ_HZ           1000
#define PWM_RESOLUTION        LEDC_TIMER_12_BIT
#define PWM_DUTY_MAX          4095
#define PWM_CHANNEL_CW        LEDC_CHANNEL_0
#define PWM_CHANNEL_WW        LEDC_CHANNEL_1

// ── Zigbee ────────────────────────────────────────────
// Effect selection rides a manufacturer-specific cluster, because nothing
// standard can carry it: the Scenes cluster stores colour/level and knows
// nothing about EffectParams, and the Identify trigger-effect command (which
// is what Z2M's built-in "effect" dropdown drives) has no hook in the Arduino
// library. Writing LUMARY_ATTR_EFFECT selects one of the six effects.
// See docs/superpowers/specs/2026-08-15-effect-selection-design.md.
// Selection arrives as a COMMAND rather than an attribute write: ZigbeeColor
// DimmableLight declares zbAttributeSet private, so a subclass can override it
// but cannot delegate on/off, level and colour back to the base -- overriding
// would silently break the light. onCustomClusterCommand is public and is the
// library's intended extension point. The attribute is read-only state, kept in
// step so Z2M/HA can display which effect is running.
#define LUMARY_CLUSTER_ID       0xFC00   // manufacturer-specific range
#define LUMARY_ATTR_EFFECT      0x0000   // u8, read-only: effect currently running
#define LUMARY_CMD_SET_EFFECT   0x00     // payload: one u8, the effect index
// ...or LIGHT_EFFECT_NONE (0xFF, src/light_state.h) to stop the effect and hold
// the current colour. The attribute reports that same value whenever a colour
// command has taken the fixture out of effect mode, so Home Assistant's effect
// dropdown -- which has no null member -- always has something true to show.

// Two endpoints, two Home Assistant light entities. The downlight keeps
// endpoint 1: existing switch bindings target it and should land on the main
// light, and the OTA client and Basic strings already live there.
#define DOWNLIGHT_ENDPOINT    1
#define RING_ENDPOINT         2
#define ZB_MANUFACTURER_CODE  0x1001
#define ZB_IMAGE_TYPE         0x0001
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

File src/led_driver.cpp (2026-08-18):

#include "led_driver.h"
#include "pixel_encode.h"
#include "driver/spi_master.h"
#include "driver/ledc.h"

static spi_device_handle_t s_spi;
static uint8_t s_spi_buf[RING_SPI_BUF_SIZE];

void led_driver_init() {
    spi_bus_config_t bus = {};
    bus.mosi_io_num    = PIN_RING_DATA;
    bus.miso_io_num    = -1;
    bus.sclk_io_num    = PIN_RING_CLK_DUMMY;
    bus.quadwp_io_num  = -1;
    bus.quadhd_io_num  = -1;
    bus.max_transfer_sz = RING_SPI_BUF_SIZE;
    ESP_ERROR_CHECK(spi_bus_initialize(SPI2_HOST, &bus, SPI_DMA_CH_AUTO));

    spi_device_interface_config_t dev = {};
    dev.clock_speed_hz = RING_SPI_CLK_HZ;
    dev.mode           = 0;
    dev.spics_io_num   = -1;
    dev.queue_size     = 1;
    ESP_ERROR_CHECK(spi_bus_add_device(SPI2_HOST, &dev, &s_spi));

    ledc_timer_config_t timer = {};
    timer.speed_mode      = LEDC_LOW_SPEED_MODE;
    timer.timer_num       = LEDC_TIMER_0;
    timer.duty_resolution = PWM_RESOLUTION;
    timer.freq_hz         = PWM_FREQ_HZ;
    timer.clk_cfg         = LEDC_AUTO_CLK;
    ESP_ERROR_CHECK(ledc_timer_config(&timer));

    ledc_channel_config_t cw = {};
    cw.gpio_num   = PIN_CW_PWM;
    cw.speed_mode = LEDC_LOW_SPEED_MODE;
    cw.channel    = PWM_CHANNEL_CW;
    cw.timer_sel  = LEDC_TIMER_0;
    cw.duty       = 0;
    ESP_ERROR_CHECK(ledc_channel_config(&cw));

    ledc_channel_config_t ww = cw;
    ww.gpio_num = PIN_WW_PWM;
    ww.channel  = PWM_CHANNEL_WW;
    ESP_ERROR_CHECK(ledc_channel_config(&ww));
}

void led_driver_show(const CRGB* leds, uint16_t count) {
    memset(s_spi_buf, 0, RING_SPI_LEAD_BYTES);
    pixel_encode(leds, count, s_spi_buf + RING_SPI_LEAD_BYTES,
                 RING_SPI_BUF_SIZE - RING_SPI_LEAD_BYTES);
    spi_transaction_t t = {};
    t.length    = RING_SPI_BUF_SIZE * 8;
    t.tx_buffer = s_spi_buf;
    spi_device_polling_transmit(s_spi, &t);
}

void led_driver_set_cw(uint16_t duty) {
    ledc_set_duty(LEDC_LOW_SPEED_MODE, PWM_CHANNEL_CW, duty > PWM_DUTY_MAX ? PWM_DUTY_MAX : duty);
    ledc_update_duty(LEDC_LOW_SPEED_MODE, PWM_CHANNEL_CW);
}

void led_driver_set_ww(uint16_t duty) {
    ledc_set_duty(LEDC_LOW_SPEED_MODE, PWM_CHANNEL_WW, duty > PWM_DUTY_MAX ? PWM_DUTY_MAX : duty);
    ledc_update_duty(LEDC_LOW_SPEED_MODE, PWM_CHANNEL_WW);
}

void led_driver_off() {
    static const CRGB black[RING_NUM_LEDS] = {};
    led_driver_show(black, RING_NUM_LEDS);
    led_driver_set_cw(0);
    led_driver_set_ww(0);
}

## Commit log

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2026-03-29 docs: add teardown reference with photos and community research
    - 5 reference photos (CBU board, disassembly, PCB comparison, footprint, enclosure)
    - Internal wiring pin assignments confirmed from HA community teardown
    - Links to zimmer62/Lumary-ESPHome and ShaunPCcom/zigbee-LED-ESP32-controller
    - ESP32-H2 Super Mini GPIO assignments
    - Logic level and power budget notes
    - Inovelli binding setup instructions
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2026-08-01 docs: design spec for Lumary brain replacement board
    Drop-in ESP32-H2-MINI-1 PCB replacing the stock Tuya controller
    (KOK-AH-A172C) in the Lumary 6" RGBAI light. Captures locked decisions,
    measured driver rails (36.63V CC + 4.7V logic), the current-steering
    tunable-white topology (65K-/27K- returns), addressable outer ring,
    Phase 0 measurement gate, and the KiCad -> JLCPCB deliverable workflow.
2026-08-01 docs: implementation plan for brain replacement board
    Phased hardware plan (measurement gate -> calcs/part-selection ->
    schematic net tables -> KiCad schematic/layout -> JLCPCB fab outputs ->
    firmware pin remap -> per-board bring-up). Each task tagged USER/CLAUDE/
    BOTH to reflect who takes physical vs design actions.
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2026-08-01 docs(phase0): identify outer ring (62px RGBIC)
    Outer ring = 5V 3535 addressable RGBIC, 62 pixels, 3-wire VCC/DIN/GND;
    CN1.DIM = DIN. Flags two firmware fixes: count 36->62 and color format
    RGBW->24-bit RGB. Board hardware unaffected.
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2026-08-01 feat(hw): Task 1.4 pin assignments + strapping fix
    ESP32-H2 strapping = GPIO2/3/8/9/25. Current firmware CW=GPIO2/WW=GPIO3
    land on strapping pins; move to GPIO4/GPIO5 on the new board. Data stays
    GPIO11, BOOT=GPIO9, USB=GPIO26/27. Firmware pin remap noted for Phase 5.
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2026-08-01 feat(hw): adopt user layout + fix support-part locality
    User's placement (module top-left/antenna off left edge, J1 lower-left,
    J2 right, USB bottom) adopted as script baseline. Relocated only the
    electrically-bound parts: module decoupling to 3V3 pad, USB ESD + CC
    pulldowns to the connector, LDO caps to U2 pins, buffer cap to U3,
    4V7 bulk to Q3/J2, EN RC near EN pad. DRC: 0 violations.
    [lumary-brain.kicad_pcb]
2026-08-01 feat(hw): net classes + GND planes on all 4 layers
    Project file adds Power (0.5mm) / Default (0.25mm) net classes. Script
    now pours GND on F/B + solid planes on In1/In2 (inset 0.6mm, solid pad
    connections for reflow, NPTH keepouts at USB pegs). Antenna region
    correctly excluded from fill by module rule area. DRC: 0 violations;
    airwires 110 -> 49 (signals only).
    [lumary-brain.kicad_pcb]
2026-08-01 feat(hw): rounded board ends matching case (18mm arcs)
    Outline redrawn: straight top/bottom + single 18mm-radius arc each end
    (sagitta ~9.1mm -> ~45mm straight section, matches user's ~44mm
    measurement). Zone outlines follow the shape with radial 0.6mm inset.
    Left cluster (U1/J1/SWs/caps/D3) shifted to clear the deeper corner
    cuts and the antenna keepout. DRC: 0 electrical violations (2 waivable
    module-silk-at-edge warnings).
    [lumary-brain.kicad_pcb]
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2026-08-01 feat(hw): board fully routed, DRC clean
    User hand-routed all 49 signal/power airwires; script pass refilled
    zones, added 7 GND stitching vias for isolated top-pour islands, and
    closed the LDO_IN CE-pin gap (detour below the pad row after a first
    attempt shorted across U2's GND pad). Final: 0 violations, 0 unconnected.
    NOTE: lumary-brain.kicad_pcb is now the source of truth (contains manual
    routing); build_board.py regenerates placement only and would DISCARD
    routing if re-run.
    [lumary-brain.kicad_pcb]
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2026-08-01 fix(hw): resolve BOM LCSC numbers from JLC matching pass
    B5819W=C8598 (Basic), SMAJ5.0A=C113952, buffer=SN74AHCT1G125DBVR C7484
    (SOT-23-5; stocked SE-7 variant is SC-70 = wrong footprint), JST-PH
    right-angle=C157929. Open: MOSFETs, PicoBlade, tact switches, module
    variant stock.
    [bom-jlc.csv]
2026-08-01 feat(fw): rev A pins + 62-pixel RGB ring (Phase 5)
    Phase 0 found the outer ring is 62 pixels of 24-bit RGBIC, not the 36
    RGBW the firmware assumed, and rev A moves the white PWM off ESP32-H2
    strapping pins.
    - pins: CW GPIO2->4, WW GPIO3->5 (GPIO2/3 are strapping pins; MOSFET
    gate pulldowns would hold them low at reset). Ring data stays GPIO11.
    - ring: 36->62 px, CRGBW->CRGB (24-bit), buffer 482->648 B (558 data +
    90 zero bytes = ~300us latch, safe for WS2812B-V5's >280us).
    - extract the NZR bit encoder to src/pixel_encode.h, free of ESP-IDF
    headers, and cover it with 11 host tests (GRB order, reset padding,
    short-buffer safety, colour math).
    - effects: nightlight mixes warm white fr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
    [config.h, led_driver.cpp, main.cpp]
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2026-08-01 feat(fw): Zigbee light endpoint + state mapping layer
    Adds the Zigbee layer as two pieces so the decision-making is testable:
    - src/light_state.h (host-tested, no ESP-IDF): translates Zigbee
    on/off + level + RGB + scene into the EffectParams the engine renders.
    Colour mode vs scene mode, RGB->HSV on the same 43/sextant scale as
    hsv_to_rgb, scene cycling with wrap, and level dimming that leaves a
    scene untouched at 255. 18 new tests.
    - src/zigbee_light.{h,cpp}: thin adapter over ZigbeeColorDimmableLight.
    Joins as ZIGBEE_ROUTER (mains-powered fixtures should extend the mesh)
    and is non-fatal on failure so the light still works with no network.
    Tracks the last RGB to tell a colou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
    [main.cpp]
2026-08-01 fix(hw): restore Power net class; document rev A trace widths
    KiCad discarded the Power net class and its netclass patterns when it
    rewrote lumary-brain.kicad_pro on first open, so every net on rev A
    routed at the 0.2mm Default instead of the intended 0.5mm -- and the
    shipped Gerbers were generated from that board. Class restored for rev B.
    Analysed what actually shipped (IPC-2221, 1oz external, 0.74A @10C rise
    for 0.2mm):
    - +36V / CW_RET / WW_RET at 380mA: 2.2C rise. Fine, and the CC driver
    fixes that current so it cannot grow.
    - +4V7_IN at MAX_BRIGHTNESS 24 (~0.55A): 5.0C rise. Fine.
    - +4V7_IN at full brightness (~1.5A): 49C rise. Not acceptable.
    So MAX_BRIGHTNESS is a hardware limit o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
    [main.cpp]
2026-08-01 chore: trial framework upgrade 3.1.0 -> 3.3.11 (blocked)
    Bumps the pioarduino platform to 55.03.311 (Arduino 3.3.11 / IDF 5.5.5)
    and records the findings.
    Verified from arduino-esp32@master that the upgrade closes both Zigbee
    gaps: native colour temperature (onLightChangeTemp,
    setLightColorTemperature, ZIGBEE_COLOR_MODE_TEMPERATURE) and a Zigbee
    OTA client (addOTAClient, requestOTAUpdate, zbOTAState). It also adds
    onLightChangeHsv, which would let light_state.h drop its RGB->HSV step.
    The build does not complete on this machine: package extraction fails on
    a ~262-char path inside the bundled Matter headers, and Windows
    LongPathsEnabled is 0 (limit 260). Not a code problem. Fix is either
    en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
2026-08-01 feat(fw): native colour temperature + Zigbee OTA
    Uses the APIs the 3.3.11 upgrade unlocked.
    Colour temperature:
    - light_state.h gains mireds_to_cct() and light_state_set_cct(), mapping
    the cluster's mireds (1e6/K, larger = warmer) onto the CW/WW mix over
    the fixture's real range: 370 mired (2700K, WW) .. 154 (6500K, CW).
    6 new host tests incl. clamping outside the range.
    - zigbee_light advertises COLOR_TEMP capability and publishes that range,
    then routes onLightChangeTemp straight to the white string. HA now gets
    a real white slider instead of a colour picker.
    - rgb_to_cct is kept as a fallback for coordinators that send white as an
    RGB colour rather than a CCT command.
    Zigbee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
    [config.h, main.cpp]
2026-08-10 docs: design spec for through-hole board (lumary-brain-tht)
    Second controller board with identical functionality to rev A but built
    entirely from through-hole parts, so it can be hand-assembled without SMD
    skills (~$11/board, no assembly fee, vs ~$20 + $25 setup for rev A PCBA).
    Key decisions: ESP32-H2 Super Mini on headers as the brain (the only
    practical way to get an H2 into a THT design -- and it absorbs the LDO,
    USB-C, ESD array and both buttons); same Lumary 36.63V CC + 4.7V rails;
    same PicoBlade/JST-PH connectors so the fixture harness still plugs
    straight in; enclosure fit dropped, freeing the layout; 2-layer.
    Verified the Super Mini exposes GPIO 4/5/11 -- the exact pins rev A uses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
2026-08-15 fix(fw): use zigbee_zczr partition table
    First boot of the rev A hardware panic-looped 41 times in 35 seconds on
    "ZB_ESP_NVRAM: Failed to find zb_storage partition" (zb_esp_nvram.c:84),
    resetting via SW_CPU each time.
    min_spiffs.csv provides neither zb_storage nor zb_fct, which the ZBOSS
    stack asserts on at startup. zigbee_zczr.csv carries both, matches the
    ZIGBEE_MODE_ZCZR build, and keeps app0/app1 so Zigbee OTA still works.
    Latent since bc4ea2f upgraded the framework to 3.3.11 -- that commit was
    only ever verified to compile, never run on hardware.
    Costs app space: 62.1% of 0x140000 rather than 41.4% of 0x1E0000.
2026-08-15 fix(fw): correct ring wire order and NZR bit timing
    Two defects found driving the real strip for the first time.
    Wire order: commanding pure red lit the ring green. The strip latches
    red first -- it is RGB, not the WS2812/SK6812-family GRB the encoder
    defaulted to. Fixed with -DPIXEL_WIRE_ORDER_GRB=0.
    Bit timing: with the colour fixed, ~11% of frames showed a single pixel
    in clean green or blue at a random position. A two-channel logic capture
    probing J2.6 and the ring's DIN together found zero bit differences
    across 470,208 bits and exactly 1488 bits in all 316 frames, clearing
    the wiring, the encoder and the framing, and leaving pulse width.
    3 SPI bits at 2.4 MHz gives T0H 417 ns -- nom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
    [config.h, led_driver.cpp]
2026-08-15 docs: rev A bring-up results; measure ring current budget
    Closes two Phase 0 unknowns with hardware measurements.
    P0.3 (CN1 pin order): stock silkscreen reads V+ CW- WW- 5V+ GND DIM, six
    signals matching rev A J2 pins 1-6. There is no separate +A/-A pair --
    the ring shares 5V+/GND and takes data on DIM.
    P0.4 (ring protocol): 62 px, 24-bit, RGB order, 16.00 ms frame period,
    confirmed by logic capture. Exact part still unmarked but its T0H
    tolerance rules out plain WS2812B.
    R3 (ring current budget), measured on the 4.7 V rail with the module on
    USB so its draw is excluded:
    62 px dark, quiescent 0.040 A
    62 px at (24,14,14), the cap 0.122 A
    -> extrapolated full white/full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
    [main.cpp]
2026-08-15 docs(research): preserve the ring logic capture behind the timing fix
    Two-channel Saleae capture probing J2.6 and the ring's DIN together,
    24 MS/s, 5.06 s, taken while the ring was visibly corrupting. This is the
    evidence that cleared the wiring, the encoder and the framing and left
    pulse width as the only candidate, so it is worth keeping alongside the
    fix in 0a83347.
    Captured with the FAILING 3-bit/2.4 MHz encoding, not the shipped 4-bit
    one -- the companion note says so up front, since a raw CSV is easy to
    mistake for a reference of correct timing.
    Also records the sampling-skew trap: the export logs a row whenever
    either channel changes, so ~146k rows show a 42 ns disagreement that is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
2026-08-15 fix(fw): remove the rev A brightness ceiling
    MAX_BRIGHTNESS clamped every effect to 24/255 to protect rev A's 0.2 mm
    +4V7 traces. Because the clamp sat in main.cpp ahead of the effect call,
    it also throttled the inner white string to ~9% duty -- the fixture's
    main light source, whose current flows 36 V -> LEDs -> CW-/WW- -> Q1/Q2
    -> GND and never touches that trace. The light could not produce more
    than a tenth of its output.
    Bench measurement retired the premise the ceiling rested on: the ring
    draws 0.48 A at full brightness against a 0.74 A rating, cold or warm,
    with no measurable trace heating across three runs -- 1.2 A had been
    assumed. The white path ran 15 min at 100% duty with Q2 at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
    [main.cpp]
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2026-08-15 feat(fw): select effects over a manufacturer-specific cluster
    All eight effects rendered correctly on hardware but none could be
    selected: next_scene/prev_scene had no callers, and any colour command
    set MODE_COLOR permanently, so the first HA command after boot made every
    effect unreachable until power-cycle.
    Adds cluster 0xFC00 on the light endpoint, carrying a read-only u8
    attribute (the effect currently running) and a set-effect command.
    Selection arrives as a COMMAND, not an attribute write, and that is
    forced rather than chosen: ZigbeeColorDimmableLight declares
    zbAttributeSet private, so a subclass may override it but cannot
    delegate back to it. Intercepting attribute writes would h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
    [config.h]
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2026-08-17 feat(z2m): expose the effects as the light's native HA effect list
    The eight effects were reachable only through a separate `effect_select`
    select entity. Renaming the expose to `effect` folds them into the light
    entity itself: Z2M's Home Assistant discovery collects every enum expose
    named `effect` and populates the light's `effect_list`, which is what puts
    the dropdown in the light card and makes `light.turn_on(effect:)`, HA scene
    capture and voice selection work. This is what the design spec asked for;
    the implementation had deviated from it.
    The reason it deviated -- avoiding a collision with the Identify
    trigger-effects -- turned out to be wrong twice over. `m.light()` defaults
    to `eff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
    [config.h]
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2026-08-17 fix: stop scale8's >>8 from zeroing the gamma floor on the ring
    Critical: gamma8() returns a multiplier, and scale_brightness() composed
    it through color.h's scale8(val, scale) = (val * scale) >> 8. kGamma8[b]
    == 1 for b in 1..13, and (255 * 1) >> 8 == 0, so every channel at HA
    brightness 1-13 composed to zero -- the table's max(1, ...) floor never
    reached the LED. First light moved from brightness 2 (pre-branch, linear)
    to brightness 14 (as committed) -- the dead zone this feature exists to
    remove got wider. fx_nightlight had the identical exposure via
    warm_white()'s scale8.
    Fixed by composing with scale_by_255(v, s) = (v * s) / 255 instead of
    the >> 8 shift in scale_brightness_gamma, and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
    [brightness.h, gen-gamma-tables.py, led_driver.cpp]
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2026-08-18 fix: bound the USB CDC wait so the fixture boots without a PC attached
    setup() opened with an unbounded `while (!Serial) delay(10)`. The build sets
    ARDUINO_USB_CDC_ON_BOOT=1, so Serial is the USB CDC and never becomes true
    unless a USB host enumerates it -- meaning setup() never returned on a fixture
    running from mains alone.
    Everything after that line was dead: led_driver_init() never configured the
    white PWM GPIO, so the L-SD8E1 saw no gating signal and drove the downlight
    full on, and zigbee_light_init() never started the radio, so the device was
    unreachable. loop() never ran either, leaving the ring dark.
    Found on the bench 2026-08-18 -- this was the first cold boot the board had
    ever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
    [main.cpp]
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2026-08-18 docs: Z2M needs an OTA index, not just a file in a folder
    Third correction to this README's OTA documentation today. 'Drop the .ota image
    in data/ota/' does nothing on its own -- Z2M reads an index describing the
    image, located by ota.zigbee_ota_override_index_location. Without it the update
    entity exists and the update fails with 'No image currently available', which
    looks like a broken OTA client rather than missing configuration.
    Adds scripts/gen-ota-index.py, which reads the manufacturer code, image type,
    file version and header string out of the image header rather than taking them
    as arguments -- an index that disagrees with its image produces exactly the same
    opaque error.
    Also docu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
    [gen-ota-index.py]
2026-08-18 fix: OTA index url resolves against the data dir, not the index's folder
    The generated url was a bare filename, so Z2M looked for the image at
    /config/zigbee2mqtt/<name> while it actually sat in /config/zigbee2mqtt/ota/.
    gen-ota-index.py now prefixes 'ota/' by default, with --url-prefix to override.
    Worth recording how this presented, because it does not look like a path
    problem: ota_update/check reads index metadata only, so it reported
    update_available: true and HA offered the update. Only ota_update/update opens
    the file, and it surfaces the failure as 'No image currently available' -- the
    identical message to having no index at all. The ENOENT and the exact path
    tried appear only in Z2M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
    [gen-ota-index.py]
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2026-08-19 fix: actually arm WDT_TIMEOUT_MS as a watchdog
    The constant was defined in config.h but nothing ever called
    esp_task_wdt_*, so it did nothing. Zigbee.begin() has hung outright before
    during bring-up (bisected 2026-08-15), and there is no OTA/BLE recovery
    fallback for a fixture already in the ceiling -- only physical USB access.
    Arms the TWDT in setup() (falling back to esp_task_wdt_reconfigure if the
    Arduino core already started one), subscribes the setup/loop task, and
    feeds it once per loop() iteration. Boot-verified clean at the bench; not
    yet verified to actually recover from a real hang.
    Claude-Session: https://claude.ai/code/sess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
    [main.cpp]
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2026-09-18 docs: bench OTA timing -- stalls are fixed retry timers, not load or Wi-Fi
    A second rev A board (Test Unit 2), USB-powered a few feet from the
    coordinator, OTAs at exactly the ceiling's rate: 30.5 B/s. Placement is
    ruled out.
    The device's own per-block log (millisecond device clock) shows every
    exchange either succeeds in ~270 ms or fails and waits out a fixed ~3.27 s
    timer, up to three times, plus one 48.29 s timeout per session. ~30% of
    exchanges fail and cost ~90% of the time. Lined up against Z2M's log, the
    coordinator never hears the request until the attempt that works.
    Two hypotheses tested one at a time and refuted, then reverted:
    - pausing the render loop during OTA (onOTAStateCha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
    [serial-log.py]
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2026-09-19 fix: configure the white PWM before the USB wait (D)
    led_driver_init() only touches SPI2/LEDC GPIO config from config.h, so it
    needs nothing setup() previously ran first (scene_store_init(), the
    watchdog). Moving it directly after Serial.begin(115200) sets the white
    duty to 0 before the up-to-1 s bounded USB wait, so a restart on mains --
    including an OTA recovery restart -- holds the downlight dark instead of
    letting the L-SD8E1 run it full on until the wait ends. Only the
    ROM/bootloader window (~0.3 s) remains ungated.
    [main.cpp]
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2026-09-22 wip: rev B board -- J2 placed, outline shrunk 1mm, routing outstanding
    Checkpoint so the KiCad work is in git. The board gate is GREEN on structure --
    outline 62.3 x 30.3, J2 footprint, position and all seven pad nets, plus C1 and
    Q3 -- and RED on two nets: CW_RET and WW_RET have no routed segments at all,
    which is the work still to do.
    The outline shrank 0.5mm per side at the user's request because rev A fits the
    housing too tightly. That supersedes the spec's 'outline unchanged' item; J2 is
    the limiting part and still clears by 1.534mm of copper.
    Board-local coordinates all read 0.5mm lower now: the checker takes its origin
    from the outline bbox, so the frame moved, not the parts.
    Co-Au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
    [lumary-brain.kicad_pcb]
2026-09-22 feat: rev B board -- the stock harness now mates, and it is routed
    J2 is a JST ZH 1.5mm side-entry connector at board-local (56.15, 15.15) rot 90,
    carrying +36V, CW_RET, WW_RET, +4V7, GND and RING_DATA on pads 1-6 with pad 7
    unpopulated. C1 and Q3 moved to clear its courtyard, and everything the swap
    disturbed is re-routed.
    kicad-cli DRC: 0 violations, 0 unconnected items. The +36V stub that ran to the
    old J2 position -- which shorted 36V onto the CW_RET pin -- is gone.
    C1 is recorded at its as-placed (50.8926, 20.45); it drifted 0.05mm in Y during
    routing, which is harmless and now expected by the checker rather than silently
    tolerated.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
    [lumary-brain.kicad_pcb]
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2026-09-22 docs: the CN1 mismatch is closed by rev B
    J2 is a JST ZH 1.5mm side-entry part across the BOMs, the footprint table and
    the net map, and P0.1's open "physical 1..7 order" is resolved by the
    footprint. Also corrects the design spec's outline claim -- rev A's 63.3 x
    31.3mm outline fit the housing too tightly, so the board was shrunk 0.5mm/side
    to 62.3 x 30.3mm on 2026-09-22 (the stock housing envelope itself is
    unchanged). The calcs.md trace-width write-up is deliberately not included
    here; it depends on power-track widening still in progress in KiCad and will
    be handled separately.
    [bom-jlc.csv, bom.csv]
2026-09-22 fix: J2 pin-1 table was rev A geometry mislabeled as rev B
    Task 6 review caught it: the pad y-values written into schematic-nets.md,
    phase0-measurements.md and the design spec's Sec5 were rev A's pre-shrink
    frame (x 59.50, pad1 y 19.00 .. pad7 y 11.50), not the as-built rev B
    footprint. Verified against lumary-brain.kicad_pcb directly (J2's pad "at"
    offsets rotated through the footprint's 90 degree placement): rev B has all
    seven pads at board-local x 54.500, pitch 1.5mm, pad1 (+36V) bottom-most at y
    19.650, pad4 (+4V7) the centre pad at y 15.150, pad7 (NC) top-most at y
    10.650, span 9.000mm; MP tabs at x 58.200, y 21.600/8.700. The rev A numbers
    stay, explicitly labelled as pre-shrink prove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
    [bom.csv]
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2026-09-22 feat: power widening where it pays, 2-layer stackup, silkscreen
    Widening: +4V7 and +4V7_IN keep 0.5mm -- they are the only nets that can
    exceed the 0.74A a 0.2mm track supports. +36V, CW_RET and WW_RET carry 380mA
    fixed by the CC driver; +3V3, VBUS and LDO_IN are module rails. All six went
    back to 0.2mm, which removed 25 of the 28 clearance violations the blanket
    widening caused.
    Three short necks stay at 0.2mm, recorded by segment id: two on +4V7 where it
    threads between C7's ground pad and RING_BUF_OUT, and a 1.5mm stub on +4V7_IN
    past J3's shield pad. Be clear about what that means: the ring supply path's
    limit is still ~0.74A. The widening did not raise it -- it cut about 60
    milliohms,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
    [lumary-brain.kicad_pcb]
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2026-09-25 release: rev B fully JLC-assembled; fab package matches the saved board
    BOM: every LCSC number taken from the rev A JLC order (W2026080202192894),
    which JLC fully assembled -- those picks were never recorded in the repo.
    The one change is J2 -> C5118704, genuine JST S7B-ZR-SM4A-TF(LF)(SN),
    Extended, SMT-assemblable. The spec's "keep J2 hand-fit" decision is marked
    superseded.
    Gerbers/zip regenerated: the board was re-saved after the previous release
    commit and its GND refill near the bottom-left corner differed from the
    committed copper. CPL unchanged. DRC (refill-zones): 0 errors.
    Still gated on the 1:1 print check against the physical connector.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
    [bom-jlc.csv, bom.csv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]
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2026-09-25 fix(bom): U1 -> ESP32-H2-MINI-1-H4S; the -N4 is discontinued
    LCSC lists ESP32-H2-MINI-1-N4 (C18203134) as discontinued, so JLC cannot
    source it for rev B. The H4S (C47967030) is its successor in the same
    16.6x13.2 MINI-1 package: 4 MB flash, on-board PCB antenna, chip rev v1.2,
    105 C rated. Firmware is built on ESP-IDF 5.5, which supports H2 v1.2.
    Pre-ordered through JLC like rev A's module.
    [bom-jlc.csv, bom.csv]
